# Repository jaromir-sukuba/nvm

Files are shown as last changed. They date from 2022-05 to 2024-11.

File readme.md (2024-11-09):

***Please note this nanovoltmeter design was superseded by a new and better design, which will go public in [this Github repository](https://github.com/jaromir-sukuba/nvm2). Soon(TM)***

## What is in this repository?
Here is the complete set of design files, manufacturing data, source files, test results and other resources that I used in the process of building a nanovoltmeter. This process was not a coincidence, but a response to the nanovoltmeter challenge by TiN on [his website](https://xdevs.com/article/nvm_comp/)
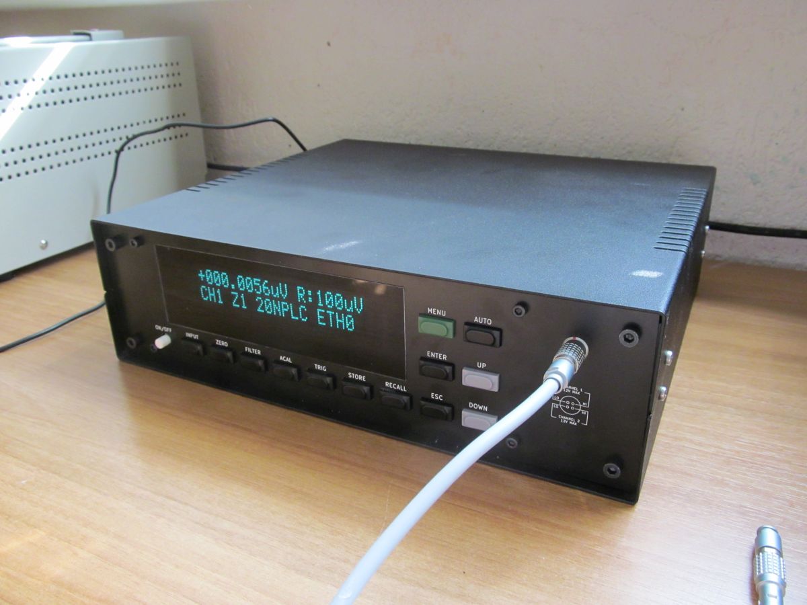
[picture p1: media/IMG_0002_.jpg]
Outside view


## What is a nanovoltmeter and what is it good for?
Well, a nanovoltmeter is a voltmeter that has the sensitivity, noise and stability to resolve voltages down to the nanovolt. While many multimeters do have quite sensitive low voltage ranges, the resolution (least significant digit) is usually in the order of hundreds of nanovolts - and value of this last digit is often diminished by the noise and nonlinearity of the meter. So, for proper low signal measurements, having a higher sensitivity is mandatory.
Measurement of such low voltages is useful for many applications, for example resolving small voltage differences in various differential and bridge circuits and the measurement of very small resistances - with an appropriate current source.
Commercial nanovoltmeters do exist, like the Keithley model 2182A or Keysight 34420A, but with a hefty price tag, so a DIY design definitely has its place.

## xDevs challenge
While I have been tinkering with DIY test and measurement tools for a while now, I never had an impulse to discover the nanovolt world. Such a trigger happened on September 2nd, 2021, when TiN from xdevs site launched the [nanovolt challenge](https://xdevs.com/article/nvm_comp/). In nutshell, it called for the design of an open-source nanovoltmeter, with parameters comparable to commercial designs and a timeframe of 256 days. That is a non-trivial task, and in my case it was even more so, because I had not only never designed low signal circuits before, but had I never operated a nanovoltmeter. That is quite an unfavorable starting position and jumping into the deep end rather than dipping my toes into the problematics. To ease my mind, I waited a few days to see how others reacted on the [eevblog forum](https://www.eevblog.com/forum/metrology/nanovolt-design-challenge-build-and-show-your-own-nv-meter-in-256-days/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). I can't say that it encouraged me.
On the other hand, I spent a few days researching online sources and studying the service manuals of proven test gear from reputable vendors. Too bad they stopped supplying us with schematics in early 90s of the last century; but even that material was very helpful in understanding both what the requirements are for such a meter, as well as the means to achieve it.

## NVM design, part 1 - design requirements
Armed with new knowledge I started dissecting the challenge requirements. 

> Have local onboard power regulation. Single common DC (+9 to +24 VDC) or 110/220VAC mains input jack is expected.

Okay, I think I can do this. On the other hand, any reasonable mains-powered voltmeter has to have an isolated PSU section which powers the input dividers/amplifiers and ADC, so that the measurement potential could be unrelated to the digital section with all the user and communication IO - which is needed to be earthed or somewhere close to that potential.
This one calls for either DC or AC power, but it could be combined by having a PSU operating from an appropriate DC voltage (12V sounds like a good starting point) and attach a small AC/DC SMPS to provide power from mains.

> Provide DC Voltage measurement ranges ±100 µV or below and include ±1V and ±10VDC range.

This one looks innocent, but having both 10V and 100uV input on the same jacks implies either switching input amplifiers, or inserting a voltage divider into the signal path, preferably through a relay. Some older nanovoltmeters (Keithley model 181) had two different inputs - one for higher ranges, another one with low TEMF connector for sensitive ranges.

> Have at least two user-accessible input channels for signal to be measured.

Oh my, another relay. Relays are good, but may introduce offset errors into signals due to thermal voltages (TEMF, short for Thermal Electromotive Force) generated on the contacts, when the relay heats up from coil power. The voltages may be around a few microvolts down to nanovolts, definitely something to consider in this design. TEMF is the main enemy of the nanovoltmeter and this acronym will be used in following text a few more times.

> Have low-thermal connection interface to minimize thermal EMF parasitic errors.

TEMF again, I told you so.   
  
> Provide at least 5½-digit resolution for each reading.

Sounds reasonable. I've done long-scale ADC projects like [voltmeter](https://www.eevblog.com/forum/metrology/diy-6-5-digit-voltmeter/) and [voltohmmeter](https://www.eevblog.com/forum/metrology/diy-6-digit-handheld-volohmmeter/msg2978912/#msg2978912) so perhaps I could recycle something and also bring something new to the table. I think commercial sigma-delta A-to-D converters would do the job too, but a DIY ADC definitely has more to it.

> Ability to digitize input DC signal with resolution at least 10 nV and noise better than 30 nV peak to peak over at least 0.1-10 Hz bandwidth.

More numeric requirements, nice. 30nVp-p in 10Hz bandwidth is not a very relaxed requirement - older meters like Keithley model 181 would not cut it, current models so-so.

> Have autozero functionality to correct for static offsets.

That is a logical requirement. I will put in some more effort by introducing autocalibration.

> Have galvanic isolated analog front end, with isolation resistance to earth/chassis better than 10 GΩ.

That is what I proposed earlier, too. 

> Device should have ADC (any type) integrated.

This is likely to frame the project into standalone modus operandi.

> Have good long-term stability and use ovenized DC voltage reference (LM399, LTZ1000 or LTFLU with oven).

I wouldn't think of using anything worse than an LM399 (or ADR1399) anyway.

> Provide RJ45 Ethernet and/or IEEE-488 GPIB interface for communications with external world / external equipment.

Fair point. USB is simpler, though.

> 40W total input power budget (friendly to battery operation for sensitive experiments)

You wouldn't want your nanovoltmeter to consume more than 40W anyway. 40W is quite a bit of heat and it's not easy to dissipate it without introducing more TEMF errors.

> Device should be fully operational as standalone device (e.g. no debuggers or external equipment attached to make it work).

OK, fair.

After a bit of optimization, I came up with this block diagram.
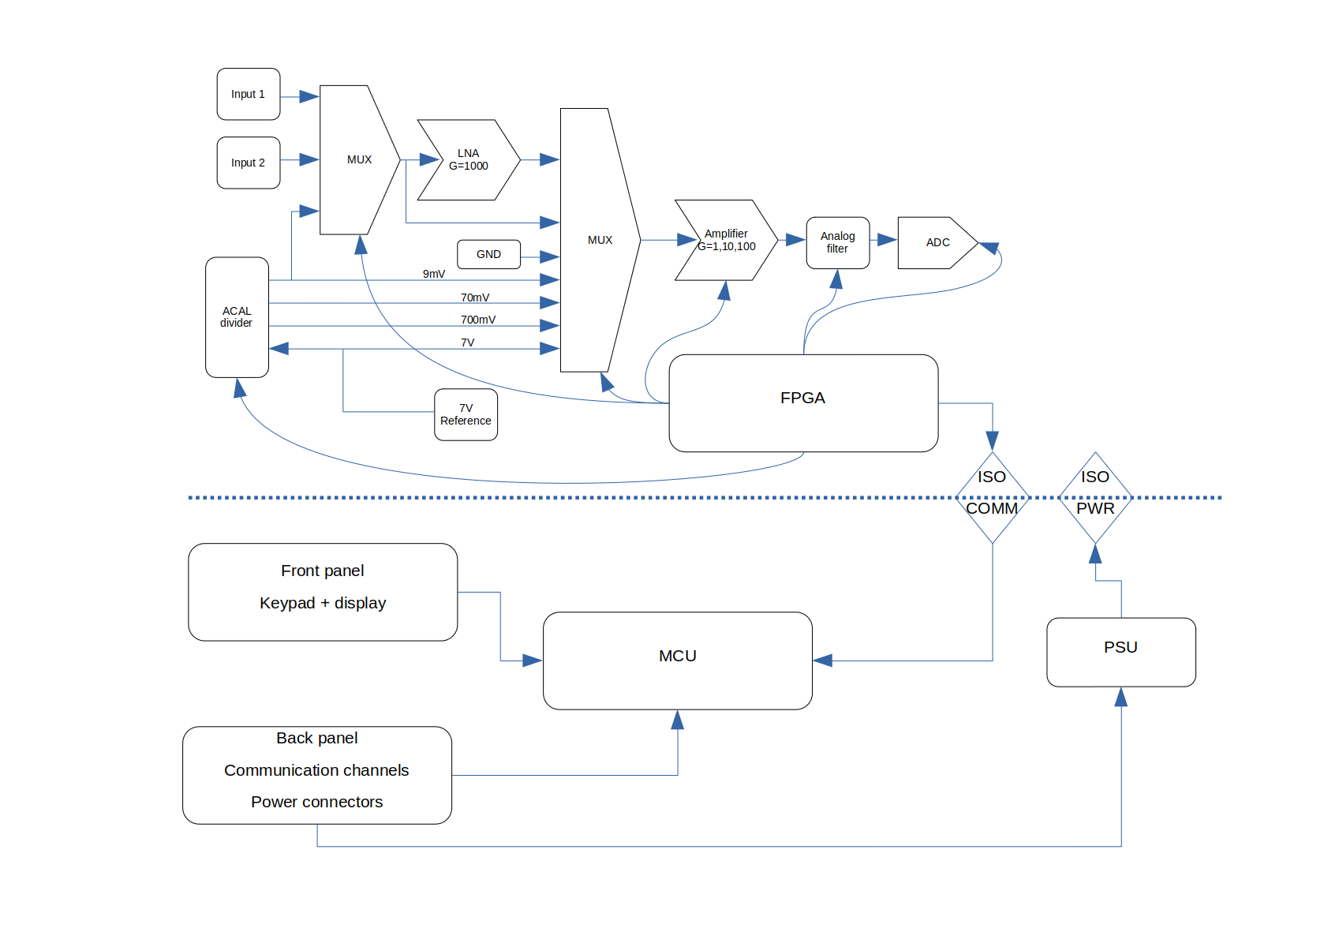
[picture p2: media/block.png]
Block diagram

It's basically done to fit the requirements above, with a few spicy parts I added for extra fun.
Input from either input connection is selected via an input multiplexor. There is also a third input, to be discussed later. This MUX passes the selected channel to a low noise amplifier (LNA) to be amplified and then routed via another MUX into the main amplifier. whose output is brought to the ADC. This ADC has a nominal 10V input range, so that the basic range with LNA is 10mV (10mV x 1000 = 10V). In order to have even more sensitive ranges, the main amplifier has option to switch to x1 (pass-through), x10 and x100 gain, combined into additional 1mV and 100uV ranges. When the LNA is bypassed, the input signal is brought directly to the main amplifier, allowing for 10V, 1V and 100mV ranges, seamlessly covering 100uV to 10V input range. That would make a nanovoltmeter already, but I added two more blocks - first is easy, a low-pass filter (also known as LPF) to cut down noise, especially on sensitive ranges. Another one is an auto-calibration block, which serves to decide the gain of both amplifiers. Ideally, the meter needs only to know its onboard 7V reference voltage and can derive lower ranges automatically without calibration/adjustment and keep it precise after resistors in dividers and amplifier drift due to age or temperature.
The entire upper portion of the circuit is held behind an isolation barrier in order to keep the input terminals separated from the power supply potential - either external DC or mains voltage. The bottom section consists mainly of the PSU and digital circuitry, including user IO and communication channels, like Ethernet and USB. For the added fun factor I also included GPIB as a low priority subproject.

## NVM design, part 2 - divide and conquer

Designing such an instrument, especially on a DIY base, is a lot of pingponging between mechanical and eletrical design. I could imagine how large the thing would be (say, an A4 page size as a footprint) and I knew I had to cram everything inside. Choosing a larger enclosure would give me much more freedom and other benefits (like easier dissipation of device heat, helping fight TEMF), but would be impractically large. Finding an appropriate enclosure wasn't easy - at first I thought of using G756 I used before in my [DIY SMU](https://github.com/jaromir-sukuba/J-SMU), but I preferred metal enclosures here - because of shielding from electrical interference, and with a steel enclosure even a bit of shielding from magnetic interference. Metal also helps with heat dissipation. Finally I settled on the 1EP802825 from Modushop.
That was the right time to take a look at the electrical domain. The Earthy and floating parts (separated by an isolation barrier) have to be physically separated in sub-enclosures (that calls for two PCBs minimum) and in order to have easier debugging and modification of the circuit, I decided to separate the floating part into two PCBs. One would hold FPGA control, the reference and ADC, while another one would consist of both amplifiers and ACAL circuits. Since the enclosure is 80mm tall, there is no problem stacking at least two PCBs on top of each other, via pin headers and metric spacers.
So, two PCBs for the floating part, one for the earthy part. The backside connectors have to be mounted somehow - here I added another PCB. The front panel pushbuttons also needed a PCB for mechanical reasons, that resulted in a total count of 5 PCBs. I named the PCBs with human names and gave them functionality:

**Bart** - I felt like this one will be tricky and there will be problems. Contains LNA, main amplifier, ACAL dividers and MUXes.  
**Homer** - largest PCB, contains FPGA, ADC, references. Closely related to Bart.  
**Lisa** - communication board, back panel PCB  
**Meggie** - simplest PCB, just to hold buttons  
**Marge** - contains PSU to feed all other PCBs, plus digital circuits.  

With the electronics roughly separated into basic blocks, I returned to mechanical design. By the time I finished first sketches of the schematics files, I received the enclosure, so I could start with more practical details. It's much easier to visualize potential problems having the real enclosure in hand compared to studying 3D files (if any, right). For circuit separation I opted for two sheet metal sub-enclosures.
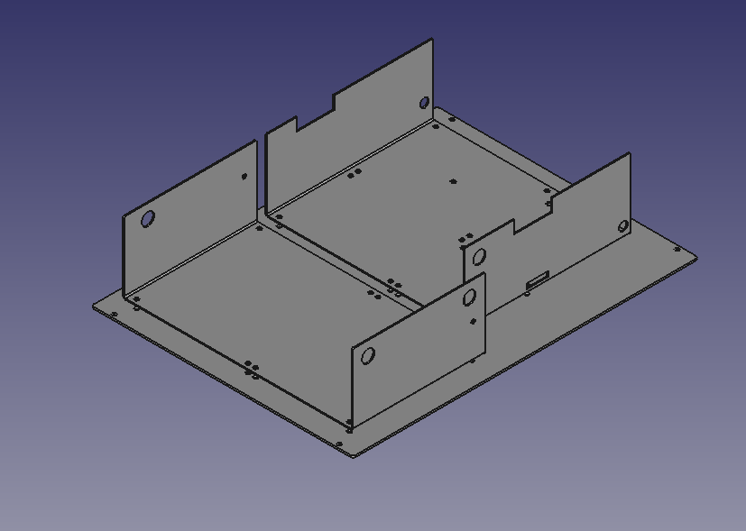
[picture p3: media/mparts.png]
Internal metal parts
. The smaller portion on right holding analog circuitry, the left portion holding earthy circuits - it's somehow shorter, to make room for a backpanel PCB.
I designed a bunch of holes into the enclosures to allow mounting PCBs via metric spacers, and now having physical constraints, I jumped back to PCB design.

## NVM design, part 3 - selected details of circuit operation
In this section I'll discuss a few selected design choices of this instrument.
#### LNA (Bart board)
I went through a few design iterations of the LNA and it took me roughly half of the development time. I tried DC-coupled JFET amplifiers, AC coupled JFET amplifiers in chopper configuration for DC operation as well as paralleling opamps. The parallel configuration brought me the least amount of headache and despite the insane amount of components used, it is not that expensive after all. As best in class, IF3602 JFETs are both expensive and suffer by huge parameter spread, making them quite an expensive solution. There are cheaper JFETs around, but their noise parameters mean more paralleled pieces - with problems they bring, for example binning and matching. More transistors or fewer low noise types also bring more gate capacitance, requiring more circuit support to diminish its influence. Enclosing the amplifier into chopper configuration brings more issues to solve - for example I had to deal with input current and temperature gradients increasing voltage offset. It's very likely that all those problems are solvable with more time and effort and would make an LNA with lower noise and drift than what I have in the current NVM, but at some point I decided to go a different way and built the LNA out of massively parallel off-the-shelf opamp amplifier. Integrated autozero/chopper opamps do have much better temperature stability and input current, so after a bit of searching and comparing I opted for MCP6V51 from Microchip, as the one with very good price/performance ratio. Typical input noise voltage is specified at 210nV in 10Hz bandwidth and I confirmed this experimentally by building a 35 piece opamp board first. 
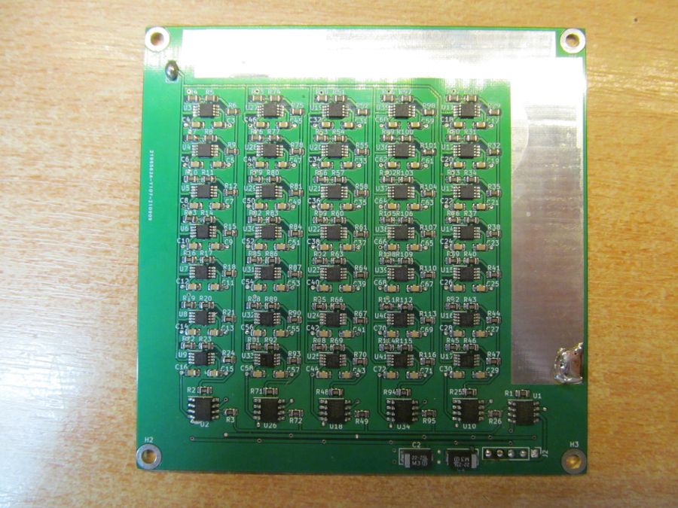
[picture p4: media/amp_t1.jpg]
Amp35

The noise parameters were in good agreement with the datasheet values, that gave me confidence to go this way. As calculated, I need at least 50 MCP6V51s to get under 30nV p-p criteria, so I opted for 100 pieces, in 10x10 matrix, as per the schematic below
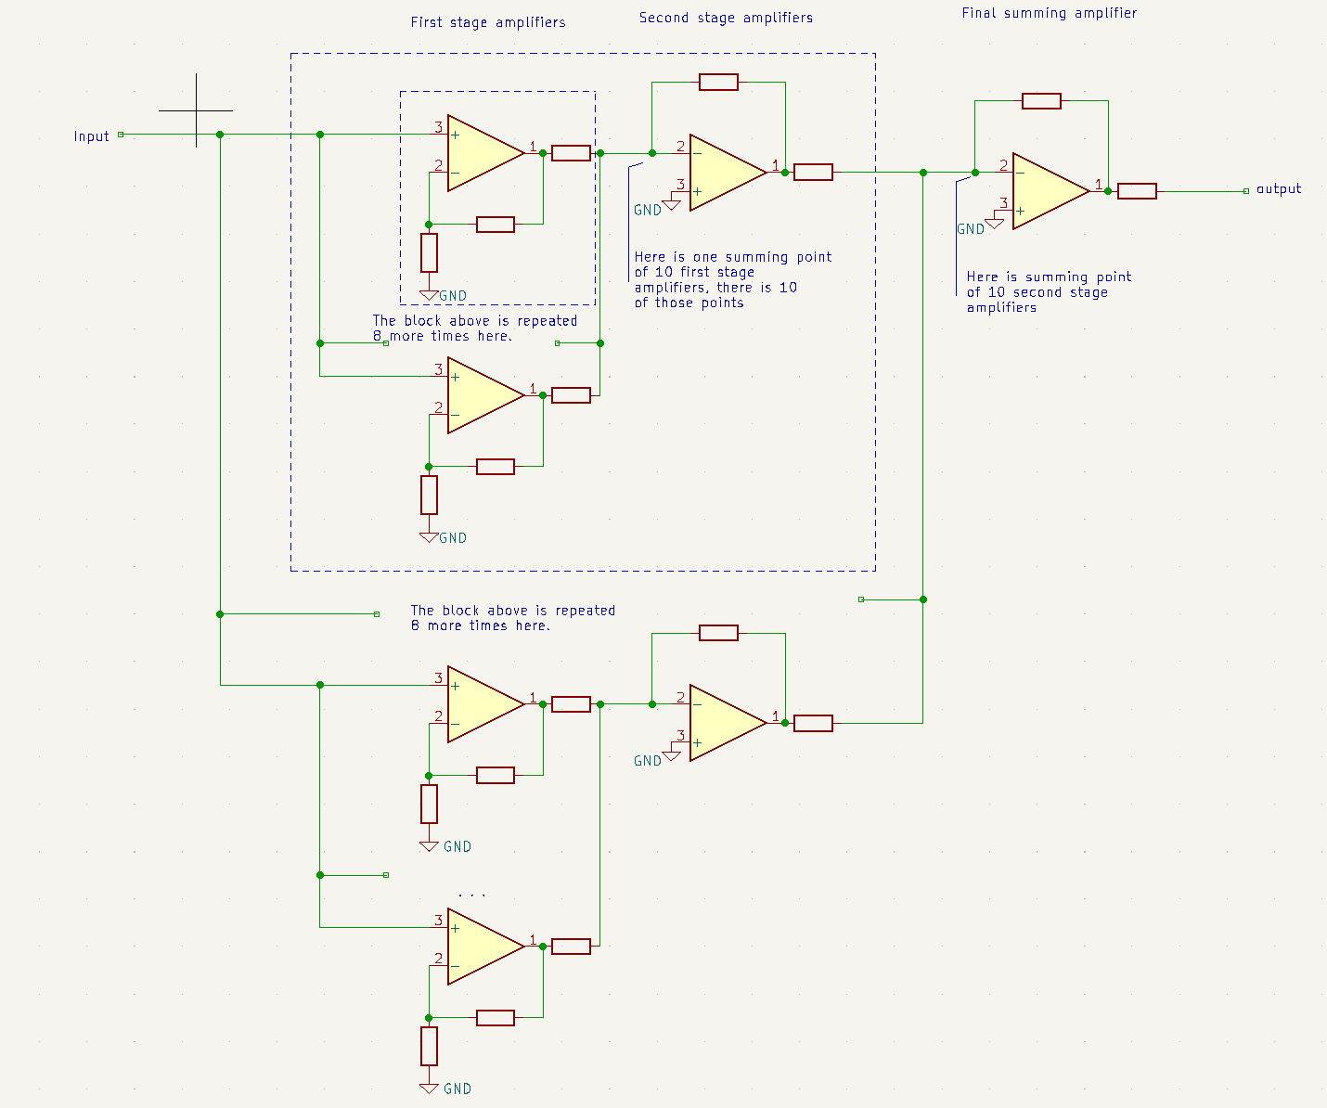
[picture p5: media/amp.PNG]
LNA diagram

Each of the first stage gain blocks (with 10 amplifiers in parallel noninverting configuration) is brought to a second stage summing amplifier, and all 10 of the second stage amplifiers are summed into a third, and final, amplifier, with an overall gain of 1000.
The last stage summing amplifier is also used to inject a voltage to null the offset voltage of LNA. The Bart board has a DAC and its amplifiers (U119 and U120) for this reason. The DAC's second channel is designed to compensate for input current - by injecting a current of opposite sign into the LNA input. I measured the uncompensated current to be around 2nA and in my current hardware the injection resistor isn't fitted on the board. By using this feature, I expect a current well below 100pA.
The LNA injects ground current into the ground net of the circuit, and the current is dependent on input voltage (and therefore output voltage, too). Ground current may cause unwanted voltage shifts between ground potentials of the circuit, especially at high gains. To counteract this ground current, amplifier with U121 is set up to source current of opposite polarity into the ground, into areas where the LNA resides.
The Bart board is 4-layer, with internal layers being ground nets, for both electrical and thermal reasons.

#### ADC (Homer board)
The ADC is of the integrating, charge balancing type with residual integrator voltage reading. SN74LV4053 is used for integrator current steering, the integrator is of the classic two opamp composite type. The FPGA does multiple jobs here, apart from orchestrating actions around the ADC, it also provides an interface between isolated serial link and multiple digital outputs used to switch relays, multiplexer and analog filter and does startup timing for smooth PSU startup.
I measured INL of ADC against a Solartron 7081 as reference. A 0-10V voltage sweep was provided by a DIY precision voltage source (LTZ1000A reference, AD5791B DAC). Measured INL graph:
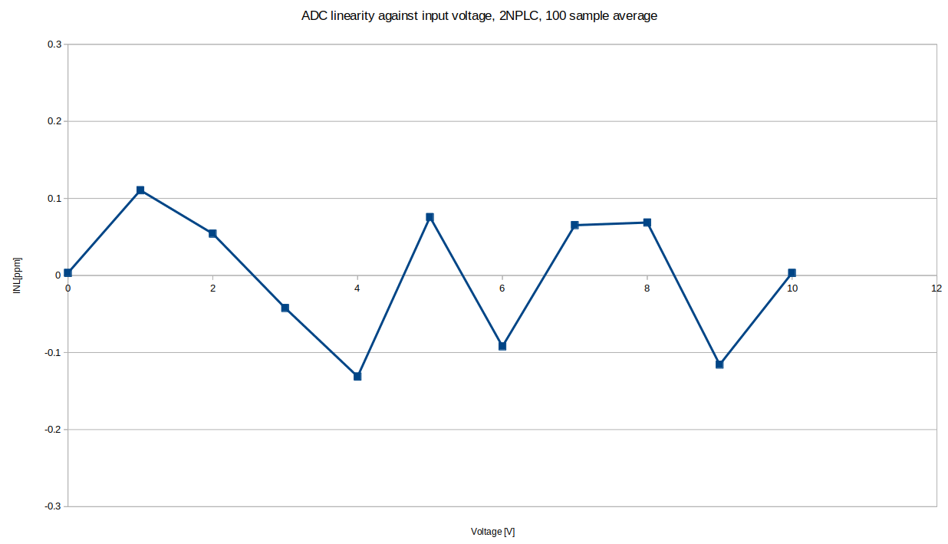
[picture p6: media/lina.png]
ADC INL graph

The INL of this magnitude may not be obviously needed for this application, but I wanted to employ ACAL functionality, where voltage transfer between ranges expects good INL of the ADC, so I was after good linearity and spent some time honing it.

#### PSU (Marge board)
My first idea for the PSU was to use two back-to-back 50Hz transformers. One would provide a few volts (providing first isolation barrier and ground reference) and the second would step it up to the level appropriate for +-16V and 5V DC outputs. Later I expended this idea by using an audio frequency amplifier circuit to feed the second transformer and omitting the first transformer. Using an AF amplifier (fed by an appropriate oscillator) to drive the transformer has a few advantages - the whole circuit could be powered from a single DC voltage and the oscillation frequency can be adjusted to find a good compromise between leakage and efficiency. Using classic linear amplifiers would bring way too much thermal dissipation into the enclosure, so I opted for the cheap and plentiful TPS3116 D-class amplifier. The oscillator signal - either from a local single opamp multivibrator or amplified signal provided by the MCU - is shaped by a series of lowpass filters, so that the amplifier is fed by a low harmonic content signal. Transformer secondary is brought to a fairly standard set of regulators - LM317/337 and 7805.
I measured ground leakage from the isolated PSU section and its efficiency as function of driving frequency.
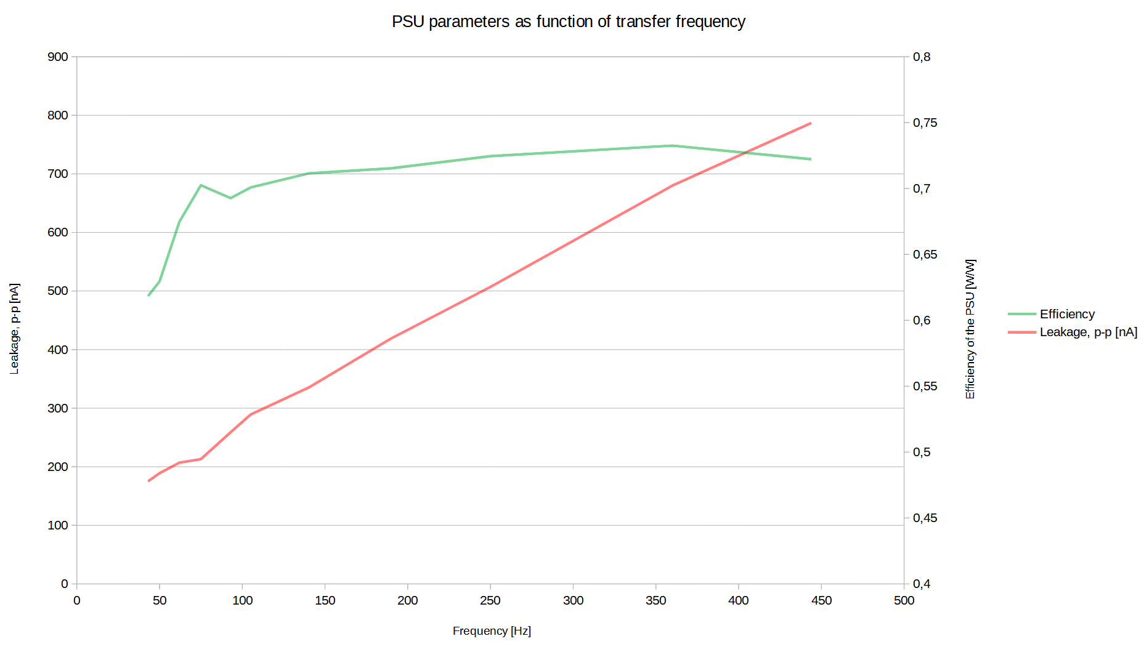
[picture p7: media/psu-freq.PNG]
PSU graph

As per expectations, a lower frequency also brings lower leakage current, but going too low causes efficiency to plummet at some point. I opted for 48Hz, where I measured leakage well below 200nA p-p. At this level, leakage measurement is very sensitive to nearby electric fields and conducted interference. After enclosing the test setup in a shielded box, the measured leakage fell to 40nA p-p, indicating the previous measurement was too pessimistic. I believe even the 40nA figure is pessimistic still and influenced by the shielding setup and the oscilloscope I used. For proper test results I'd need a larger shielded cage and a battery powered oscilloscope, but I didn't want to go that far.
The PSU design brought interesting detail to the game. In case of overload, TPS3116 will turn off the load drive. That sounds innocent, but may be problemtic in this case - because after powerup the reference is cold, so the heater takes a significant amount of current during powerup. To add insult to injury, all decoupling/bulk capacitors are discharged, even more increasing the powerup current spike. The spike causes TPS3116 to shut down for a moment, then it tries to restart the load, ending up in the same large spike, repeating again and again.
To mitigate this issue, two fixes were made:
 - PSU driving starts from higher frequency, slowly (over course of a few seconds) it descends to the final 48Hz value. Voltage on the isolated secondary ramps up much slower, allowing circuits to power up smoothly.  
 - Voltage reference heating current (large current spike when left untreated) and LNA power supply voltage is held off until 10 seconds after FPGA power gets stable, at which point heater current is enbled, and LNA power turns on two seconds later.

## Mechanical parts
While the enclosure is centered around the Modushop enclosure, a few more mechanical parts were needed.

#### Reference cover
This two-part 3D printed component prevents airflows around ADR1399 reference, decreasing its noise somehow.
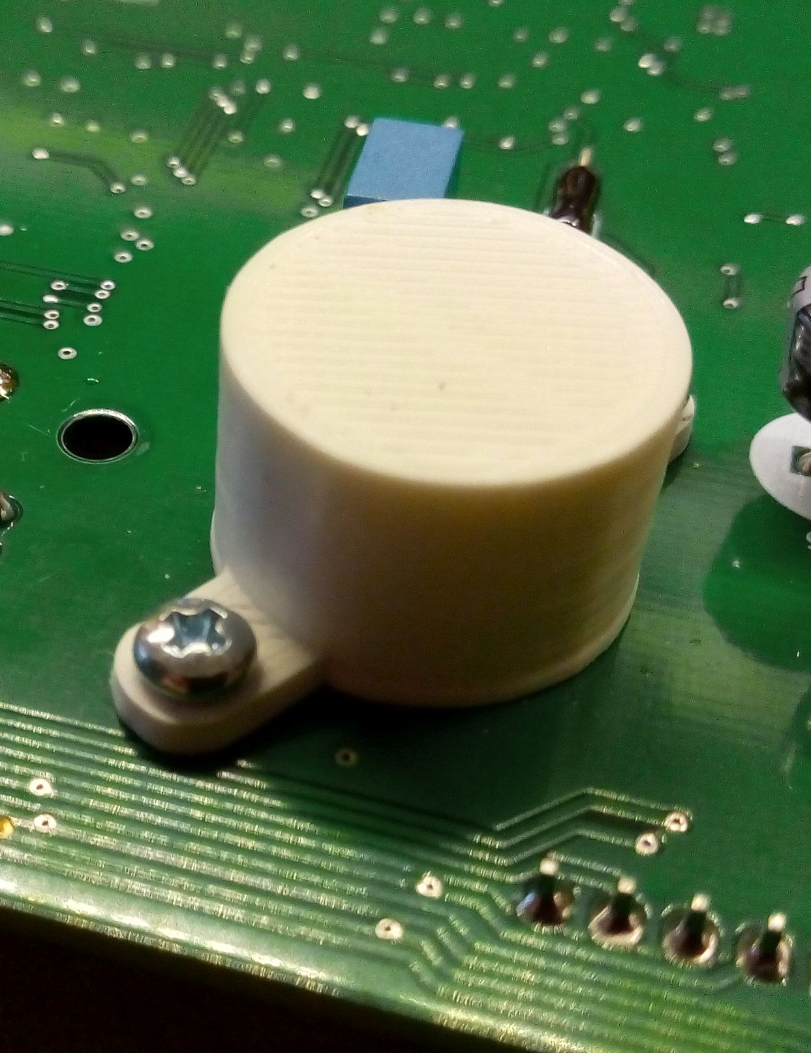
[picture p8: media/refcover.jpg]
Ref cover

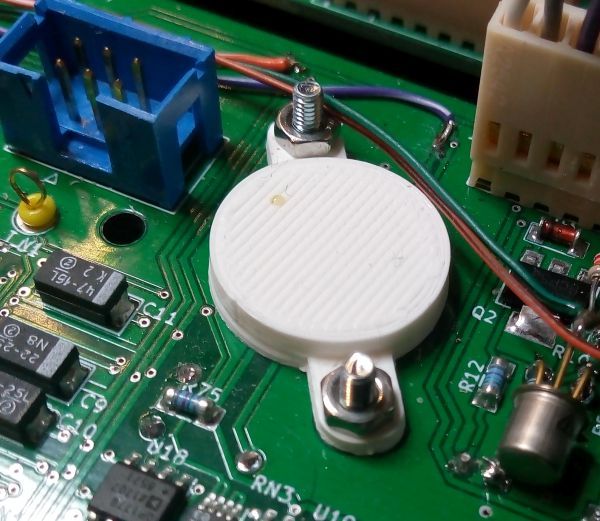
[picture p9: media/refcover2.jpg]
Ref cover


#### Lisa board holder
This 3D printed component keeps Lisa board in its place on back panel.
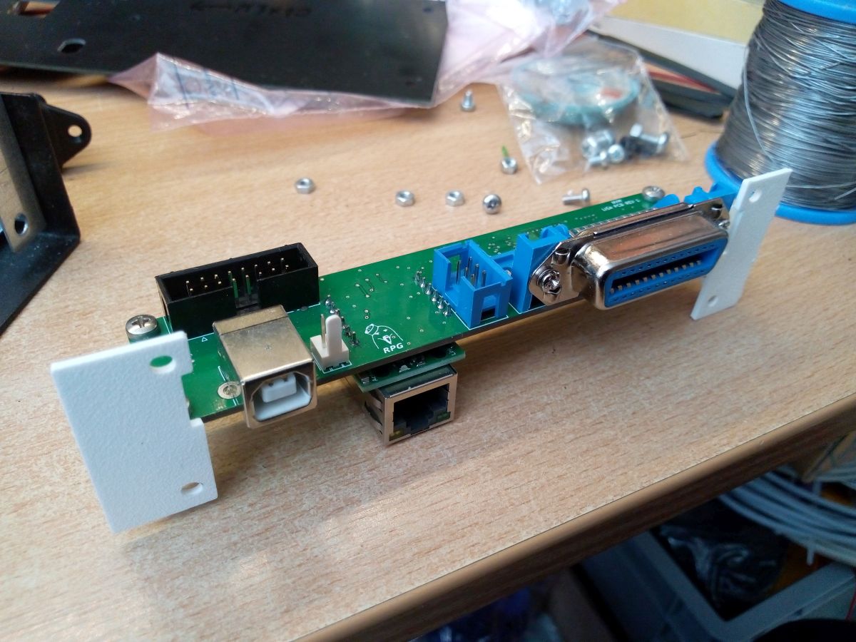
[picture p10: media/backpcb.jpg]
Back holder

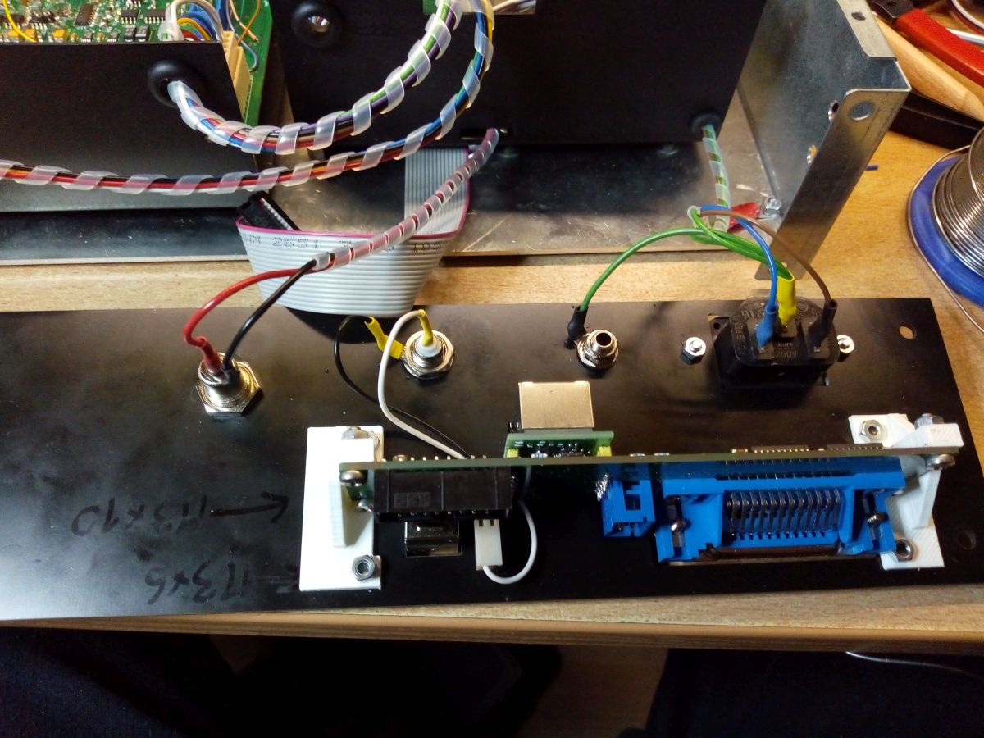
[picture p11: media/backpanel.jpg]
Back panel


#### LNA cover
This 3D printed component provides insulation of LNA board area from airflows.
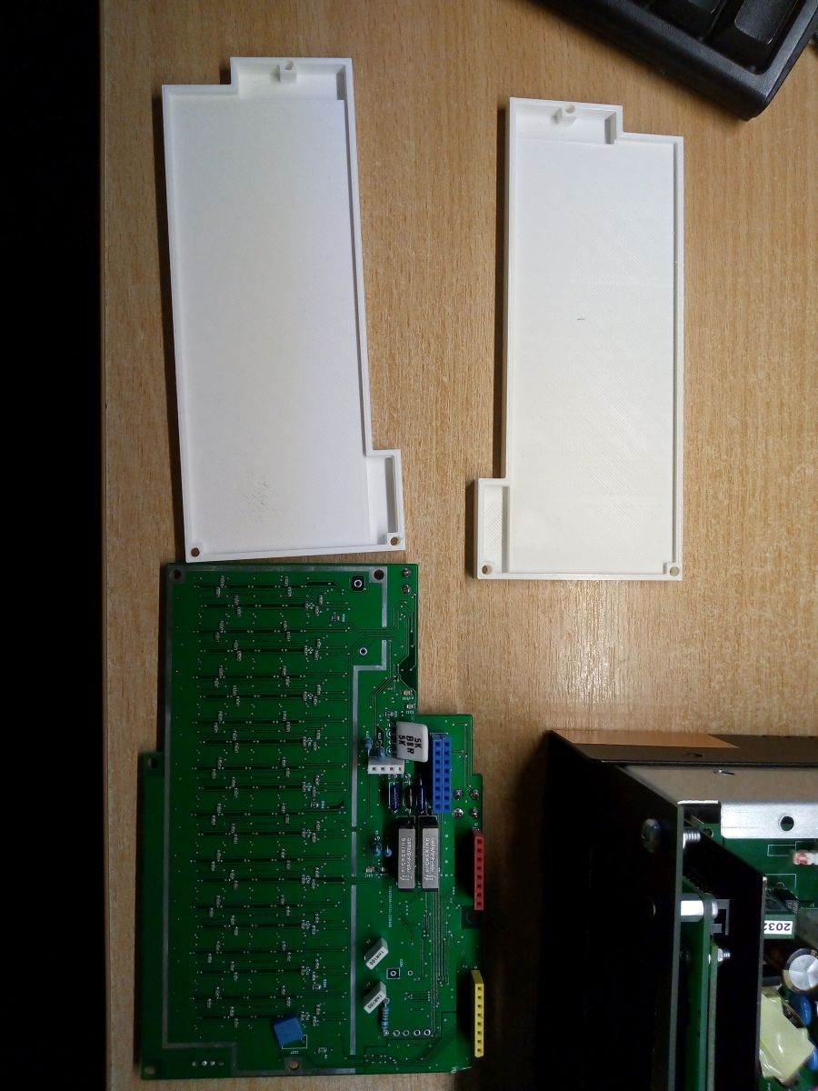
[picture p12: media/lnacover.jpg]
LNA cover

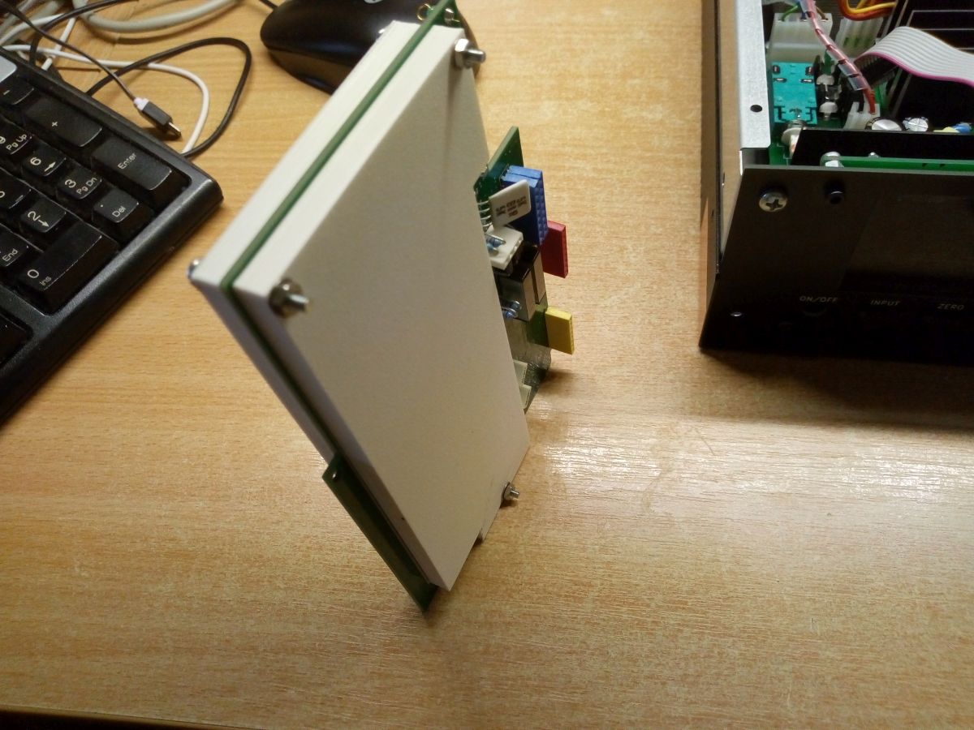
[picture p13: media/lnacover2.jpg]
LNA cover 2

The amount of influence on the readings was suprising to me. Here are two graphs of the shorted input measurement, one with cover, one without, the RMS noise voltage is nearly twofold for naked LNA.
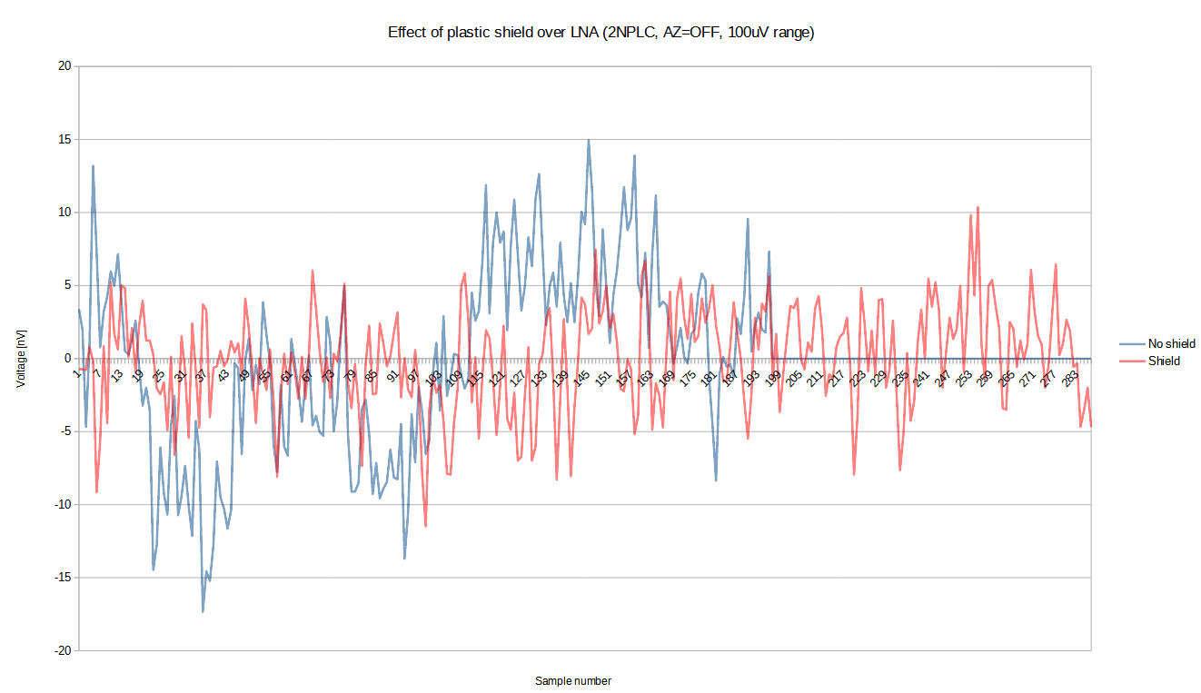
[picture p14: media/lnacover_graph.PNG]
LNA cover graph


#### Side PCB
The original modushop enclosure fitted the outer enclosure panel by screwing to side metal sheets by self tapping screws. I didn't like this, so I drilled the original holes for self-tappers into 3,5mm diameter and mounted dedicated mechanical PCB with nothing but holes and copper plane to solder M3 nuts. This PCB keeps the internal chassis and outer shields in single piece. I think this part would be somehow better made out of >3mm thick aluminium of the same size, with drilled and tapped holes, but PCB seems to work fine for now.
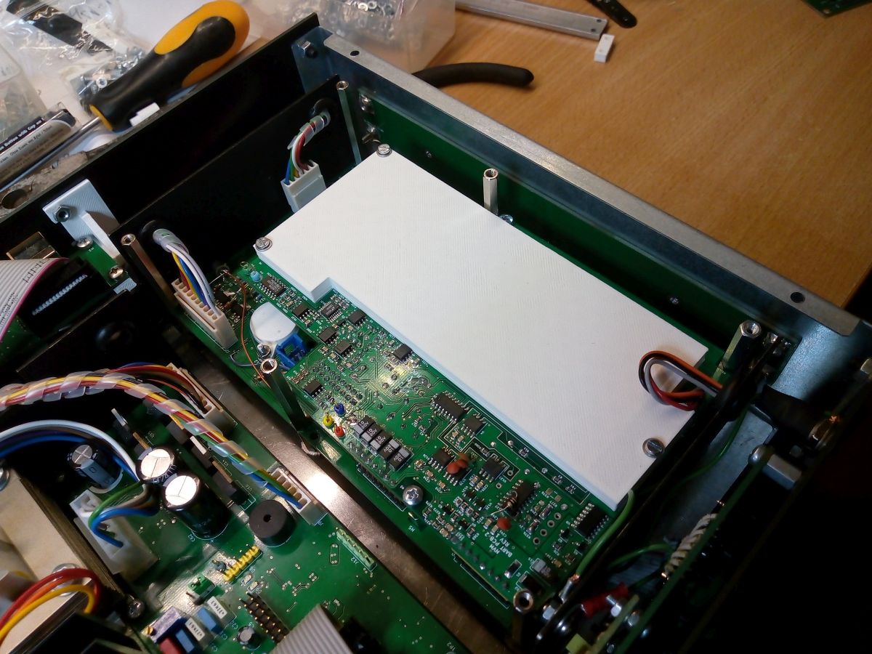
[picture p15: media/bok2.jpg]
Side PCB


#### Push button rod
This is three piece 3D printed component to extend main switch shaft to front panel.  
TODO pictures.

#### Front panel construction
Display cover is epoxied into the front panel cutout, display is bolted to Meggie board and this board is bolted the to font panel.
TODO picture of perspex cutout
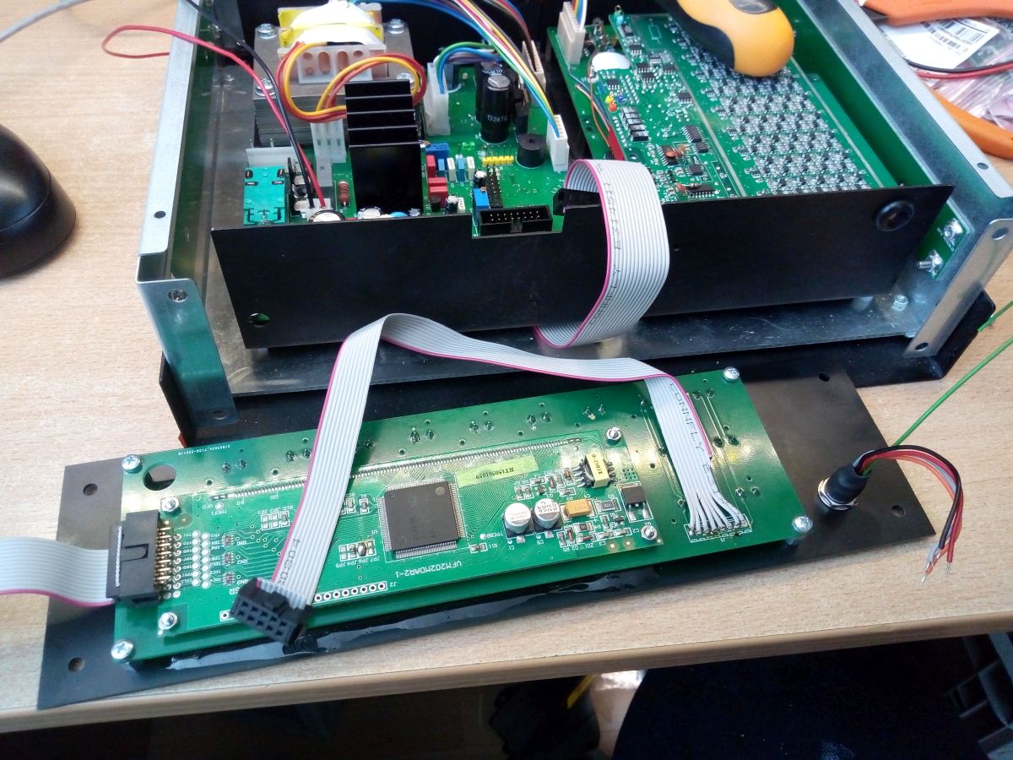
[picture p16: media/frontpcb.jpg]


#### Internal construction details
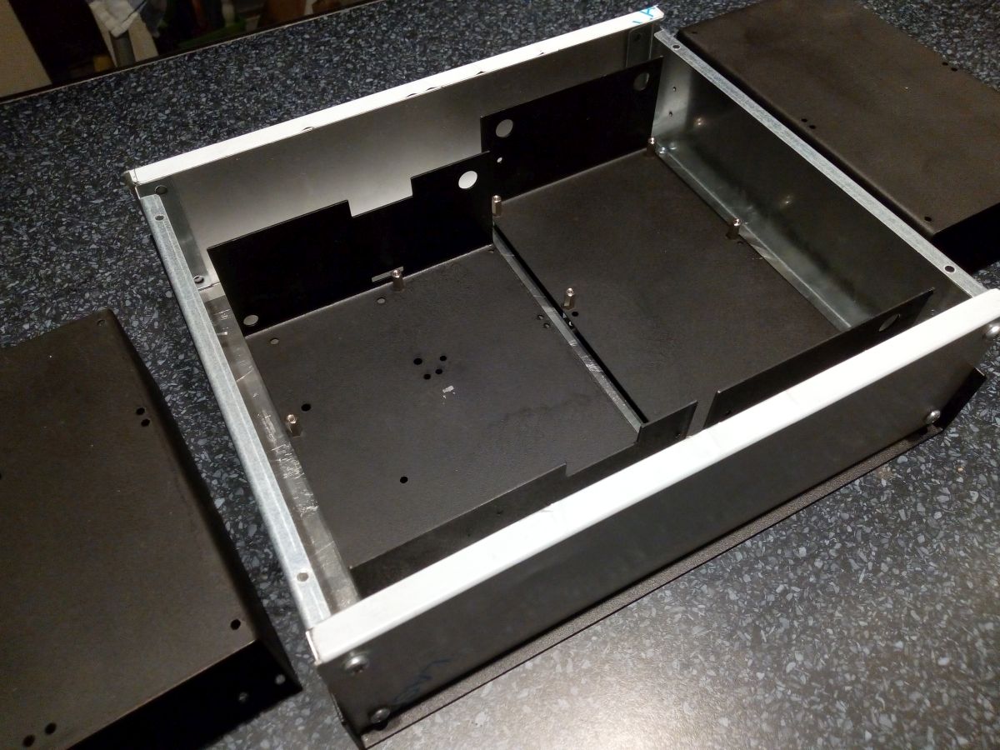
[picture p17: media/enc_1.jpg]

Complete internal construction without top cover
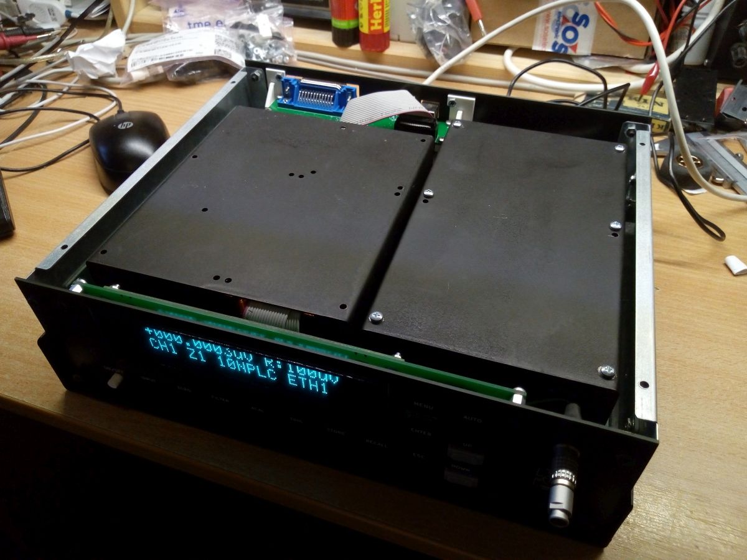
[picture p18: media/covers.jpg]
Covers

Dump of construction photographs is in imgur gallery [here](https://imgur.com/a/fnK1Evj)

## NVM usage
#### Local interface
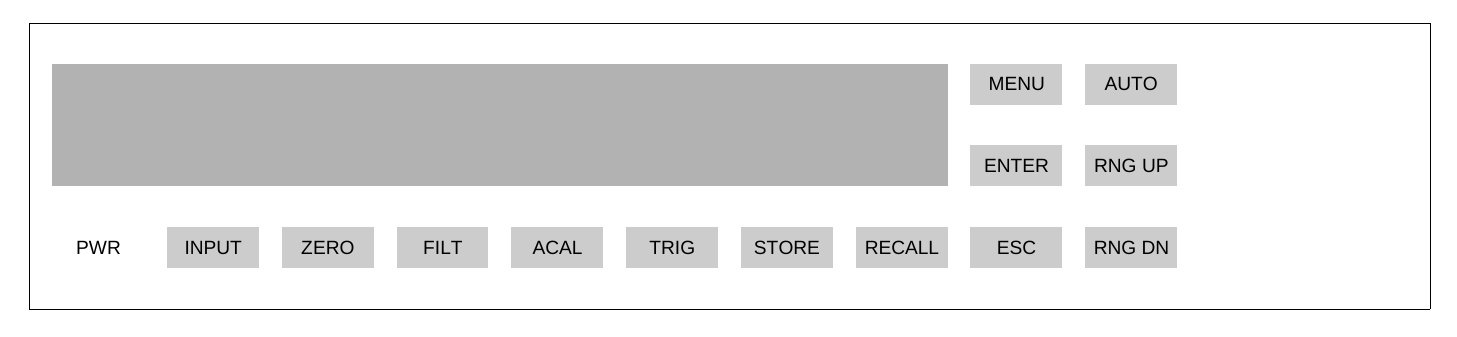
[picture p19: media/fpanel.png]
Front panel

13 keys are provided for instrument operation, plus 2-line by 20 characters vacuum fluorescent display.
After startup the meter enters default (measurement) mode, with settings read from EEPROM. Typical display layout:
Display example
The first line displays measured voltage and range in obvious way.  
Second line in this example indicates following states:  
CH1 - selected channel 1. Could be either 1 or 2.  
Z0 - zero function (see below) is not active on this range. Could be either 0 or 1.  
10NPLC - ADC integration time in powerline cycle multiplies. Could be either 1, 2, 5, 10 or 20.  
ETH1 - Ethernet is connected and IP address provided via DHCP. Could be either 0 or 1.  

Buttons functions:  
**INPUT** - by clicking this button, the instrument toggles between Input 1 and Input 2 on the 4-pin LEMO connector.  
**ZERO** - this function enables zeroing measured value (by subtracting constant voltage offset measured at the instant of enabling the function). Each range has its offset value and is independent of other ranges. Zeroing for given range is disabled by second button press.  
**FILT** - pressing this button displays analog filter, digital filter and NPLC settings. Each hit of the button moves focus to next setting (value is changed by pressing UP/DOWN controls), third hit returns to default measurement display.  
**ACAL** - pressing this button starts ACAL procedure and saves the calibration constants into EEPROM memory.  
**TRIG** - not used in this firmware revision.  
**STORE** - not used in this firmware revision.  
**RECALL** - not used in this firmware revision.  
**MENU** - enables menu. Moving across menu items is done by pressing UP and DOWN keys. Enter enables editing the item value - editing is performed using UP and DOWN keys. Escaping from the menu is possible via ESC button, saving and escaping via MENU button.  
**AUTO** - not used in this firmware revision.  
**ENTER** - apart from function in menu function, pressing ENTER in default mode displays IP address of the instrument (if attached to ethernet). Pressing ENTER again returns back to default state.  
**UP/DOWN** - in menu or filter editing it serves function described above, in default mode it selects higher or lower measurement range.  

#### Remote interface
Instrument could be controlled remotely via ethernet interface, by issuing SCPI-compatible commands.  
\*IDN? - returns instrument identification  
\*RST - resets instrument  
\*CLS - clear status  
SYSTem:ERRor[:NEXT] - lists system error  
SYSTem:ERRor:COUNt? - return amount of system errors  
SYSTem:VERSion? - returns instrument version string  
MEASure:VOLTage? - returns value of measured voltage  
CALibration:VREF - single float parameter, sets value of 7V reference voltage (the only input for ACAL procedure)  
CALibration:VREF? - returns value of 7V reference voltage  
CALibration:UNLock - single integer parameter, locks (0) or unlocks (1) access to calibration EEPROM  
CALibration:SAVe - if access to calibration EEPROM is unlocked, this command saves actual calibration into EEPROM  
CALibration:ACAL - starts ACAL procedure  
SENSe:CHANnel - single integer parameter, sets channel 1 or 2  
SENSe:CHANnel? - returns actual channel number  
SENSe:RANGe - single integer parameter, sets range 1 (100uV) to 6 (10V)  
SENSe:RANGe? - returns actual range number  
SENSe:DFILter - single integer parameter, sets digital filter to 1, 2, 4, 8, 16, 32 or 64 samples  
SENSe:DFILter? - returns digital filter setting  
SENSe:AFILter - single integer parameter, sets analog filter off (0) or on (1)  
SENSe:AFILter? - returns analog filter setting  
SENSe:DIGits - single integer parameter, sets nubmer of displayed digits - 3 to 6  
SENSe:DIGits? - returns nubmer of displayed digits  
SENSe:NPLC - single integer parameter, sets ADC integration period in NPLC cycles to 1NPLC (0), or 2NPLC (1), or 5NPLC (2), or 10NPLC (3), or 20NPLC (4)  
SENSe:NPLC? - returns ADC integration period  
SENSe:AZero - single integer parameter, sets ADC autozero off (0) or on (1)  
SENSe:AZero? - return ADC autozero setting  
SYSTem:BEEPer - single integer parameter, sets beeper off (0) or on (1)  
SYSTem:BEEPer? - return beeper state  

NVM is fully calibrated by ACAL feature. For this it needs to have its reference voltage setup in calibration memory before running ACAL function. The value is accessible only through remote interface and its CALibration:VREF command. If the reference value in calibration memory is outside 6,95-7,3V range, default value 7,05V is assumed. At the moment, individual range calibration isn't supported, but probably will be in future firmware revisions.

## NVM project goals
In this section I'll discuss the performance of this instrument and project goals. 
#### Noise
The main criteria of this project was to achieve low noise at the lowest voltage range. In order to assess this, I logged 20 seconds of shorted input measurements at 100uV range, with no autozero, 2NPLC (integration time 40ms) and 10Hz analog filter on.
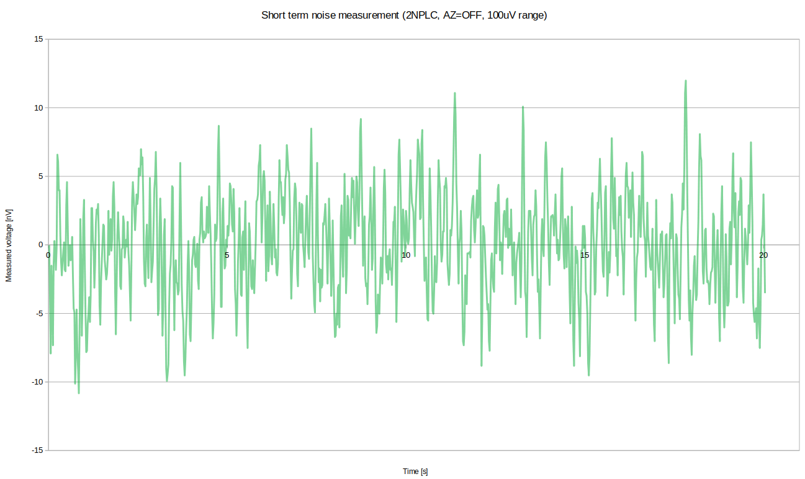
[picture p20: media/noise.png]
Noise graph

The noise is below 25nV p-p.
#### Stability
I recorded roughly 9 hours worth of data with shorted input, while logging ambient temperature too. Meter set to 10NPLC, autozero on, analog filter on. I separated the data into 64 seconds long chunks, averaged it and used as data points. I tried to control the room temperature to obtain some variation.
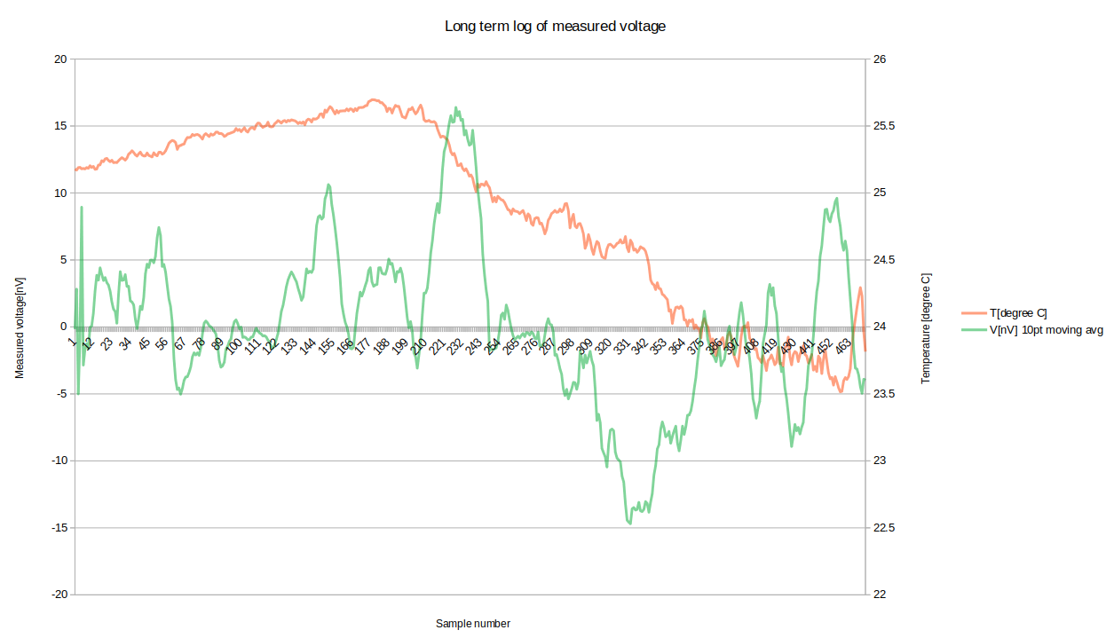
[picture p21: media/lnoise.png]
Longer noise graph

There is no clear temperature dependency. I read the data as sensitivity to temperature changes is perhaps more prominent than the tempco of the instrument.
#### Linearity
I measured the same INL of the NVM against Keithley 2010 as reference meter.
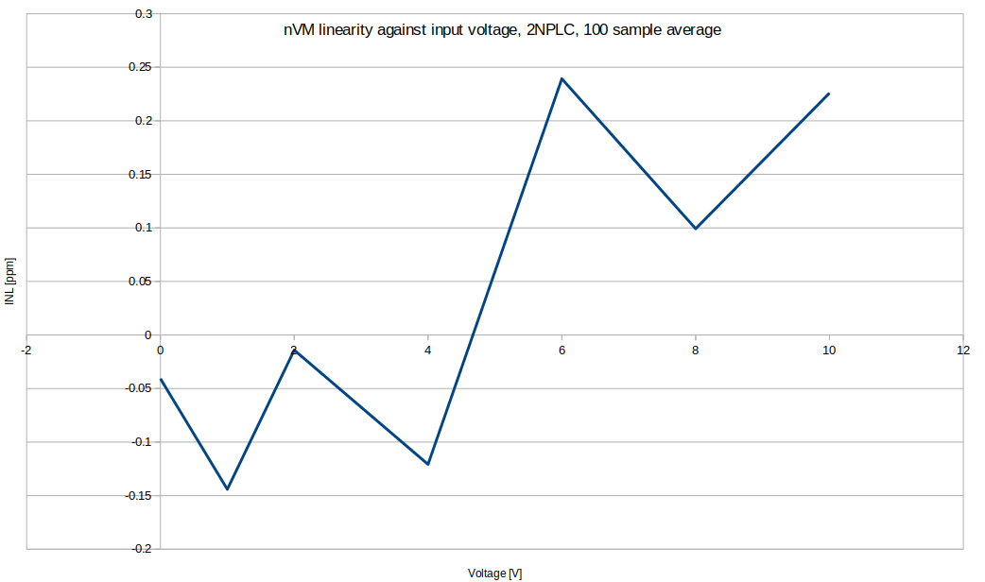
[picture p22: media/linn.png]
NVM INL graph

I believe it lies within acceptable margin for 6,5 digit meter.
#### Bandwidth and normal mode rejection
I measured ADC transfer function for sine input with 1Vp-p amplitude, stepped from 1Hz to 80Hz. Meter was set to 2NPLC, no autozero, analog filter on, 10V range.
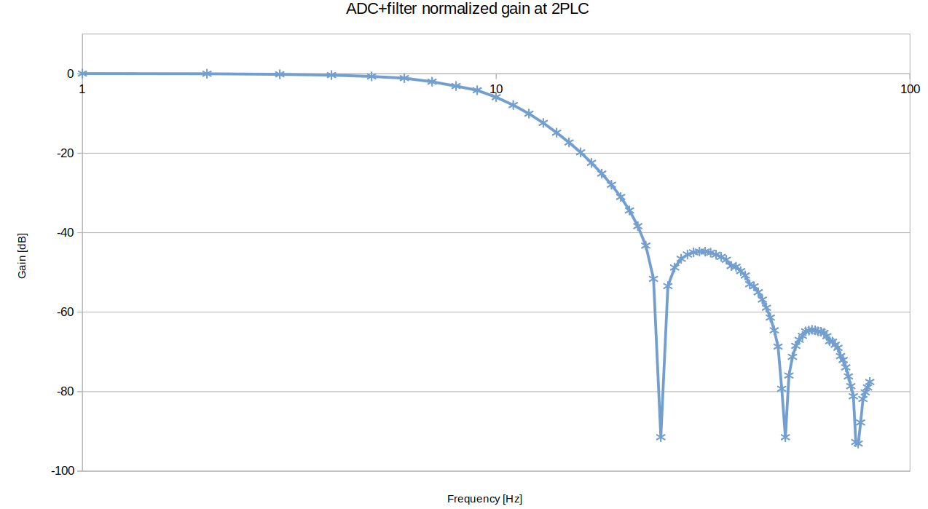
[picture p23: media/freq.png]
Frequency response graph

Resulting bandwidth for -3dB is between 9 and 10Hz, normal mode rejection for 25, 50 and 75Hz is around -90dB
#### Stepping the input with various voltages from Keithley 260 voltage source
Meter set to 20NPLC, autozero on, analog filter on, digital filter=2, 100uV range. Stepping in 10uV steps. The source has undergone massive repair and is out of calibration - but served well as test source to assess linearity and stability of NVM.
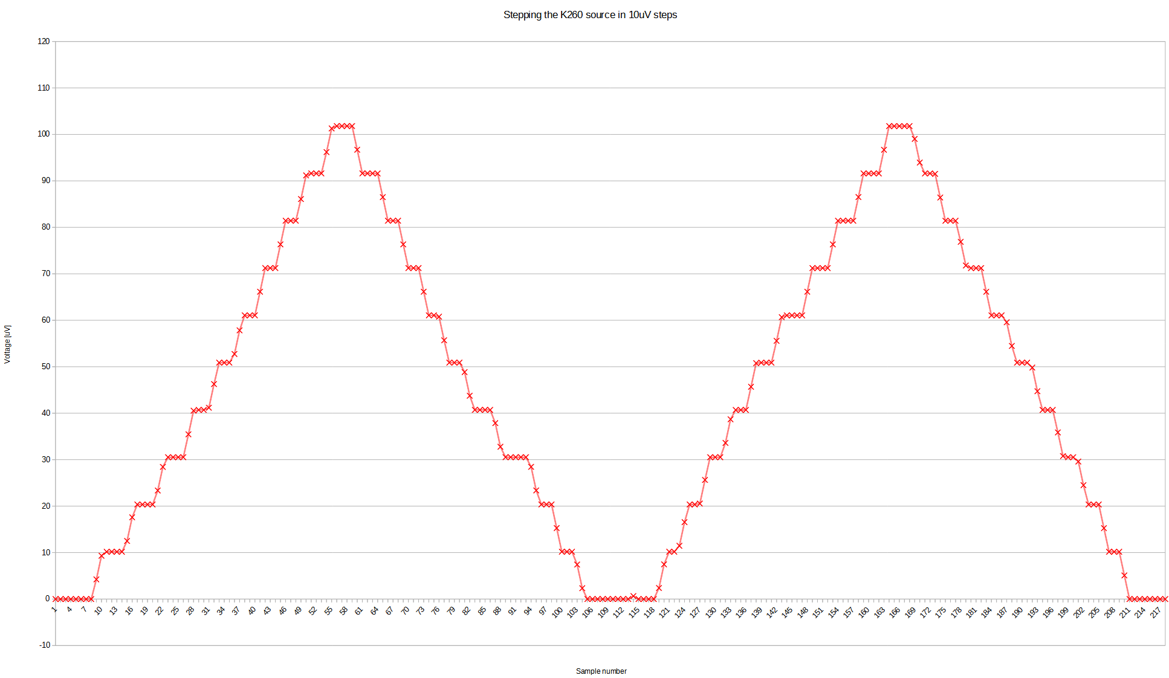
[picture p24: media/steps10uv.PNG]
10uV steps graph

And similarly for 1uV steps. Note that 10uV step is missing, due to bad contact or resistor on Keithley 260 source.
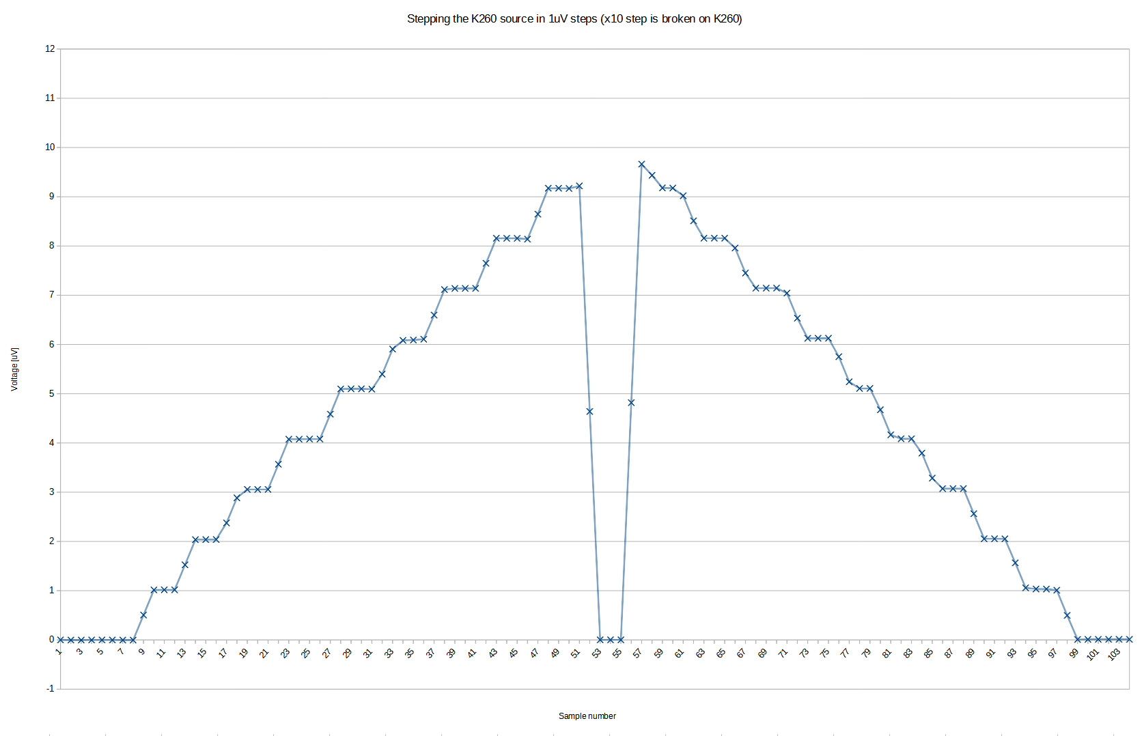
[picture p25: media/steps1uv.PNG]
10uV steps graph

#### Response to 10uV input step with various digital filter settings
Meter set to 20NPLC, autozero on, analog filter on, 100uV range. K260 induces 10uV step on input terminals, response time with various digital filter settings is observed.
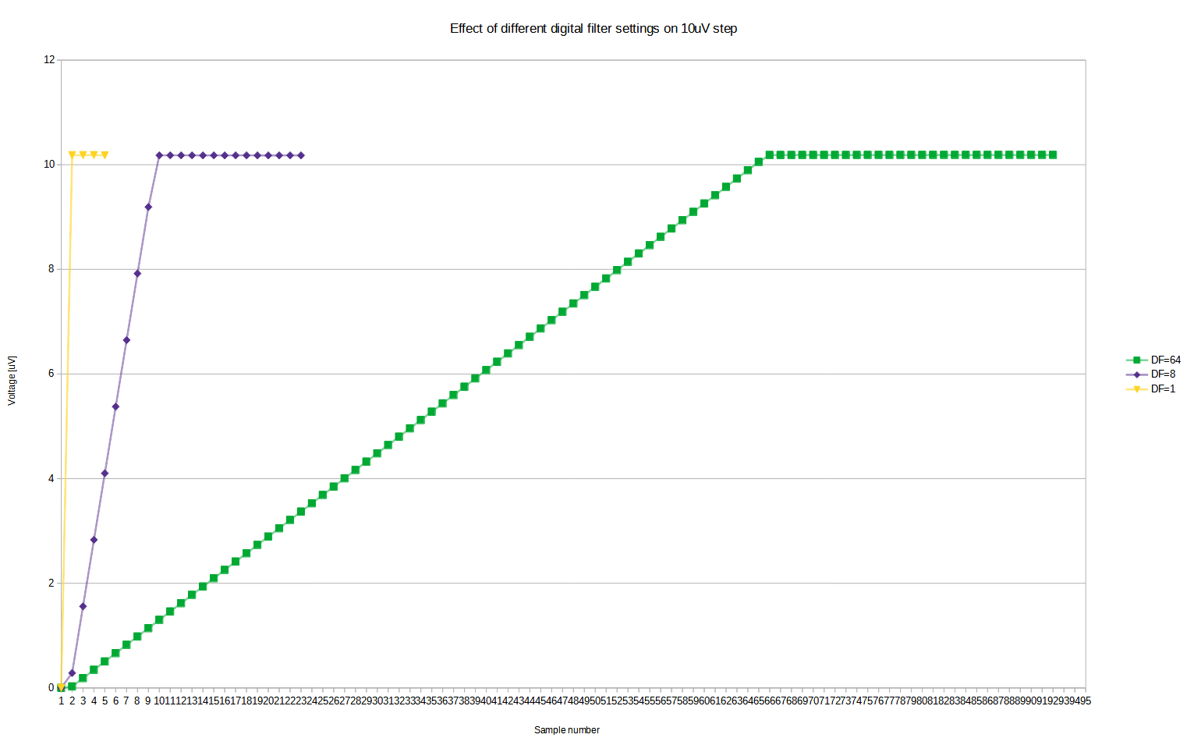
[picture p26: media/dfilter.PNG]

Response is very typical for boxcar average used as digital filter here.

#### Contest goals accomplishment
Now returning back to the contest call:

> Have local onboard power regulation. Single common DC (+9 to +24 VDC) or 110/220VAC mains input jack is expected.

Yes, it works on both DC 12V and 230VAC sources.

> Provide DC Voltage measurement ranges ±100 µV or below and include ±1V and ±10VDC range.

Yes, input ranges are bipolar 100uV, 1mV, 10mV, 100mV, 1V and 10V.

> Have at least two user-accessible input channels for signal to be measured.
> Have low-thermal connection interface to minimize thermal EMF parasitic errors.

Yes, two inputs with reasonably low TEMF LEMO connector.

> Provide at least 5½-digit resolution for each reading.

6,5digit provided.

> Ability to digitize input DC signal with resolution at least 10 nV and noise better than 30 nV peak to peak over at least 0.1-10 Hz bandwidth.

On lowest range and 6,5 digit readout the resolution is 100pV and noise in 10Hz bandwidth is ~20-25nV p-p.

> Have autozero functionality to correct for static offsets.

Yes, autozero and autocalibration provided.

> Have galvanic isolated analog front end, with isolation resistance to earth/chassis better than 10 GΩ.

Analog portion is isolated. Common mode current is apparently below 100nA p-p.

> Device should have ADC (any type) integrated.

I used my own integrating multislope ADC design.

> Have good long-term stability and use ovenized DC voltage reference (LM399, LTZ1000 or LTFLU with oven).

I used ADR1399. Can't assess long-term stability by now.

> Provide RJ45 Ethernet and/or IEEE-488 GPIB interface for communications with external world / external equipment.

RJ45 Ethernet provided, hardware ready for GPIB, too. Apart from that, USB interface is available on board.

> 40W total input power budget (friendly to battery operation for sensitive experiments)

Current draw is 12W.

> Device should be fully operational as standalone device (e.g. no debuggers or external equipment attached to make it work).

No external equipment needed for the meter to operate.

#### Cost and component availability/repairability
Total cost of the instrument components is around 400EUR. All parts I used are off-the-shelf components or are easy to order, with the exception of the power transformer. This is DIY-ed, but I believe many custom transformer manufacturers are able to deliver such a transformer.
Apart from that, I tried to use components with most generic footprints - like SOT23 or SOIC8 for opamps, SOT23 for transistors, most resistors do have a universal footprint able to accommodate MiniMELF (which I used because I wanted to), 1206 or 0805 resistor sizes, used a common display interface and so on. This is to help with alternative component sourcing, a hot topic in 2022, when the component crisis is influencing both professional as well as hobby electronics development and production. Despite my efforts, it's likely that some components in the BOM lists will be unavailable with usual vendors and it's hard to make future-proof designs in this respect.

## Future plans
There are a few features the meter hardware is supposedly able to do, but are not implemented at the moment and I consider this a TODO list for future work on this project.
- implement main frequency synchronous measurements. Zero-cross detector is already fitted on Marge board and ADC supports triggering by external signal, so it should be matter of firmware support.
- implement input current compensation. All parts except a large value resistor are already on the board, so after fitting it this feature should be again a matter of firmware.
- polish front panel user interface
- polish the SCPI commands implementation, add more commands and full manual calibration features.
- do more elaborate triggering, along with recording data into memory, to utilize all front panel buttons. 
- do more exploration and testing of the ACAL feature. As it is, works fine, but I think it could do with better repeatability.
- find lower power opamps types - this could decrease current consumption, which is always welcome in test gear.
- provide support for GPIB. Not that I need GPIB that much, but I think exploration of GPIB could be interesting project.

## Files contained in this repository
- **firmware**
	- **FPGA** - FPGA design entry files, Lattice Diamond project
	- **STM32** - STM32 on Marge board firmware, part of a workspace of STM32CubeIDE
- **hardware**
	- **PCB-design_files** - design files, one directory per board, each board is single Kicad v6 project
	- **PCB-production_files** - gerber and BOM data, one directory per board
	- **Schematics_pdf** - easy to read schematics in PDF format, one directory per board, plus top level interconnection diagram
- **measurement_data** - source data of selected measurements
- **media** - pictures and photos for this readme file.
- **mechanical**
	- **3DP_back_panel_pcb_holder** - component to keep Lisa board on back panel. Designed as single part, needs to be printed twice, one copy mirrored. Freecad design file and STL
	- **3DP_LNA_cover** - cover to keep LNA out of air turbulences. Designed as single part, needs to be printed twice, one copy mirrored. Freecad design file and STL
	- **3DP_pushbutton_assembly** - transfers front panel button to mains switch actuator. Three parts, each is needed once, contains freecad design file and STL files.
	- **3DP_reference_cover** - keeps voltage reference out of air turbulences. Two parts, each is needed once, contains freecad design file and STL files.
	- **acryllic_display_cover** - frame of display cover to be cut from gray acryllic.
	- **metal_parts_internal** - design files and manufacturing files for internal metal parts of the enclosure. 5 parts: four sheet metal (1mm thickness) components, one 2mm aluminium flat part. Each one is needed once.
	- **PCB_back_panel** - back panel, designed as PCB in Kicad. I let them to manufacture it out of FR4, but alumium boards are option, too.
	- **PCB_front_panel** - front panel, designed as PCB in Kicad. I let them to manufacture it out of FR4, but alumium boards are option, too.
	- **PCB_side_panel** - side panel, designed as PCB in Kicad. FR4 material works, aluminium would probably too, if reflowed. Two pieces needed for enclosure.
	
## Resume
This project was much fun and exploration, with the side effect of gaining a nanovoltmeter. I tried to make it as good as possible within a hobby budget, at the expense of not very cheap nor easy circuit. That gave me the idea of cherrypicking the good parts of this instrument, relaxing the design criteria somehow and making a new project with a significantly shorter and cheaper BOM. But that is the subject of a different project.

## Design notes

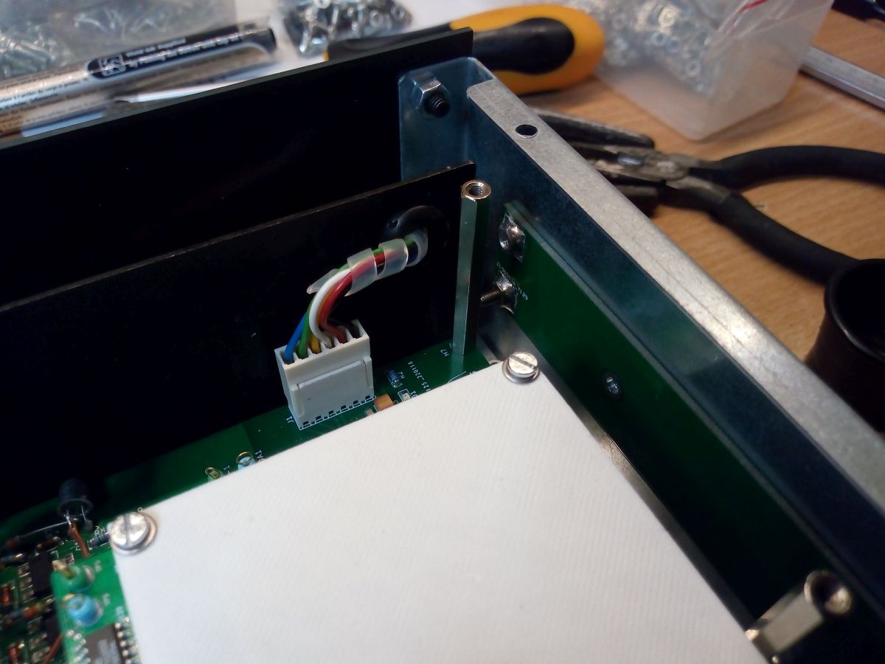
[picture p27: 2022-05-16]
media/bok.jpg

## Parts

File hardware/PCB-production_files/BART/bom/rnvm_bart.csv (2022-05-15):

Source: | /home/jarin/storage/main/backup_mg/works/nvm/pcb/rnvm_bart/rnvm_bart.kicad_sch
Date: | Sat 14 May 2022 09:41:04 PM CEST
Tool: | Eeschema 6.0.5-a6ca702e91~116~ubuntu20.04.1
Generator: | /usr/share/kicad/plugins/bom_csv_grouped_by_value.py
Component Count: | 883
Individual Components:
Item | Qty | Reference(s) | Value | LibPart | Footprint | PN | comment | supplier
 |  | C1 | 100n | Device:C | Capacitor_SMD:C_0805_2012Metric_Pad1.18x1.45mm_HandSolder | CL21B104KBCNNNC |  | TME
 |  | C2 | 470p | Device:C | Capacitor_THT:C_Rect_L7.0mm_W3.5mm_P5.00mm | FKP2-470P/630-R |  | TME
 |  | C3 | 470p | Device:C | Capacitor_THT:C_Rect_L7.0mm_W3.5mm_P5.00mm | FKP2-470P/630-R |  | TME
 |  | C4 | 100n | Device:C | Capacitor_SMD:C_0805_2012Metric_Pad1.18x1.45mm_HandSolder | CL21B104KBCNNNC |  | TME
 |  | C5 | 100n | Device:C | Capacitor_SMD:C_0805_2012Metric_Pad1.18x1.45mm_HandSolder | CL21B104KBCNNNC |  | TME
 |  | C6 | 100n | Device:C | Capacitor_SMD:C_0805_2012Metric_Pad1.18x1.45mm_HandSolder | CL21B104KBCNNNC |  | TME
 |  | C7 | 100n | Device:C | Capacitor_SMD:C_0805_2012Metric_Pad1.18x1.45mm_HandSolder | CL21B104KBCNNNC |  | TME
 |  | C8 | 100n | Device:C | Capacitor_SMD:C_0805_2012Metric_Pad1.18x1.45mm_HandSolder | CL21B104KBCNNNC |  | TME
 |  | C9 | 10u | Device:CP | Capacitor_Tantalum_SMD:CP_EIA-6032-28_Kemet-C_Pad2.25x2.35mm_HandSolder | 293D106X9025C2TE3 |  | TME
 |  | C10 | 10u | Device:CP | Capacitor_Tantalum_SMD:CP_EIA-6032-28_Kemet-C_Pad2.25x2.35mm_HandSolder | 293D106X9025C2TE3 |  | TME
 |  | C11 | 10u | Device:CP | Capacitor_Tantalum_SMD:CP_EIA-6032-28_Kemet-C_Pad2.25x2.35mm_HandSolder | 293D106X9025C2TE3 |  | TME
 |  | C12 | 10u | Device:CP | Capacitor_Tantalum_SMD:CP_EIA-6032-28_Kemet-C_Pad2.25x2.35mm_HandSolder | 293D106X9025C2TE3 |  | TME
 |  | C13 | 100n | Device:C | Capacitor_SMD:C_0805_2012Metric_Pad1.18x1.45mm_HandSolder | CL21B104KBCNNNC |  | TME
 |  | C14 | 2u2 | Device:C | Capacitor_SMD:C_0805_2012Metric_Pad1.18x1.45mm_HandSolder | CL21B225KPFNNNE |  | TME
 |  | C15 | 10u | Device:CP | Capacitor_Tantalum_SMD:CP_EIA-6032-28_Kemet-C_Pad2.25x2.35mm_HandSolder | 293D106X9025C2TE3 |  | TME
 |  | C16 | 10u | Device:CP | Capacitor_Tantalum_SMD:CP_EIA-6032-28_Kemet-C_Pad2.25x2.35mm_HandSolder | 293D106X9025C2TE3 |  | TME
 |  | C17 | 1n | Device:C | Capacitor_SMD:C_0805_2012Metric | VJ0805A102JXACW1BC |  | TME
 |  | C18 | 1n | Device:C | Capacitor_SMD:C_0805_2012Metric | VJ0805A102JXACW1BC |  | TME
 |  | C19 | 1n | Device:C | Capacitor_SMD:C_0805_2012Metric | VJ0805A102JXACW1BC |  | TME
 |  | C20 | 1n | Device:C | Capacitor_SMD:C_0805_2012Metric | VJ0805A102JXACW1BC |  | TME
 |  | C21 | 1n | Device:C | Capacitor_SMD:C_0805_2012Metric | VJ0805A102JXACW1BC |  | TME
 |  | C22 | 1n | Device:C | Capacitor_SMD:C_0805_2012Metric | VJ0805A102JXACW1BC |  | TME
 |  | C23 | 1n | Device:C | Capacitor_SMD:C_0805_2012Metric | VJ0805A102JXACW1BC |  | TME
 |  | C24 | 1n | Device:C | Capacitor_SMD:C_0805_2012Metric | VJ0805A102JXACW1BC |  | TME
 |  | C25 | 1n | Device:C | Capacitor_SMD:C_0805_2012Metric | VJ0805A102JXACW1BC |  | TME
 |  | C26 | 1n | Device:C | Capacitor_SMD:C_0805_2012Metric | VJ0805A102JXACW1BC |  | TME
 |  | C27 | 100n | Device:C | Capacitor_SMD:C_0603_1608Metric_Pad1.08x0.95mm_HandSolder | CL10B104KB8NNND |  | TME
 |  | C28 | 100n | Device:C | Capacitor_SMD:C_0603_1608Metric_Pad1.08x0.95mm_HandSolder | CL10B104KB8NNND |  | TME
 |  | C29 | 100n | Device:C | Capacitor_SMD:C_0603_1608Metric_Pad1.08x0.95mm_HandSolder | CL10B104KB8NNND |  | TME
 |  | C30 | 100n | Device:C | Capacitor_SMD:C_0603_1608Metric_Pad1.08x0.95mm_HandSolder | CL10B104KB8NNND |  | TME
 |  | C31 | 100n | Device:C | Capacitor_SMD:C_0603_1608Metric_Pad1.08x0.95mm_HandSolder | CL10B104KB8NNND |  | TME
 |  | C32 | 100n | Device:C | Capacitor_SMD:C_0603_1608Metric_Pad1.08x0.95mm_HandSolder | CL10B104KB8NNND |  | TME
 |  | C33 | 100n | Device:C | Capacitor_SMD:C_0603_1608Metric_Pad1.08x0.95mm_HandSolder | CL10B104KB8NNND |  | TME
 |  | C34 | 100n | Device:C | Capacitor_SMD:C_0603_1608Metric_Pad1.08x0.95mm_HandSolder | CL10B104KB8NNND |  | TME
 |  | C35 | 100n | Device:C | Capacitor_SMD:C_0603_1608Metric_Pad1.08x0.95mm_HandSolder | CL10B104KB8NNND |  | TME
 |  | C36 | 1n | Device:C | Capacitor_SMD:C_0805_2012Metric | VJ0805A102JXACW1BC |  | TME
 |  | C37 | 1n | Device:C | Capacitor_SMD:C_0805_2012Metric | VJ0805A102JXACW1BC |  | TME
 |  | C38 | 1n | Device:C | Capacitor_SMD:C_0805_2012Metric | VJ0805A102JXACW1BC |  | TME
 |  | C39 | 1n | Device:C | Capacitor_SMD:C_0805_2012Metric | VJ0805A102JXACW1BC |  | TME
 |  | C40 | 1n | Device:C | Capacitor_SMD:C_0805_2012Metric | VJ0805A102JXACW1BC |  | TME
 |  | C41 | 1n | Device:C | Capacitor_SMD:C_0805_2012Metric | VJ0805A102JXACW1BC |  | TME
 |  | C42 | 1n | Device:C | Capacitor_SMD:C_0805_2012Metric | VJ0805A102JXACW1BC |  | TME
 |  | C43 | 1n | Device:C | Capacitor_SMD:C_0805_2012Metric | VJ0805A102JXACW1BC |  | TME
 |  | C44 | 1n | Device:C | Capacitor_SMD:C_0805_2012Metric | VJ0805A102JXACW1BC |  | TME
 |  | C45 | 1n | Device:C | Capacitor_SMD:C_0805_2012Metric | VJ0805A102JXACW1BC |  | TME
 |  | C46 | 1n | Device:C | Capacitor_SMD:C_0805_2012Metric | VJ0805A102JXACW1BC |  | TME
 |  | C47 | 1n | Device:C | Capacitor_SMD:C_0805_2012Metric | VJ0805A102JXACW1BC |  | TME
 |  | C48 | 100n | Device:C | Capacitor_SMD:C_0603_1608Metric_Pad1.08x0.95mm_HandSolder | CL10B104KB8NNND |  | TME
 |  | C49 | 100n | Device:C | Capacitor_SMD:C_0603_1608Metric_Pad1.08x0.95mm_HandSolder | CL10B104KB8NNND |  | TME
 |  | C50 | 100n | Device:C | Capacitor_SMD:C_0603_1608Metric_Pad1.08x0.95mm_HandSolder | CL10B104KB8NNND |  | TME
 |  | C51 | 100n | Device:C | Capacitor_SMD:C_0603_1608Metric_Pad1.08x0.95mm_HandSolder | CL10B104KB8NNND |  | TME
 |  | C52 | 100n | Device:C | Capacitor_SMD:C_0603_1608Metric_Pad1.08x0.95mm_HandSolder | CL10B104KB8NNND |  | TME
 |  | C53 | 100n | Device:C | Capacitor_SMD:C_0603_1608Metric_Pad1.08x0.95mm_HandSolder | CL10B104KB8NNND |  | TME
 |  | C54 | 100n | Device:C | Capacitor_SMD:C_0603_1608Metric_Pad1.08x0.95mm_HandSolder | CL10B104KB8NNND |  | TME
 |  | C55 | 100n | Device:C | Capacitor_SMD:C_0603_1608Metric_Pad1.08x0.95mm_HandSolder | CL10B104KB8NNND |  | TME
 |  | C56 | 100n | Device:C | Capacitor_SMD:C_0603_1608Metric_Pad1.08x0.95mm_HandSolder | CL10B104KB8NNND |  | TME
 |  | C57 | 1n | Device:C | Capacitor_SMD:C_0805_2012Metric | VJ0805A102JXACW1BC |  | TME
 |  | C58 | 1n | Device:C | Capacitor_SMD:C_0805_2012Metric | VJ0805A102JXACW1BC |  | TME
 |  | C59 | 1n | Device:C | Capacitor_SMD:C_0805_2012Metric | VJ0805A102JXACW1BC |  | TME
 |  | C60 | 1n | Device:C | Capacitor_SMD:C_0805_2012Metric | VJ0805A102JXACW1BC |  | TME
 |  | C61 | 1n | Device:C | Capacitor_SMD:C_0805_2012Metric | VJ0805A102JXACW1BC |  | TME
 |  | C62 | 1n | Device:C | Capacitor_SMD:C_0805_2012Metric | VJ0805A102JXACW1BC |  | TME
 |  | C63 | 1n | Device:C | Capacitor_SMD:C_0805_2012Metric | VJ0805A102JXACW1BC |  | TME
 |  | C64 | 1n | Device:C | Capacitor_SMD:C_0805_2012Metric | VJ0805A102JXACW1BC |  | TME
 |  | C65 | 1n | Device:C | Capacitor_SMD:C_0805_2012Metric | VJ0805A102JXACW1BC |  | TME
 |  | C66 | 1n | Device:C | Capacitor_SMD:C_0805_2012Metric | VJ0805A102JXACW1BC |  | TME
 |  | C67 | 1n | Device:C | Capacitor_SMD:C_0805_2012Metric | VJ0805A102JXACW1BC |  | TME
 |  | C68 | 1n | Device:C | Capacitor_SMD:C_0805_2012Metric | VJ0805A102JXACW1BC |  | TME
 |  | C69 | 100n | Device:C | Capacitor_SMD:C_0603_1608Metric_Pad1.08x0.95mm_HandSolder | CL10B104KB8NNND |  | TME
 |  | C70 | 100n | Device:C | Capacitor_SMD:C_0603_1608Metric_Pad1.08x0.95mm_HandSolder | CL10B104KB8NNND |  | TME
 |  | C71 | 100n | Device:C | Capacitor_SMD:C_0603_1608Metric_Pad1.08x0.95mm_HandSolder | CL10B104KB8NNND |  | TME
 |  | C72 | 100n | Device:C | Capacitor_SMD:C_0603_1608Metric_Pad1.08x0.95mm_HandSolder | CL10B104KB8NNND |  | TME
 |  | C73 | 100n | Device:C | Capacitor_SMD:C_0603_1608Metric_Pad1.08x0.95mm_HandSolder | CL10B104KB8NNND |  | TME
 |  | C74 | 100n | Device:C | Capacitor_SMD:C_0603_1608Metric_Pad1.08x0.95mm_HandSolder | CL10B104KB8NNND |  | TME
 |  | C75 | 100n | Device:C | Capacitor_SMD:C_0603_1608Metric_Pad1.08x0.95mm_HandSolder | CL10B104KB8NNND |  | TME
 |  | C76 | 100n | Device:C | Capacitor_SMD:C_0603_1608Metric_Pad1.08x0.95mm_HandSolder | CL10B104KB8NNND |  | TME
 |  | C77 | 100n | Device:C | Capacitor_SMD:C_0603_1608Metric_Pad1.08x0.95mm_HandSolder | CL10B104KB8NNND |  | TME
 |  | C78 | 1n | Device:C | Capacitor_SMD:C_0805_2012Metric | VJ0805A102JXACW1BC |  | TME
 |  | C79 | 1n | Device:C | Capacitor_SMD:C_0805_2012Metric | VJ0805A102JXACW1BC |  | TME
 |  | C80 | 1n | Device:C | Capacitor_SMD:C_0805_2012Metric | VJ0805A102JXACW1BC |  | TME
 |  | C81 | 1n | Device:C | Capacitor_SMD:C_0805_2012Metric | VJ0805A102JXACW1BC |  | TME
 |  | C82 | 1n | Device:C | Capacitor_SMD:C_0805_2012Metric | VJ0805A102JXACW1BC |  | TME
 |  | C83 | 1n | Device:C | Capacitor_SMD:C_0805_2012Metric | VJ0805A102JXACW1BC |  | TME
 |  | C84 | 1n | Device:C | Capacitor_SMD:C_0805_2012Metric | VJ0805A102JXACW1BC |  | TME
 |  | C85 | 1n | Device:C | Capacitor_SMD:C_0805_2012Metric | VJ0805A102JXACW1BC |  | TME
 |  | C86 | 1n | Device:C | Capacitor_SMD:C_0805_2012Metric | VJ0805A102JXACW1BC |  | TME
 |  | C87 | 1n | Device:C | Capacitor_SMD:C_0805_2012Metric | VJ0805A102JXACW1BC |  | TME
 |  | C88 | 1n | Device:C | Capacitor_SMD:C_0805_2012Metric | VJ0805A102JXACW1BC |  | TME
 |  | C89 | 1n | Device:C | Capacitor_SMD:C_0805_2012Metric | VJ0805A102JXACW1BC |  | TME
 |  | C90 | 100n | Device:C | Capacitor_SMD:C_0603_1608Metric_Pad1.08x0.95mm_HandSolder | CL10B104KB8NNND |  | TME
 |  | C91 | 100n | Device:C | Capacitor_SMD:C_0603_1608Metric_Pad1.08x0.95mm_HandSolder | CL10B104KB8NNND |  | TME
 |  | C92 | 100n | Device:C | Capacitor_SMD:C_0603_1608Metric_Pad1.08x0.95mm_HandSolder | CL10B104KB8NNND |  | TME
 |  | C93 | 100n | Device:C | Capacitor_SMD:C_0603_1608Metric_Pad1.08x0.95mm_HandSolder | CL10B104KB8NNND |  | TME
 |  | C94 | 100n | Device:C | Capacitor_SMD:C_0603_1608Metric_Pad1.08x0.95mm_HandSolder | CL10B104KB8NNND |  | TME
 |  | C95 | 100n | Device:C | Capacitor_SMD:C_0603_1608Metric_Pad1.08x0.95mm_HandSolder | CL10B104KB8NNND |  | TME
 |  | C96 | 100n | Device:C | Capacitor_SMD:C_0603_1608Metric_Pad1.08x0.95mm_HandSolder | CL10B104KB8NNND |  | TME
 |  | C97 | 100n | Device:C | Capacitor_SMD:C_0603_1608Metric_Pad1.08x0.95mm_HandSolder | CL10B104KB8NNND |  | TME
 |  | C98 | 100n | Device:C | Capacitor_SMD:C_0603_1608Metric_Pad1.08x0.95mm_HandSolder | CL10B104KB8NNND |  | TME
 |  | C99 | 1n | Device:C | Capacitor_SMD:C_0805_2012Metric | VJ0805A102JXACW1BC |  | TME
 |  | C100 | 1n | Device:C | Capacitor_SMD:C_0805_2012Metric | VJ0805A102JXACW1BC |  | TME
 |  | C101 | 100n | Device:C | Capacitor_SMD:C_0603_1608Metric_Pad1.08x0.95mm_HandSolder | CL10B104KB8NNND |  | TME
 |  | C102 | 100n | Device:C | Capacitor_SMD:C_0603_1608Metric_Pad1.08x0.95mm_HandSolder | CL10B104KB8NNND |  | TME
 |  | C103 | 100n | Device:C | Capacitor_SMD:C_0603_1608Metric_Pad1.08x0.95mm_HandSolder | CL10B104KB8NNND |  | TME
 |  | C104 | 100n | Device:C | Capacitor_SMD:C_0603_1608Metric_Pad1.08x0.95mm_HandSolder | CL10B104KB8NNND |  | TME
 |  | C105 | 100n | Device:C | Capacitor_SMD:C_0603_1608Metric_Pad1.08x0.95mm_HandSolder | CL10B104KB8NNND |  | TME
 |  | C106 | 100n | Device:C | Capacitor_SMD:C_0603_1608Metric_Pad1.08x0.95mm_HandSolder | CL10B104KB8NNND |  | TME
 |  | C107 | 100n | Device:C | Capacitor_SMD:C_0603_1608Metric_Pad1.08x0.95mm_HandSolder | CL10B104KB8NNND |  | TME
 |  | C108 | 100n | Device:C | Capacitor_SMD:C_0603_1608Metric_Pad1.08x0.95mm_HandSolder | CL10B104KB8NNND |  | TME
 |  | C109 | 100n | Device:C | Capacitor_SMD:C_0603_1608Metric_Pad1.08x0.95mm_HandSolder | CL10B104KB8NNND |  | TME
 |  | C110 | 1n | Device:C | Capacitor_SMD:C_0805_2012Metric | VJ0805A102JXACW1BC |  | TME
 |  | C111 | 1n | Device:C | Capacitor_SMD:C_0805_2012Metric | VJ0805A102JXACW1BC |  | TME
 |  | C112 | 1n | Device:C | Capacitor_SMD:C_0805_2012Metric | VJ0805A102JXACW1BC |  | TME
 |  | C113 | 1n | Device:C | Capacitor_SMD:C_0805_2012Metric | VJ0805A102JXACW1BC |  | TME
 |  | C114 | 1n | Device:C | Capacitor_SMD:C_0805_2012Metric | VJ0805A102JXACW1BC |  | TME
 |  | C115 | 1n | Device:C | Capacitor_SMD:C_0805_2012Metric | VJ0805A102JXACW1BC |  | TME
 |  | C116 | 1n | Device:C | Capacitor_SMD:C_0805_2012Metric | VJ0805A102JXACW1BC |  | TME
 |  | C117 | 1n | Device:C | Capacitor_SMD:C_0805_2012Metric | VJ0805A102JXACW1BC |  | TME
 |  | C118 | 1n | Device:C | Capacitor_SMD:C_0805_2012Metric | VJ0805A102JXACW1BC |  | TME
 |  | C119 | 1n | Device:C | Capacitor_SMD:C_0805_2012Metric | VJ0805A102JXACW1BC |  | TME
 |  | C120 | 1n | Device:C | Capacitor_SMD:C_0805_2012Metric | VJ0805A102JXACW1BC |  | TME
 |  | C121 | 1n | Device:C | Capacitor_SMD:C_0805_2012Metric | VJ0805A102JXACW1BC |  | TME
 |  | C122 | 100n | Device:C | Capacitor_SMD:C_0603_1608Metric_Pad1.08x0.95mm_HandSolder | CL10B104KB8NNND |  | TME
 |  | C123 | 100n | Device:C | Capacitor_SMD:C_0603_1608Metric_Pad1.08x0.95mm_HandSolder | CL10B104KB8NNND |  | TME
 |  | C124 | 100n | Device:C | Capacitor_SMD:C_0603_1608Metric_Pad1.08x0.95mm_HandSolder | CL10B104KB8NNND |  | TME
 |  | C125 | 100n | Device:C | Capacitor_SMD:C_0603_1608Metric_Pad1.08x0.95mm_HandSolder | CL10B104KB8NNND |  | TME
 |  | C126 | 100n | Device:C | Capacitor_SMD:C_0603_1608Metric_Pad1.08x0.95mm_HandSolder | CL10B104KB8NNND |  | TME
 |  | C127 | 100n | Device:C | Capacitor_SMD:C_0603_1608Metric_Pad1.08x0.95mm_HandSolder | CL10B104KB8NNND |  | TME
 |  | C128 | 100n | Device:C | Capacitor_SMD:C_0603_1608Metric_Pad1.08x0.95mm_HandSolder | CL10B104KB8NNND |  | TME
 |  | C129 | 100n | Device:C | Capacitor_SMD:C_0603_1608Metric_Pad1.08x0.95mm_HandSolder | CL10B104KB8NNND |  | TME
 |  | C130 | 100n | Device:C | Capacitor_SMD:C_0603_1608Metric_Pad1.08x0.95mm_HandSolder | CL10B104KB8NNND |  | TME
 |  | C131 | 1n | Device:C | Capacitor_SMD:C_0805_2012Metric | VJ0805A102JXACW1BC |  | TME
 |  | C132 | 1n | Device:C | Capacitor_SMD:C_0805_2012Metric | VJ0805A102JXACW1BC |  | TME
 |  | C133 | 1n | Device:C | Capacitor_SMD:C_0805_2012Metric | VJ0805A102JXACW1BC |  | TME
 |  | C134 | 1n | Device:C | Capacitor_SMD:C_0805_2012Metric | VJ0805A102JXACW1BC |  | TME
 |  | C135 | 1n | Device:C | Capacitor_SMD:C_0805_2012Metric | VJ0805A102JXACW1BC |  | TME
 |  | C136 | 1n | Device:C | Capacitor_SMD:C_0805_2012Metric | VJ0805A102JXACW1BC |  | TME
 |  | C137 | 1n | Device:C | Capacitor_SMD:C_0805_2012Metric | VJ0805A102JXACW1BC |  | TME
 |  | C138 | 1n | Device:C | Capacitor_SMD:C_0805_2012Metric | VJ0805A102JXACW1BC |  | TME
 |  | C139 | 1n | Device:C | Capacitor_SMD:C_0805_2012Metric | VJ0805A102JXACW1BC |  | TME
 |  | C140 | 1n | Device:C | Capacitor_SMD:C_0805_2012Metric | VJ0805A102JXACW1BC |  | TME
 |  | C141 | 1n | Device:C | Capacitor_SMD:C_0805_2012Metric | VJ0805A102JXACW1BC |  | TME
 |  | C142 | 1n | Device:C | Capacitor_SMD:C_0805_2012Metric | VJ0805A102JXACW1BC |  | TME
 |  | C143 | 100n | Device:C | Capacitor_SMD:C_0603_1608Metric_Pad1.08x0.95mm_HandSolder | CL10B104KB8NNND |  | TME
 |  | C144 | 100n | Device:C | Capacitor_SMD:C_0603_1608Metric_Pad1.08x0.95mm_HandSolder | CL10B104KB8NNND |  | TME
 |  | C145 | 100n | Device:C | Capacitor_SMD:C_0603_1608Metric_Pad1.08x0.95mm_HandSolder | CL10B104KB8NNND |  | TME
 |  | C146 | 100n | Device:C | Capacitor_SMD:C_0603_1608Metric_Pad1.08x0.95mm_HandSolder | CL10B104KB8NNND |  | TME
 |  | C147 | 100n | Device:C | Capacitor_SMD:C_0603_1608Metric_Pad1.08x0.95mm_HandSolder | CL10B104KB8NNND |  | TME
 |  | C148 | 100n | Device:C | Capacitor_SMD:C_0603_1608Metric_Pad1.08x0.95mm_HandSolder | CL10B104KB8NNND |  | TME
 |  | C149 | 100n | Device:C | Capacitor_SMD:C_0603_1608Metric_Pad1.08x0.95mm_HandSolder | CL10B104KB8NNND |  | TME
 |  | C150 | 100n | Device:C | Capacitor_SMD:C_0603_1608Metric_Pad1.08x0.95mm_HandSolder | CL10B104KB8NNND |  | TME
 |  | C151 | 100n | Device:C | Capacitor_SMD:C_0603_1608Metric_Pad1.08x0.95mm_HandSolder | CL10B104KB8NNND |  | TME
 |  | C152 | 1n | Device:C | Capacitor_SMD:C_0805_2012Metric | VJ0805A102JXACW1BC |  | TME
 |  | C153 | 1n | Device:C | Capacitor_SMD:C_0805_2012Metric | VJ0805A102JXACW1BC |  | TME
 |  | C154 | 1n | Device:C | Capacitor_SMD:C_0805_2012Metric | VJ0805A102JXACW1BC |  | TME
 |  | C155 | 1n | Device:C | Capacitor_SMD:C_0805_2012Metric | VJ0805A102JXACW1BC |  | TME
 |  | C156 | 1n | Device:C | Capacitor_SMD:C_0805_2012Metric | VJ0805A102JXACW1BC |  | TME
 |  | C157 | 1n | Device:C | Capacitor_SMD:C_0805_2012Metric | VJ0805A102JXACW1BC |  | TME
 |  | C158 | 1n | Device:C | Capacitor_SMD:C_0805_2012Metric | VJ0805A102JXACW1BC |  | TME
 |  | C159 | 1n | Device:C | Capacitor_SMD:C_0805_2012Metric | VJ0805A102JXACW1BC |  | TME
 |  | C160 | 1n | Device:C | Capacitor_SMD:C_0805_2012Metric | VJ0805A102JXACW1BC |  | TME
 |  | C161 | 1n | Device:C | Capacitor_SMD:C_0805_2012Metric | VJ0805A102JXACW1BC |  | TME
 |  | C162 | 1n | Device:C | Capacitor_SMD:C_0805_2012Metric | VJ0805A102JXACW1BC |  | TME
 |  | C163 | 1n | Device:C | Capacitor_SMD:C_0805_2012Metric | VJ0805A102JXACW1BC |  | TME
 |  | C164 | 100n | Device:C | Capacitor_SMD:C_0603_1608Metric_Pad1.08x0.95mm_HandSolder | CL10B104KB8NNND |  | TME
 |  | C165 | 100n | Device:C | Capacitor_SMD:C_0603_1608Metric_Pad1.08x0.95mm_HandSolder | CL10B104KB8NNND |  | TME
 |  | C166 | 100n | Device:C | Capacitor_SMD:C_0603_1608Metric_Pad1.08x0.95mm_HandSolder | CL10B104KB8NNND |  | TME
 |  | C167 | 100n | Device:C | Capacitor_SMD:C_0603_1608Metric_Pad1.08x0.95mm_HandSolder | CL10B104KB8NNND |  | TME
 |  | C168 | 100n | Device:C | Capacitor_SMD:C_0603_1608Metric_Pad1.08x0.95mm_HandSolder | CL10B104KB8NNND |  | TME
 |  | C169 | 100n | Device:C | Capacitor_SMD:C_0603_1608Metric_Pad1.08x0.95mm_HandSolder | CL10B104KB8NNND |  | TME
 |  | C170 | 100n | Device:C | Capacitor_SMD:C_0603_1608Metric_Pad1.08x0.95mm_HandSolder | CL10B104KB8NNND |  | TME
 |  | C171 | 100n | Device:C | Capacitor_SMD:C_0603_1608Metric_Pad1.08x0.95mm_HandSolder | CL10B104KB8NNND |  | TME
 |  | C172 | 100n | Device:C | Capacitor_SMD:C_0603_1608Metric_Pad1.08x0.95mm_HandSolder | CL10B104KB8NNND |  | TME
 |  | C173 | 1n | Device:C | Capacitor_SMD:C_0805_2012Metric | VJ0805A102JXACW1BC |  | TME
 |  | C174 | 1n | Device:C | Capacitor_SMD:C_0805_2012Metric | VJ0805A102JXACW1BC |  | TME
 |  | C175 | 1n | Device:C | Capacitor_SMD:C_0805_2012Metric | VJ0805A102JXACW1BC |  | TME
 |  | C176 | 1n | Device:C | Capacitor_SMD:C_0805_2012Metric | VJ0805A102JXACW1BC |  | TME
 |  | C177 | 1n | Device:C | Capacitor_SMD:C_0805_2012Metric | VJ0805A102JXACW1BC |  | TME
 |  | C178 | 1n | Device:C | Capacitor_SMD:C_0805_2012Metric | VJ0805A102JXACW1BC |  | TME
 |  | C179 | 1n | Device:C | Capacitor_SMD:C_0805_2012Metric | VJ0805A102JXACW1BC |  | TME
 |  | C180 | 1n | Device:C | Capacitor_SMD:C_0805_2012Metric | VJ0805A102JXACW1BC |  | TME
 |  | C181 | 1n | Device:C | Capacitor_SMD:C_0805_2012Metric | VJ0805A102JXACW1BC |  | TME
 |  | C182 | 1n | Device:C | Capacitor_SMD:C_0805_2012Metric | VJ0805A102JXACW1BC |  | TME
 |  | C183 | 1n | Device:C | Capacitor_SMD:C_0805_2012Metric | VJ0805A102JXACW1BC |  | TME
 |  | C184 | 1n | Device:C | Capacitor_SMD:C_0805_2012Metric | VJ0805A102JXACW1BC |  | TME
 |  | C185 | 100n | Device:C | Capacitor_SMD:C_0603_1608Metric_Pad1.08x0.95mm_HandSolder | CL10B104KB8NNND |  | TME
 |  | C186 | 100n | Device:C | Capacitor_SMD:C_0603_1608Metric_Pad1.08x0.95mm_HandSolder | CL10B104KB8NNND |  | TME
 |  | C187 | 100n | Device:C | Capacitor_SMD:C_0603_1608Metric_Pad1.08x0.95mm_HandSolder | CL10B104KB8NNND |  | TME
 |  | C188 | 100n | Device:C | Capacitor_SMD:C_0603_1608Metric_Pad1.08x0.95mm_HandSolder | CL10B104KB8NNND |  | TME
 |  | C189 | 100n | Device:C | Capacitor_SMD:C_0603_1608Metric_Pad1.08x0.95mm_HandSolder | CL10B104KB8NNND |  | TME
 |  | C190 | 100n | Device:C | Capacitor_SMD:C_0603_1608Metric_Pad1.08x0.95mm_HandSolder | CL10B104KB8NNND |  | TME
 |  | C191 | 100n | Device:C | Capacitor_SMD:C_0603_1608Metric_Pad1.08x0.95mm_HandSolder | CL10B104KB8NNND |  | TME
 |  | C192 | 100n | Device:C | Capacitor_SMD:C_0603_1608Metric_Pad1.08x0.95mm_HandSolder | CL10B104KB8NNND |  | TME
 |  | C193 | 100n | Device:C | Capacitor_SMD:C_0603_1608Metric_Pad1.08x0.95mm_HandSolder | CL10B104KB8NNND |  | TME
 |  | C194 | 1n | Device:C | Capacitor_SMD:C_0805_2012Metric | VJ0805A102JXACW1BC |  | TME
 |  | C195 | 1n | Device:C | Capacitor_SMD:C_0805_2012Metric | VJ0805A102JXACW1BC |  | TME
 |  | C196 | 1n | Device:C | Capacitor_SMD:C_0805_2012Metric | VJ0805A102JXACW1BC |  | TME
 |  | C197 | 1n | Device:C | Capacitor_SMD:C_0805_2012Metric | VJ0805A102JXACW1BC |  | TME
 |  | C198 | 1n | Device:C | Capacitor_SMD:C_0805_2012Metric | VJ0805A102JXACW1BC |  | TME
 |  | C199 | 1n | Device:C | Capacitor_SMD:C_0805_2012Metric | VJ0805A102JXACW1BC |  | TME
 |  | C200 | 1n | Device:C | Capacitor_SMD:C_0805_2012Metric | VJ0805A102JXACW1BC |  | TME
 |  | C201 | 1n | Device:C | Capacitor_SMD:C_0805_2012Metric | VJ0805A102JXACW1BC |  | TME
 |  | C202 | 1n | Device:C | Capacitor_SMD:C_0805_2012Metric | VJ0805A102JXACW1BC |  | TME
 |  | C203 | 1n | Device:C | Capacitor_SMD:C_0805_2012Metric | VJ0805A102JXACW1BC |  | TME
 |  | C204 | 1n | Device:C | Capacitor_SMD:C_0805_2012Metric | VJ0805A102JXACW1BC |  | TME
 |  | C205 | 1n | Device:C | Capacitor_SMD:C_0805_2012Metric | VJ0805A102JXACW1BC |  | TME
 |  | C206 | 100n | Device:C | Capacitor_SMD:C_0603_1608Metric_Pad1.08x0.95mm_HandSolder | CL10B104KB8NNND |  | TME
 |  | C207 | 100n | Device:C | Capacitor_SMD:C_0603_1608Metric_Pad1.08x0.95mm_HandSolder | CL10B104KB8NNND |  | TME
 |  | C208 | 100n | Device:C | Capacitor_SMD:C_0603_1608Metric_Pad1.08x0.95mm_HandSolder | CL10B104KB8NNND |  | TME
 |  | C209 | 100n | Device:C | Capacitor_SMD:C_0603_1608Metric_Pad1.08x0.95mm_HandSolder | CL10B104KB8NNND |  | TME
 |  | C210 | 100n | Device:C | Capacitor_SMD:C_0603_1608Metric_Pad1.08x0.95mm_HandSolder | CL10B104KB8NNND |  | TME
 |  | C211 | 100n | Device:C | Capacitor_SMD:C_0603_1608Metric_Pad1.08x0.95mm_HandSolder | CL10B104KB8NNND |  | TME
 |  | C212 | 100n | Device:C | Capacitor_SMD:C_0603_1608Metric_Pad1.08x0.95mm_HandSolder | CL10B104KB8NNND |  | TME
 |  | C213 | 100n | Device:C | Capacitor_SMD:C_0603_1608Metric_Pad1.08x0.95mm_HandSolder | CL10B104KB8NNND |  | TME
 |  | C214 | 100n | Device:C | Capacitor_SMD:C_0603_1608Metric_Pad1.08x0.95mm_HandSolder | CL10B104KB8NNND |  | TME
 |  | C215 | 1n | Device:C | Capacitor_SMD:C_0805_2012Metric | VJ0805A102JXACW1BC |  | TME
 |  | C216 | 1n | Device:C | Capacitor_SMD:C_0805_2012Metric | VJ0805A102JXACW1BC |  | TME
 |  | C217 | 1n | Device:C | Capacitor_SMD:C_0805_2012Metric | VJ0805A102JXACW1BC |  | TME
 |  | C218 | 1n | Device:C | Capacitor_SMD:C_0805_2012Metric | VJ0805A102JXACW1BC |  | TME
 |  | C219 | 1n | Device:C | Capacitor_SMD:C_0805_2012Metric | VJ0805A102JXACW1BC |  | TME
 |  | C220 | 1n | Device:C | Capacitor_SMD:C_0805_2012Metric | VJ0805A102JXACW1BC |  | TME
 |  | C221 | 1n | Device:C | Capacitor_SMD:C_0805_2012Metric | VJ0805A102JXACW1BC |  | TME
 |  | C222 | 1n | Device:C | Capacitor_SMD:C_0805_2012Metric | VJ0805A102JXACW1BC |  | TME
 |  | C223 | 1n | Device:C | Capacitor_SMD:C_0805_2012Metric | VJ0805A102JXACW1BC |  | TME
 |  | C224 | 1n | Device:C | Capacitor_SMD:C_0805_2012Metric | VJ0805A102JXACW1BC |  | TME
 |  | C225 | 1n | Device:C | Capacitor_SMD:C_0805_2012Metric | VJ0805A102JXACW1BC |  | TME
 |  | C226 | 1n | Device:C | Capacitor_SMD:C_0805_2012Metric | VJ0805A102JXACW1BC |  | TME
 |  | C227 | 100n | Device:C | Capacitor_SMD:C_0805_2012Metric_Pad1.18x1.45mm_HandSolder | CL21B104KBCNNNC |  | TME
 |  | C228 | 100n | Device:C | Capacitor_SMD:C_0805_2012Metric_Pad1.18x1.45mm_HandSolder | CL21B104KBCNNNC |  | TME
 |  | C229 | 22n | Device:C | Capacitor_THT:C_Rect_L7.0mm_W3.5mm_P5.00mm | R82IC2220Z350K |  | TME
 |  | C230 | 1n | Device:C | Capacitor_SMD:C_0805_2012Metric | VJ0805A102JXACW1BC |  | TME
 |  | C231 | 1n | Device:C | Capacitor_SMD:C_0805_2012Metric | VJ0805A102JXACW1BC |  | TME
 |  | C232 | 100n | Device:C | Capacitor_SMD:C_0805_2012Metric_Pad1.18x1.45mm_HandSolder | CL21B104KBCNNNC |  | TME
 |  | C233 | 100n | Device:C | Capacitor_SMD:C_0805_2012Metric_Pad1.18x1.45mm_HandSolder | CL21B104KBCNNNC |  | TME
 |  | C234 | 100n | Device:C | Capacitor_SMD:C_0805_2012Metric_Pad1.18x1.45mm_HandSolder | CL21B104KBCNNNC |  | TME
 |  | C235 | 33n | Device:C | Capacitor_SMD:C_0805_2012Metric_Pad1.18x1.45mm_HandSolder | VJ0805Y333KXACW1BC |  | TME
 |  | C236 | 1n | Device:C | Capacitor_SMD:C_0805_2012Metric_Pad1.18x1.45mm_HandSolder | VJ0805A102JXACW1BC |  | TME
 |  | C237 | 100n | Device:C | Capacitor_SMD:C_0805_2012Metric_Pad1.18x1.45mm_HandSolder | CL21B104KBCNNNC |  | TME
 |  | C238 | 100n | Device:C | Capacitor_SMD:C_0805_2012Metric_Pad1.18x1.45mm_HandSolder | CL21B104KBCNNNC |  | TME
 |  | C239 | 2u2 | Device:C | Capacitor_SMD:C_0805_2012Metric_Pad1.18x1.45mm_HandSolder | CL21B225KPFNNNE |  | TME
 |  | C240 | 100n | Device:C | Capacitor_SMD:C_0805_2012Metric_Pad1.18x1.45mm_HandSolder | CL21B104KBCNNNC |  | TME
 |  | C241 | 100n | Device:C | Capacitor_SMD:C_0805_2012Metric_Pad1.18x1.45mm_HandSolder | CL21B104KBCNNNC |  | TME
 |  | C242 | DNP | Device:C | Capacitor_THT:C_Rect_L7.0mm_W3.5mm_P5.00mm |  | DNP
 |  | C243 | 100n | Device:C | Capacitor_SMD:C_0805_2012Metric_Pad1.18x1.45mm_HandSolder | CL21B104KBCNNNC |  | TME
 |  | C244 | 100n | Device:C | Capacitor_SMD:C_0805_2012Metric_Pad1.18x1.45mm_HandSolder | CL21B104KBCNNNC |  | TME
 |  | C245 | 100n | Device:C | Capacitor_SMD:C_0805_2012Metric_Pad1.18x1.45mm_HandSolder | CL21B104KBCNNNC |  | TME
 |  | C246 | 100n | Device:C | Capacitor_SMD:C_0805_2012Metric_Pad1.18x1.45mm_HandSolder | CL21B104KBCNNNC |  | TME
 |  | C247 | 100n | Device:C | Capacitor_SMD:C_0805_2012Metric_Pad1.18x1.45mm_HandSolder | CL21B104KBCNNNC |  | TME
 |  | D1 | LL43 | Diode:LL43 | Diode_SMD:D_MiniMELF | LL43-GS08 |  | TME
 |  | D2 | SM6T6V8A | Diode:SM6T6V8A | Diode_SMD:D_SMB | SM6T6V8A |  | TME
 |  | FB1 | Ferrite_Bead_Small | Device:Ferrite_Bead_Small | Inductor_SMD:L_0603_1608Metric | BLM18RK601SN1D
 |  | FB2 | FerriteBead_Small | Device:FerriteBead_Small | Inductor_SMD:L_0603_1608Metric | BLM18RK601SN1D |  | TME
 |  | FB3 | FerriteBead_Small | Device:FerriteBead_Small | Inductor_SMD:L_0603_1608Metric | BLM18RK601SN1D |  | TME
 |  | FB4 | FerriteBead_Small | Device:FerriteBead_Small | Inductor_SMD:L_0603_1608Metric | BLM18RK601SN1D |  | TME
 |  | FB5 | FerriteBead_Small | Device:FerriteBead_Small | Inductor_SMD:L_0603_1608Metric | BLM18RK601SN1D |  | TME
 |  | FB6 | FerriteBead_Small | Device:FerriteBead_Small | Inductor_SMD:L_0603_1608Metric | BLM18RK601SN1D |  | TME
 |  | FB7 | FerriteBead_Small | Device:FerriteBead_Small | Inductor_SMD:L_0603_1608Metric | BLM18RK601SN1D |  | TME
 |  | FB8 | FerriteBead_Small | Device:FerriteBead_Small | Inductor_SMD:L_0603_1608Metric | BLM18RK601SN1D |  | TME
 |  | FB9 | FerriteBead_Small | Device:FerriteBead_Small | Inductor_SMD:L_0603_1608Metric | BLM18RK601SN1D |  | TME
 |  | FB10 | FerriteBead_Small | Device:FerriteBead_Small | Inductor_SMD:L_0603_1608Metric | BLM18RK601SN1D |  | TME
 |  | FB11 | FerriteBead_Small | Device:FerriteBead_Small | Inductor_SMD:L_0603_1608Metric | BLM18RK601SN1D |  | TME
 |  | FB12 | FerriteBead_Small | Device:FerriteBead_Small | Inductor_SMD:L_0603_1608Metric | BLM18RK601SN1D |  | TME
 |  | FB13 | FerriteBead_Small | Device:FerriteBead_Small | Inductor_SMD:L_0603_1608Metric | BLM18RK601SN1D |  | TME
 |  | FB14 | FerriteBead_Small | Device:FerriteBead_Small | Inductor_SMD:L_0603_1608Metric | BLM18RK601SN1D |  | TME
 |  | FB15 | FerriteBead_Small | Device:FerriteBead_Small | Inductor_SMD:L_0603_1608Metric | BLM18RK601SN1D |  | TME
 |  | FB16 | FerriteBead_Small | Device:FerriteBead_Small | Inductor_SMD:L_0603_1608Metric | BLM18RK601SN1D |  | TME
 |  | FB17 | FerriteBead_Small | Device:FerriteBead_Small | Inductor_SMD:L_0603_1608Metric | BLM18RK601SN1D |  | TME
 |  | FB18 | FerriteBead_Small | Device:FerriteBead_Small | Inductor_SMD:L_0603_1608Metric | BLM18RK601SN1D |  | TME
 |  | FB19 | FerriteBead_Small | Device:FerriteBead_Small | Inductor_SMD:L_0603_1608Metric | BLM18RK601SN1D |  | TME
 |  | FB20 | FerriteBead_Small | Device:FerriteBead_Small | Inductor_SMD:L_0603_1608Metric | BLM18RK601SN1D |  | TME
 |  | FB21 | FerriteBead_Small | Device:FerriteBead_Small | Inductor_SMD:L_0603_1608Metric | BLM18RK601SN1D |  | TME
 |  | FB22 | FerriteBead_Small | Device:FerriteBead_Small | Inductor_SMD:L_0603_1608Metric | BLM18RK601SN1D |  | TME
 |  | FB23 | FerriteBead_Small | Device:FerriteBead_Small | Inductor_SMD:L_0603_1608Metric | BLM18RK601SN1D |  | TME
 |  | FB24 | FerriteBead_Small | Device:FerriteBead_Small | Inductor_SMD:L_0603_1608Metric | BLM18RK601SN1D |  | TME
 |  | FB25 | FerriteBead_Small | Device:FerriteBead_Small | Inductor_SMD:L_0603_1608Metric | BLM18RK601SN1D |  | TME
 |  | FB26 | FerriteBead_Small | Device:FerriteBead_Small | Inductor_SMD:L_0603_1608Metric | BLM18RK601SN1D |  | TME
 |  | FB27 | FerriteBead_Small | Device:FerriteBead_Small | Inductor_SMD:L_0603_1608Metric | BLM18RK601SN1D |  | TME
 |  | FB28 | FerriteBead_Small | Device:FerriteBead_Small | Inductor_SMD:L_0603_1608Metric | BLM18RK601SN1D |  | TME
 |  | FB29 | FerriteBead_Small | Device:FerriteBead_Small | Inductor_SMD:L_0603_1608Metric | BLM18RK601SN1D |  | TME
 |  | FB30 | FerriteBead_Small | Device:FerriteBead_Small | Inductor_SMD:L_0603_1608Metric | BLM18RK601SN1D |  | TME
 |  | FB31 | FerriteBead_Small | Device:FerriteBead_Small | Inductor_SMD:L_0603_1608Metric | BLM18RK601SN1D |  | TME
 |  | FB32 | FerriteBead_Small | Device:FerriteBead_Small | Inductor_SMD:L_0603_1608Metric | BLM18RK601SN1D |  | TME
 |  | FB33 | FerriteBead_Small | Device:FerriteBead_Small | Inductor_SMD:L_0603_1608Metric | BLM18RK601SN1D |  | TME
 |  | FB34 | FerriteBead_Small | Device:FerriteBead_Small | Inductor_SMD:L_0603_1608Metric | BLM18RK601SN1D |  | TME
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

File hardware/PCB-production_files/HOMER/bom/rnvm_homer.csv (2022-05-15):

Source: | /home/jarin/storage/main/backup_mg/works/nvm/pcb/rnvm_homer/rnvm_homer.kicad_sch
Date: | Sat 14 May 2022 10:56:04 PM CEST
Tool: | Eeschema 6.0.5-a6ca702e91~116~ubuntu20.04.1
Generator: | /usr/share/kicad/plugins/bom_csv_grouped_by_value.py
Component Count: | 238
Individual Components:
Item | Qty | Reference(s) | Value | LibPart | Footprint | PN | comment | supplier
 |  | C1 | 100n | Device:C | Capacitor_SMD:C_0805_2012Metric_Pad1.18x1.45mm_HandSolder | CL21B104KBCNNNC |  | TME
 |  | C2 | 100n | Device:C | Capacitor_SMD:C_0805_2012Metric_Pad1.18x1.45mm_HandSolder | CL21B104KBCNNNC |  | TME
 |  | C3 | 10u | Device:CP | Capacitor_Tantalum_SMD:CP_EIA-3528-21_Kemet-B | T491B106K025AT |  | TME
 |  | C4 | 1u | Device:C | Capacitor_THT:C_Rect_L7.0mm_W4.5mm_P5.00mm | MKS2-1U/50 |  | TME
 |  | C5 | 1u | Device:C | Capacitor_THT:C_Rect_L7.0mm_W4.5mm_P5.00mm | MKS2-1U/50 |  | TME
 |  | C6 | 1n | Device:C | Capacitor_SMD:C_0805_2012Metric_Pad1.18x1.45mm_HandSolder | VJ0805A102JXACW1BC |  | TME
 |  | C7 | 1n | Device:C | Capacitor_SMD:C_0805_2012Metric_Pad1.18x1.45mm_HandSolder | VJ0805A102JXACW1BC |  | TME
 |  | C8 | 1u | Device:C | Capacitor_THT:C_Rect_L7.0mm_W4.5mm_P5.00mm | MKS2-1U/50 |  | TME
 |  | C9 | 220u | Device:CP | Capacitor_THT:CP_Radial_D8.0mm_P2.50mm | ECE-A1AKS221 |  | MOUSER
 |  | C10 | 220u | Device:CP | Capacitor_THT:CP_Radial_D8.0mm_P2.50mm | ECE-A1AKS221 |  | MOUSER
 |  | C11 | 220u | Device:CP | Capacitor_THT:CP_Radial_D8.0mm_P2.50mm | ECE-A1AKS221 |  | MOUSER
 |  | C12 | 220u | Device:CP | Capacitor_THT:CP_Radial_D8.0mm_P2.50mm | ECE-A1AKS221 |  | MOUSER
 |  | C13 | 22u | Device:C_Polarized | Capacitor_Tantalum_SMD:CP_EIA-6032-28_Kemet-C_Pad2.25x2.35mm_HandSolder | T491C226K025AT |  | TME
 |  | C14 | 22u | Device:C_Polarized | Capacitor_Tantalum_SMD:CP_EIA-6032-28_Kemet-C_Pad2.25x2.35mm_HandSolder | T491C226K025AT |  | TME
 |  | C15 | 22u | Device:C_Polarized | Capacitor_Tantalum_SMD:CP_EIA-6032-28_Kemet-C_Pad2.25x2.35mm_HandSolder | T491C226K025AT |  | TME
 |  | C16 | 1u | Device:C | Capacitor_SMD:C_0805_2012Metric_Pad1.18x1.45mm_HandSolder | CL21B105KAFNNNG |  | TME
 |  | C17 | 10u | Device:CP | Capacitor_Tantalum_SMD:CP_EIA-3528-21_Kemet-B | T491B106K025AT |  | TME
 |  | C18 | 1u | Device:C | Capacitor_SMD:C_0805_2012Metric_Pad1.18x1.45mm_HandSolder | CL21B105KAFNNNG |  | TME
 |  | C19 | 10u | Device:CP | Capacitor_Tantalum_SMD:CP_EIA-3528-21_Kemet-B | T491B106K025AT |  | TME
 |  | C20 | 1u | Device:C | Capacitor_SMD:C_0805_2012Metric_Pad1.18x1.45mm_HandSolder | CL21B105KAFNNNG |  | TME
 |  | C21 | 1u | Device:C | Capacitor_SMD:C_0805_2012Metric_Pad1.18x1.45mm_HandSolder | CL21B105KAFNNNG |  | TME
 |  | C22 | 1u | Device:C | Capacitor_SMD:C_0805_2012Metric_Pad1.18x1.45mm_HandSolder | CL21B105KAFNNNG |  | TME
 |  | C23 | 10u | Device:CP | Capacitor_Tantalum_SMD:CP_EIA-3528-21_Kemet-B | T491B106K025AT |  | TME
 |  | C24 | 1u | Device:C | Capacitor_SMD:C_0805_2012Metric_Pad1.18x1.45mm_HandSolder | CL21B105KAFNNNG |  | TME
 |  | C25 | 10u | Device:CP | Capacitor_Tantalum_SMD:CP_EIA-3528-21_Kemet-B | T491B106K025AT |  | TME
 |  | C26 | 1u | Device:C | Capacitor_SMD:C_0805_2012Metric_Pad1.18x1.45mm_HandSolder | CL21B105KAFNNNG |  | TME
 |  | C27 | 1u | Device:C | Capacitor_SMD:C_0805_2012Metric_Pad1.18x1.45mm_HandSolder | CL21B105KAFNNNG |  | TME
 |  | C28 | 220p | Device:C | Capacitor_SMD:C_0805_2012Metric_Pad1.18x1.45mm_HandSolder | VJ0805A221JXACW1BC |  | TME
 |  | C29 | 1n | Device:C | Capacitor_SMD:C_0805_2012Metric_Pad1.18x1.45mm_HandSolder | VJ0805A102JXACW1BC |  | TME
 |  | C30 | DNP | Device:C | Capacitor_SMD:C_0805_2012Metric_Pad1.18x1.45mm_HandSolder |  | DNP
 |  | C31 | 220p | Device:C | Capacitor_SMD:C_0805_2012Metric_Pad1.18x1.45mm_HandSolder | VJ0805A221JXACW1BC |  | TME
 |  | C32 | 1u | Device:C | Capacitor_SMD:C_0805_2012Metric_Pad1.18x1.45mm_HandSolder | CL21B105KAFNNNG |  | TME
 |  | C33 | 1u | Device:C | Capacitor_SMD:C_0805_2012Metric_Pad1.18x1.45mm_HandSolder | CL21B105KAFNNNG |  | TME
 |  | C34 | 10u | Device:CP | Capacitor_Tantalum_SMD:CP_EIA-3528-21_Kemet-B | T491B106K025AT |  | TME
 |  | C35 | 2u2 | Device:C | Capacitor_SMD:C_0805_2012Metric_Pad1.18x1.45mm_HandSolder | CL21B225KPFNNNE |  | TME
 |  | C36 | 1u | Device:C | Capacitor_SMD:C_0805_2012Metric_Pad1.18x1.45mm_HandSolder | CL21B105KAFNNNG |  | TME
 |  | C37 | 1u | Device:C | Capacitor_SMD:C_0805_2012Metric_Pad1.18x1.45mm_HandSolder | CL21B105KAFNNNG |  | TME
 |  | C38 | 100n | Device:C | Capacitor_SMD:C_0805_2012Metric_Pad1.18x1.45mm_HandSolder | CL21B104KBCNNNC |  | TME
 |  | C39 | 1u | Device:C | Capacitor_THT:C_Rect_L7.0mm_W4.5mm_P5.00mm | MKS2-1U/50 |  | TME
 |  | C40 | 100n | Device:C | Capacitor_SMD:C_0805_2012Metric_Pad1.18x1.45mm_HandSolder | CL21B104KBCNNNC |  | TME
 |  | C41 | 100n | Device:C | Capacitor_SMD:C_0805_2012Metric_Pad1.18x1.45mm_HandSolder | CL21B104KBCNNNC |  | TME
 |  | C42 | 100n | Device:C | Capacitor_SMD:C_0805_2012Metric_Pad1.18x1.45mm_HandSolder | CL21B104KBCNNNC |  | TME
 |  | C43 | 100n | Device:C | Capacitor_SMD:C_0805_2012Metric_Pad1.18x1.45mm_HandSolder | CL21B104KBCNNNC |  | TME
 |  | C44 | 100n | Device:C | Capacitor_SMD:C_0805_2012Metric_Pad1.18x1.45mm_HandSolder | CL21B104KBCNNNC |  | TME
 |  | C45 | 100n | Device:C | Capacitor_SMD:C_0805_2012Metric_Pad1.18x1.45mm_HandSolder | CL21B104KBCNNNC |  | TME
 |  | C46 | 2u2 | Device:C | Capacitor_SMD:C_0805_2012Metric_Pad1.18x1.45mm_HandSolder | CL21B225KPFNNNE |  | TME
 |  | C47 | 2u2 | Device:C | Capacitor_SMD:C_0805_2012Metric_Pad1.18x1.45mm_HandSolder | CL21B225KPFNNNE |  | TME
 |  | C48 | 100n | Device:C | Capacitor_SMD:C_0805_2012Metric_Pad1.18x1.45mm_HandSolder | CL21B104KBCNNNC |  | TME
 |  | C49 | 100n | Device:C | Capacitor_SMD:C_0805_2012Metric_Pad1.18x1.45mm_HandSolder | CL21B104KBCNNNC |  | TME
 |  | C50 | 100n | Device:C | Capacitor_SMD:C_0805_2012Metric_Pad1.18x1.45mm_HandSolder | CL21B104KBCNNNC |  | TME
 |  | C51 | 100n | Device:C | Capacitor_SMD:C_0805_2012Metric_Pad1.18x1.45mm_HandSolder | CL21B104KBCNNNC |  | TME
 |  | C52 | 100n | Device:C | Capacitor_SMD:C_0805_2012Metric_Pad1.18x1.45mm_HandSolder | CL21B104KBCNNNC |  | TME
 |  | D1 | LED | Device:LED | LED_SMD:LED_0805_2012Metric_Pad1.15x1.40mm_HandSolder | KP-2012YD |  | TME
 |  | D2 | LL4148 | Diode:LL4148 | Diode_SMD:D_MiniMELF | LL4148-GS18 |  | TME
 |  | D3 | LL4148 | Diode:LL4148 | Diode_SMD:D_MiniMELF | LL4148-GS18 |  | TME
 |  | D4 | 5V6 | Device:D_Zener | Diode_SMD:D_MiniMELF | TZMB5V6-GS08 |  | TME
 |  | D5 | BAT42 | Diode:BAT42W-V | Diode_SMD:D_SOD-123 | BAT42W-7-F |  | TME
 |  | D6 | 5V6 | Device:D_Zener | Diode_SMD:D_MiniMELF | TZMB5V6-GS08 |  | TME
 |  | D7 | 5V6 | Device:D_Zener | Diode_SMD:D_MiniMELF | TZMB5V6-GS08 |  | TME
 |  | D8 | LED | Device:LED | LED_SMD:LED_0805_2012Metric_Pad1.15x1.40mm_HandSolder | KP-2012YD |  | TME
 |  | D9 | LED | Device:LED | LED_SMD:LED_0805_2012Metric_Pad1.15x1.40mm_HandSolder | KP-2012YD |  | TME
 |  | D10 | LED | Device:LED | LED_SMD:LED_0805_2012Metric_Pad1.15x1.40mm_HandSolder | KP-2012YD |  | TME
 |  | FB1 | Ferrite_Bead_Small | Device:Ferrite_Bead_Small | Inductor_SMD:L_1206_3216Metric_Pad1.22x1.90mm_HandSolder | BLM31A260SPT |  | TME
 |  | FB2 | Ferrite_Bead_Small | Device:Ferrite_Bead_Small | Inductor_SMD:L_1206_3216Metric_Pad1.22x1.90mm_HandSolder | BLM31A260SPT |  | TME
 |  | FB3 | Ferrite_Bead_Small | Device:Ferrite_Bead_Small | Inductor_SMD:L_1206_3216Metric_Pad1.22x1.90mm_HandSolder | BLM31A260SPT |  | TME
 |  | FB4 | Ferrite_Bead_Small | Device:Ferrite_Bead_Small | Inductor_SMD:L_1206_3216Metric_Pad1.22x1.90mm_HandSolder | BLM31A260SPT |  | TME
 |  | FB5 | Ferrite_Bead_Small | Device:Ferrite_Bead_Small | Inductor_SMD:L_1206_3216Metric_Pad1.22x1.90mm_HandSolder | BLM31A260SPT |  | TME
 |  | FB6 | Ferrite_Bead_Small | Device:Ferrite_Bead_Small | Inductor_SMD:L_1206_3216Metric_Pad1.22x1.90mm_HandSolder | BLM31A260SPT |  | TME
 |  | FB7 | Ferrite_Bead_Small | Device:Ferrite_Bead_Small | Inductor_SMD:L_1206_3216Metric_Pad1.22x1.90mm_HandSolder | BLM31A260SPT |  | TME
 |  | H1 | MountingHole | Mechanical:MountingHole | MountingHole:MountingHole_3.2mm_M3 |  | DNP
 |  | H2 | MountingHole | Mechanical:MountingHole | MountingHole:MountingHole_3.2mm_M3 |  | DNP
 |  | H3 | MountingHole | Mechanical:MountingHole | MountingHole:MountingHole_3.2mm_M3 |  | DNP
 |  | H4 | MountingHole | Mechanical:MountingHole | MountingHole:MountingHole_3.2mm_M3 |  | DNP
 |  | H5 | MountingHole | Mechanical:MountingHole | MountingHole:MountingHole_3.2mm_M3 |  | DNP
 |  | H6 | MountingHole | Mechanical:MountingHole | MountingHole:MountingHole_3.2mm_M3 |  | DNP
 |  | H7 | MountingHole | Mechanical:MountingHole | MountingHole:MountingHole_3.2mm_M3 |  | DNP
 |  | H8 | MountingHole | Mechanical:MountingHole | MountingHole:MountingHole_3.2mm_M3 |  | DNP
 |  | H9 | MountingHole | Mechanical:MountingHole | MountingHole:MountingHole_3.2mm_M3 |  | DNP
 |  | H10 | MountingHole | Mechanical:MountingHole | MountingHole:MountingHole_3.2mm_M3 |  | DNP
 |  | H11 | MountingHole | Mechanical:MountingHole | MountingHole:MountingHole_2.7mm_Pad |  | DNP
 |  | H12 | MountingHole | Mechanical:MountingHole | MountingHole:MountingHole_2.7mm_Pad |  | DNP
 |  | H13 | MountingHole | Mechanical:MountingHole | MountingHole:MountingHole_3.2mm_M3 |  | DNP
 |  | H14 | MountingHole | Mechanical:MountingHole | MountingHole:MountingHole_3.2mm_M3 |  | DNP
 |  | J1 | Conn_01x06_Male | Connector:Conn_01x06_Male | Connector_Molex:Molex_KK-254_AE-6410-06A_1x06_P2.54mm_Vertical | NS25-W6P |  | TME
 |  | J2 | Conn_01x10_Male | Connector:Conn_01x10_Male | Connector_Molex:Molex_KK-254_AE-6410-10A_1x10_P2.54mm_Vertical | NS25-W10P |  | TME
 |  | J3 | Conn_02x08_Odd_Even | Connector_Generic:Conn_02x08_Odd_Even | Connector_PinHeader_2.54mm:PinHeader_2x08_P2.54mm_Vertical | ZL201-10G |  | TME
 |  | J4 | Conn_01x08_Male | Connector:Conn_01x08_Male | Connector_PinHeader_2.54mm:PinHeader_1x08_P2.54mm_Vertical | ZL201-10G |  | TME
 |  | J5 | Conn_01x08_Male | Connector:Conn_01x08_Male | Connector_PinHeader_2.54mm:PinHeader_1x08_P2.54mm_Vertical | ZL201-10G |  | TME
 |  | J6 | Conn_01x04_Male | Connector:Conn_01x04_Male | Connector_PinHeader_2.54mm:PinHeader_1x04_P2.54mm_Vertical | ZL201-10G |  | TME
 |  | J7 | Conn_02x03_Odd_Even | Connector_Generic:Conn_02x03_Odd_Even | Connector_IDC:IDC-Header_2x03_P2.54mm_Vertical | 75869-331LF |  | TME
 |  | LOGO1 | logo_generic | j_lib:logo_generic | j_lib:logo_rpg7x9 |  | DNP
 |  | Q1 | BCP56 | Transistor_BJT:BCP56 | Package_TO_SOT_SMD:SOT-223 | BCP56-16.115 |  | TME
 |  | Q2 | BC847 | Transistor_BJT:BC847 | Package_TO_SOT_SMD:SOT-23 | BC847.215 |  | TME
 |  | Q3 | BC847 | Transistor_BJT:BC847 | Package_TO_SOT_SMD:SOT-23 | BC847.215 |  | TME
 |  | Q4 | BC857 | Transistor_BJT:BC857 | Package_TO_SOT_SMD:SOT-23 | BC857.215 |  | TME
 |  | Q5 | BC857 | Transistor_BJT:BC857 | Package_TO_SOT_SMD:SOT-23 | BC857.215 |  | TME
 |  | Q6 | BCP53 | Transistor_BJT:BCP53 | Package_TO_SOT_SMD:SOT-223 | BCP53-16,115 |  | TME
 |  | Q7 | BCP53 | Transistor_BJT:BCP53 | Package_TO_SOT_SMD:SOT-223 | BCP53-16,115 |  | TME
 |  | Q8 | BC847 | Transistor_BJT:BC847 | Package_TO_SOT_SMD:SOT-23 | BC847.215 |  | TME
 |  | Q9 | BC847 | Transistor_BJT:BC847 | Package_TO_SOT_SMD:SOT-23 | BC847.215 |  | TME
 |  | Q10 | BC857 | Transistor_BJT:BC857 | Package_TO_SOT_SMD:SOT-23 | BC857.215 |  | TME
 |  | R1 | 16k | Device:R | Resistor_SMD:R_MiniMELF_MMA-0204 | CSRV0204FTDG1602 |  | TME
 |  | R2 | 16k | Device:R | Resistor_SMD:R_MiniMELF_MMA-0204 | CSRV0204FTDG1602 |  | TME
 |  | R3 | 620R | Device:R | Resistor_SMD:R_MiniMELF_MMA-0204 | MMA02040C6200 |  | TME
 |  | R4 | 16k | Device:R | Resistor_SMD:R_MiniMELF_MMA-0204 | CSRV0204FTDG1602 |  | TME
 |  | R5 | 16k | Device:R | Resistor_SMD:R_MiniMELF_MMA-0204 | CSRV0204FTDG1602 |  | TME
 |  | R6 | 12R | Device:R | Resistor_SMD:R_MiniMELF_MMA-0204 | SMDMM0204-12R |  | TME
 |  | R7 | 24k | Device:R | Resistor_SMD:R_MiniMELF_MMA-0204 | MMA02040C2402 |  | TME
 |  | R8 | 12k | Device:R | Resistor_SMD:R_MiniMELF_MMA-0204 | MMA02040C1202 |  | TME
 |  | R9 | 120R | Device:R | Resistor_SMD:R_MiniMELF_MMA-0204 | MMA02040C1200 |  | TME
 |  | R10 | 12k | Device:R | Resistor_SMD:R_MiniMELF_MMA-0204 | MMA02040C1202 |  | TME
 |  | R11 | 120k | Device:R | Resistor_SMD:R_MiniMELF_MMA-0204 | MMA02040C1203 |  | TME
 |  | R12 | 120k | Device:R | Resistor_SMD:R_MiniMELF_MMA-0204 | MMA02040C1203 |  | TME
 |  | R13 | 12k | Device:R | Resistor_SMD:R_MiniMELF_MMA-0204 | MMA02040C1202 |  | TME
 |  | R14 | 120R | Device:R | Resistor_SMD:R_MiniMELF_MMA-0204 | MMA02040C1200 |  | TME
 |  | R15 | 12k | Device:R | Resistor_SMD:R_MiniMELF_MMA-0204 | MMA02040C1202 |  | TME
 |  | R16 | 24k | Device:R | Resistor_SMD:R_MiniMELF_MMA-0204 | MMA02040C2402 |  | TME
 |  | R17 | 12R | Device:R | Resistor_SMD:R_MiniMELF_MMA-0204 | SMDMM0204-12R |  | TME
 |  | R18 | 12k | Device:R | Resistor_SMD:R_MiniMELF_MMA-0204 | MMA02040C1202 |  | TME
 |  | R19 | 24R | Device:R | Resistor_SMD:R_MiniMELF_MMA-0204 | SMDMM0204-24R |  | TME
 |  | R20 | 24R | Device:R | Resistor_SMD:R_MiniMELF_MMA-0204 | SMDMM0204-24R |  | TME
 |  | R21 | 2k4 | Device:R | Resistor_SMD:R_MiniMELF_MMA-0204 | MMA02040C2401 |  | TME
 |  | R22 | 24R | Device:R | Resistor_SMD:R_MiniMELF_MMA-0204 | SMDMM0204-24R |  | TME
 |  | R23 | 0R | Device:R | Resistor_SMD:R_MiniMELF_MMA-0204 | SMDMM0204-0R |  | TME
 |  | R24 | 24R | Device:R | Resistor_SMD:R_MiniMELF_MMA-0204 | SMDMM0204-24R |  | TME
 |  | R25 | 12k | Device:R | Resistor_SMD:R_MiniMELF_MMA-0204 | MMA02040C1202 |  | TME
 |  | R26 | 1k2 | Device:R | Resistor_SMD:R_MiniMELF_MMA-0204 | MMA02040C1201 |  | TME
 |  | R27 | 24R | Device:R | Resistor_SMD:R_MiniMELF_MMA-0204 | SMDMM0204-24R |  | TME
 |  | R28 | 1k2 | Device:R | Resistor_SMD:R_MiniMELF_MMA-0204 | MMA02040C1201 |  | TME
 |  | R29 | 24R | Device:R | Resistor_SMD:R_MiniMELF_MMA-0204 | SMDMM0204-24R |  | TME
 |  | R30 | 24R | Device:R | Resistor_SMD:R_MiniMELF_MMA-0204 | SMDMM0204-24R |  | TME
 |  | R31 | 12k | Device:R | Resistor_SMD:R_MiniMELF_MMA-0204 | MMA02040C1202 |  | TME
 |  | R32 | 0R | Device:R | Resistor_SMD:R_MiniMELF_MMA-0204 | SMDMM0204-0R |  | TME
 |  | R33 | 12k | Device:R | Resistor_SMD:R_MiniMELF_MMA-0204 | MMA02040C1202 |  | TME
 |  | R34 | DNP | Device:R | Resistor_SMD:R_MiniMELF_MMA-0204 |  | DNP
 |  | R35 | 8k2 | Device:R | Resistor_SMD:R_MiniMELF_MMA-0204 | MMA02040C8201 |  | TME
 |  | R36 | 0R | Device:R | Resistor_SMD:R_MiniMELF_MMA-0204 | SMDMM0204-0R |  | TME
 |  | R37 | 12k | Device:R | Resistor_SMD:R_MiniMELF_MMA-0204 | MMA02040C1202 |  | TME
 |  | R38 | 24k | Device:R | Resistor_SMD:R_MiniMELF_MMA-0204 | MMA02040C2402 |  | TME
 |  | R39 | 300k | Device:R | Resistor_SMD:R_MiniMELF_MMA-0204 | MMA02040C3003 |  | TME
 |  | R40 | 12k | Device:R | Resistor_SMD:R_MiniMELF_MMA-0204 | MMA02040C1202 |  | TME
 |  | R41 | 3k6 | Device:R | Resistor_SMD:R_MiniMELF_MMA-0204 | MMA02040C3601 |  | TME
 |  | R42 | 3k6 | Device:R | Resistor_SMD:R_MiniMELF_MMA-0204 | MMA02040C3601 |  | TME
 |  | R43 | 3k6 | Device:R | Resistor_SMD:R_MiniMELF_MMA-0204 | MMA02040C3601 |  | TME
 |  | R44 | 3k6 | Device:R | Resistor_SMD:R_MiniMELF_MMA-0204 | MMA02040C3601 |  | TME
 |  | R45 | 12k | Device:R | Resistor_SMD:R_MiniMELF_MMA-0204 | MMA02040C1202 |  | TME
 |  | R46 | 6k2 | Device:R | Resistor_SMD:R_MiniMELF_MMA-0204 | MMA02040C6201 |  | TME
 |  | R47 | 12k | Device:R | Resistor_SMD:R_MiniMELF_MMA-0204 | MMA02040C1202 |  | TME
 |  | R48 | 12k | Device:R | Resistor_SMD:R_MiniMELF_MMA-0204 | MMA02040C1202 |  | TME
 |  | R49 | 2k49 | Device:R | Resistor_THT:R_Axial_DIN0207_L6.3mm_D2.5mm_P15.24mm_Horizontal | YR1B2K49CC | 7k for LM399 | MOUSER
 |  | R50 | 12R | Device:R | Resistor_SMD:R_MiniMELF_MMA-0204 | SMDMM0204-12R |  | TME
 |  | R51 | 8k2 | Device:R | Resistor_SMD:R_MiniMELF_MMA-0204 | MMA02040C8201 |  | TME
 |  | R52 | 0R | Device:R | Resistor_SMD:R_MiniMELF_MMA-0204 | SMDMM0204-0R |  | TME
 |  | R53 | 24R | Device:R | Resistor_SMD:R_MiniMELF_MMA-0204 | SMDMM0204-24R |  | TME
 |  | R54 | 24R | Device:R | Resistor_SMD:R_MiniMELF_MMA-0204 | SMDMM0204-24R |  | TME
 |  | R55 | 24R | Device:R | Resistor_SMD:R_MiniMELF_MMA-0204 | SMDMM0204-24R |  | TME
 |  | R56 | 24R | Device:R | Resistor_SMD:R_MiniMELF_MMA-0204 | SMDMM0204-24R |  | TME
 |  | R57 | 24R | Device:R | Resistor_SMD:R_MiniMELF_MMA-0204 | SMDMM0204-24R |  | TME
 |  | R58 | 24R | Device:R | Resistor_SMD:R_MiniMELF_MMA-0204 | SMDMM0204-24R |  | TME
 |  | R59 | 24R | Device:R | Resistor_SMD:R_MiniMELF_MMA-0204 | SMDMM0204-24R |  | TME
 |  | R60 | 24R | Device:R | Resistor_SMD:R_MiniMELF_MMA-0204 | SMDMM0204-24R |  | TME
 |  | R61 | 24R | Device:R | Resistor_SMD:R_MiniMELF_MMA-0204 | SMDMM0204-24R |  | TME
 |  | R62 | 24R | Device:R | Resistor_SMD:R_MiniMELF_MMA-0204 | SMDMM0204-24R |  | TME
 |  | R63 | 24R | Device:R | Resistor_SMD:R_MiniMELF_MMA-0204 | SMDMM0204-24R |  | TME
 |  | R64 | 24R | Device:R | Resistor_SMD:R_MiniMELF_MMA-0204 | SMDMM0204-24R |  | TME
 |  | R65 | 24R | Device:R | Resistor_SMD:R_MiniMELF_MMA-0204 | SMDMM0204-24R |  | TME
 |  | R66 | 24R | Device:R | Resistor_SMD:R_MiniMELF_MMA-0204 | SMDMM0204-24R |  | TME
 |  | R67 | 24R | Device:R | Resistor_SMD:R_MiniMELF_MMA-0204 | SMDMM0204-24R |  | TME
 |  | R68 | 24R | Device:R | Resistor_SMD:R_MiniMELF_MMA-0204 | SMDMM0204-24R |  | TME
 |  | R69 | 24R | Device:R | Resistor_SMD:R_MiniMELF_MMA-0204 | SMDMM0204-24R |  | TME
 |  | R70 | 24R | Device:R | Resistor_SMD:R_MiniMELF_MMA-0204 | SMDMM0204-24R |  | TME
 |  | R71 | 24R | Device:R | Resistor_SMD:R_MiniMELF_MMA-0204 | SMDMM0204-24R |  | TME
 |  | R72 | 24R | Device:R | Resistor_SMD:R_MiniMELF_MMA-0204 | SMDMM0204-24R |  | TME
 |  | R73 | 24R | Device:R | Resistor_SMD:R_MiniMELF_MMA-0204 | SMDMM0204-24R |  | TME
 |  | R74 | 24R | Device:R | Resistor_SMD:R_MiniMELF_MMA-0204 | SMDMM0204-24R |  | TME
 |  | R75 | 24R | Device:R | Resistor_SMD:R_MiniMELF_MMA-0204 | SMDMM0204-24R |  | TME
 |  | R76 | 24R | Device:R | Resistor_SMD:R_MiniMELF_MMA-0204 | SMDMM0204-24R |  | TME
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

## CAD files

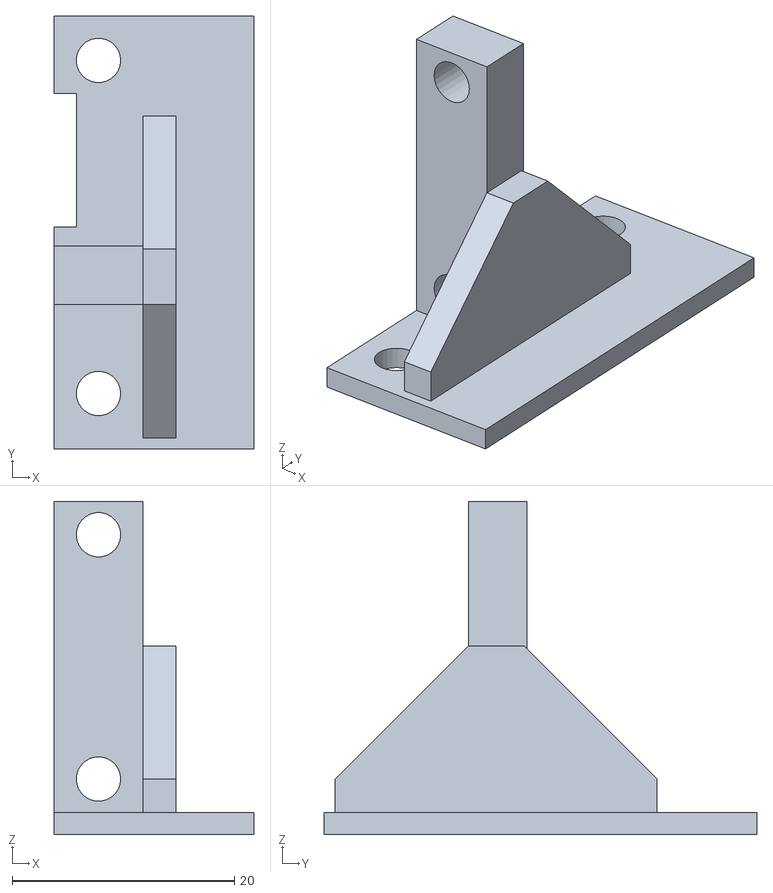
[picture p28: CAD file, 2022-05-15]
mechanical/3DP_back_panel_pcb_holder/holder_com-holder.stl
18.0 x 39.0 x 30.0

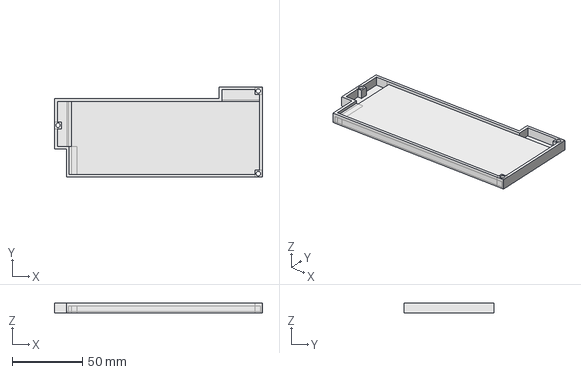
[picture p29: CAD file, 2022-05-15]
mechanical/3DP_LNA_cover/design_file/cover_B.FCStd
148.5 x 64.5 x 7.00 mm

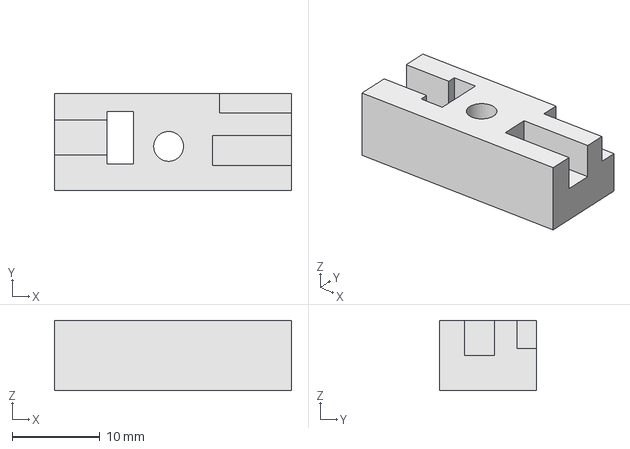
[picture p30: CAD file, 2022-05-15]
mechanical/3DP_pushbutton_assembly/design_file/pb1.FCStd
27.0 x 11.0 x 8.00 mm

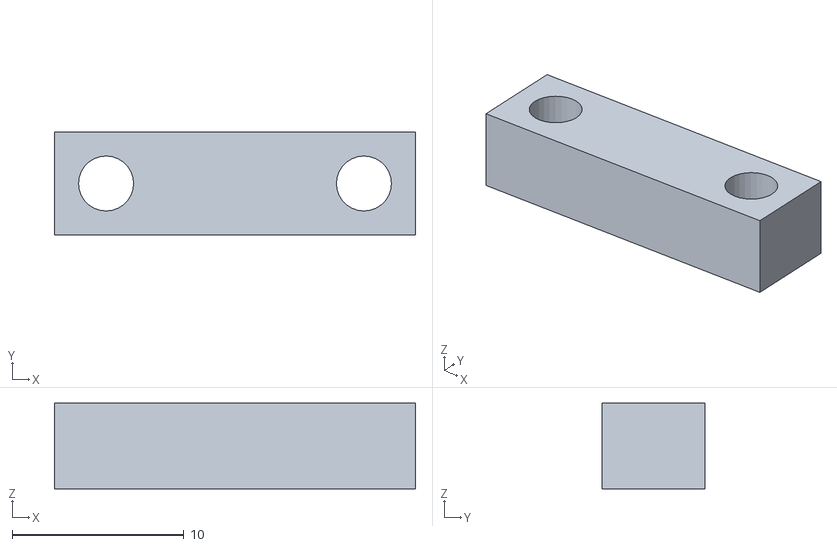
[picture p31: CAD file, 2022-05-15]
mechanical/3DP_pushbutton_assembly/manufacturing_data/pb1-mid.stl
21.0 x 6.00 x 5.00

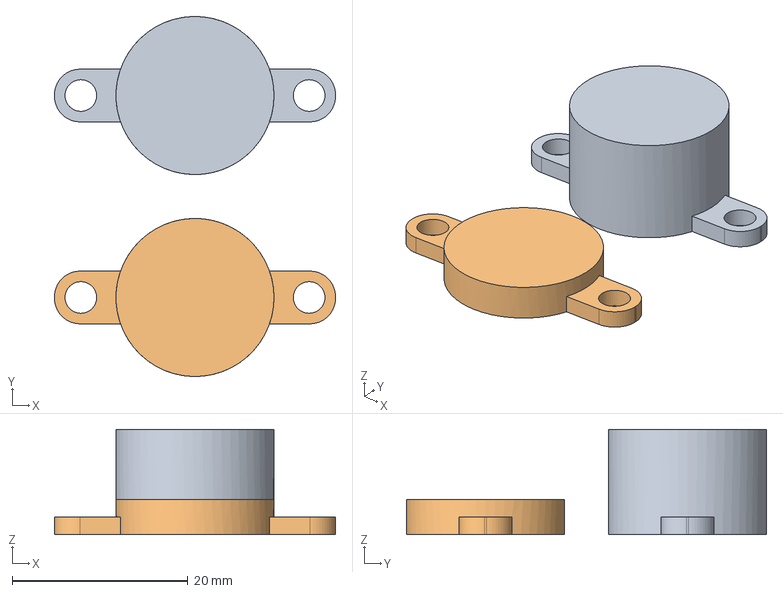
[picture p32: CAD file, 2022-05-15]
mechanical/3DP_reference_cover/design_file/ref_cover.FCStd
32.0 x 41.0 x 12.0 mm

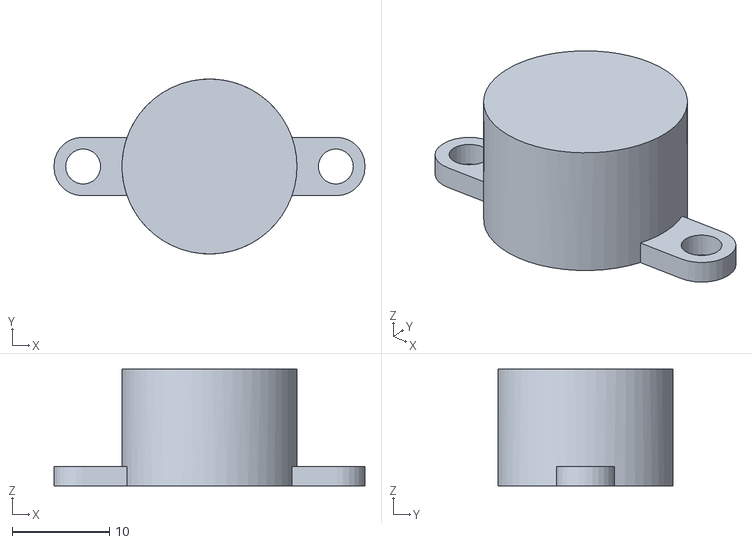
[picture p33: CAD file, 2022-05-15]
mechanical/3DP_reference_cover/manufacturing_data/ref_cover-A.stl
32.0 x 18.0 x 12.0

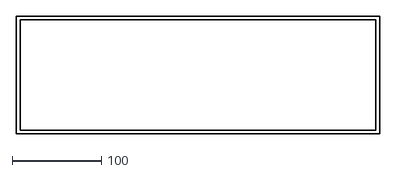
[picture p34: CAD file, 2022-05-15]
mechanical/acryllic_display_cover/fplexi2.dxf
406.8 x 131.8

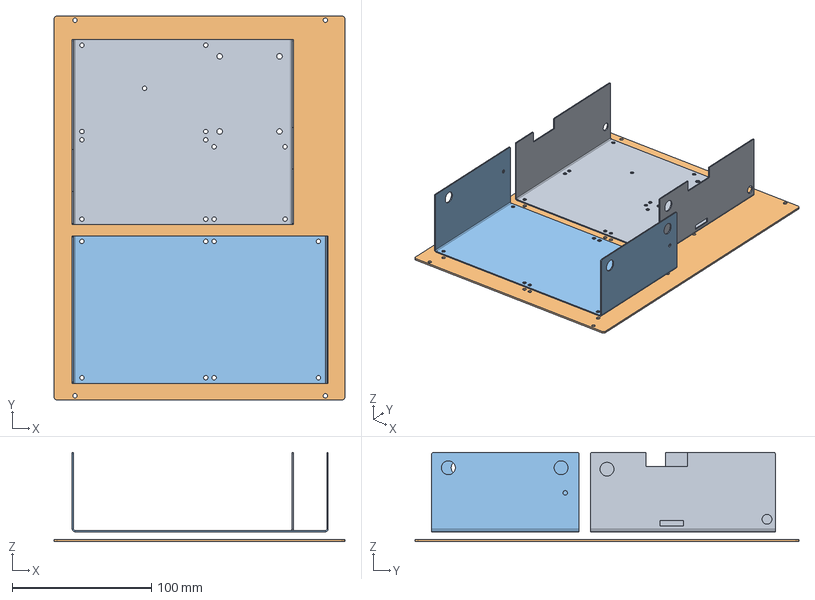
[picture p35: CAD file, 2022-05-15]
mechanical/metal_parts_internal/design_file/inth_1.FCStd
209.0 x 276.0 x 64.0 mm

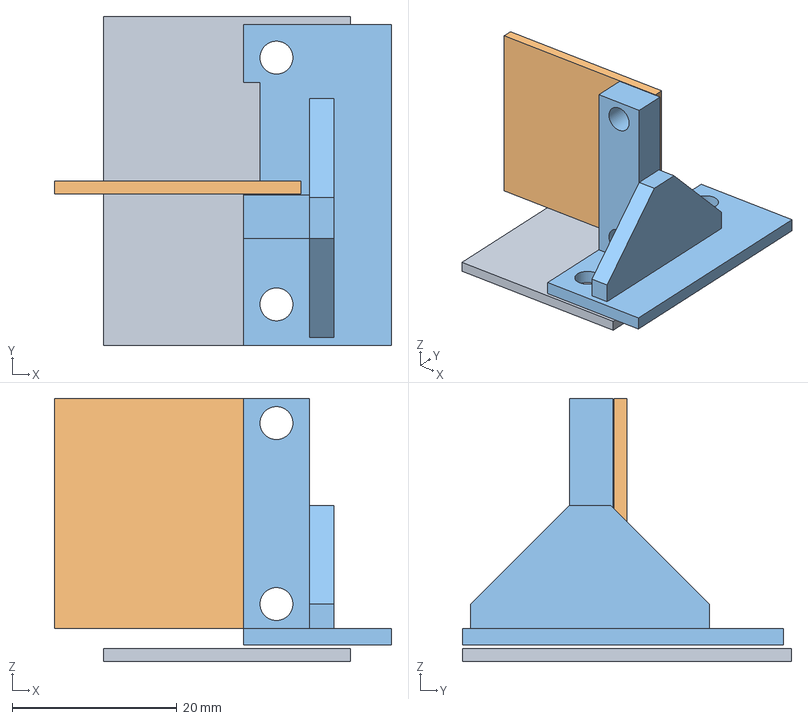
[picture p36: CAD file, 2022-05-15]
mechanical/3DP_back_panel_pcb_holder/holder_com.FCStd
41.0 x 40.0 x 32.0 mm
back_panel
PCB
holder

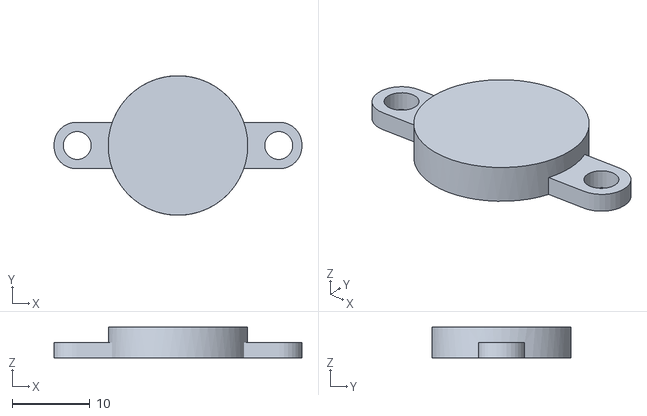
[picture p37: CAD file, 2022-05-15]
mechanical/3DP_reference_cover/manufacturing_data/ref_cover-B.stl
32.0 x 18.0 x 4.00

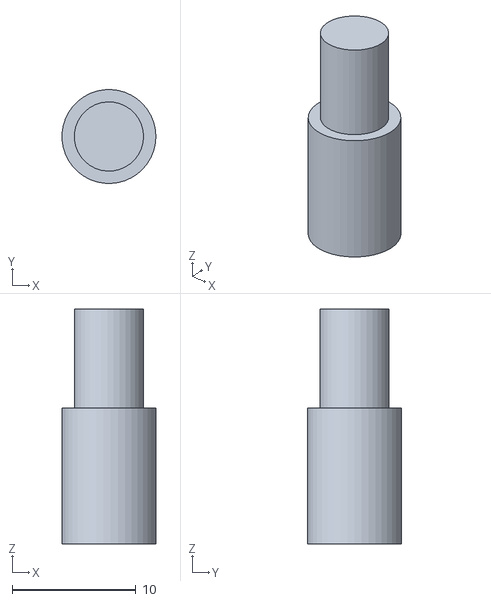
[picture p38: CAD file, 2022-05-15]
mechanical/3DP_pushbutton_assembly/manufacturing_data/pb1-pb.stl
7.59 x 7.59 x 19.0

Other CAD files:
mechanical/3DP_LNA_cover/manufacturing_data/cover_B.stl
mechanical/3DP_pushbutton_assembly/manufacturing_data/pb1-act.stl

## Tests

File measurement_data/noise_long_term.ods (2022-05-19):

raw measured voltage (average of 64 seconds of data) | sensor resistance | voltage with offset, calculated to nV | sensor temperature | 10 points average | 0,433557939618644
V[uV] | R[kOhm] | Vcorr[nV] | T[degree C] | V[nV] 10pt moving avg | 0,06329 | -101,64
0,43339625 | 2,003767 | -0,161689618644156 | 25,17841343 | -0,161689618644156
0,43638 | 2,0036415 | 2,82206038135585 | 25,170470535 | 2,82206038135585
0,42855375 | 2,003941 | -5,00418961864413 | 25,18942589 | -5,00418961864413
0,43265375 | 2,003973 | -0,904189618644136 | 25,19145117 | -0,904189618644136
0,442495 | 2,003795 | 8,93706038135589 | 25,18018555 | 8,93706038135589
0,4307125 | 2,0038365 | -2,84543961864414 | 25,182812085 | -2,84543961864414
0,4318675 | 2,0037775 | -1,69043961864412 | 25,179077975 | -1,69043961864412
0,4323075 | 2,003947 | -1,25043961864413 | 25,18980563 | -1,25043961864413
0,4319275 | 2,003858 | -1,63043961864412 | 25,18417282 | -1,63043961864412
0,43488625 | 2,0041595 | 1,32831038135584 | 25,203254755 | -0,039939618644136
0,43455375 | 2,0039615 | 0,995810381355877 | 25,190723335 | 0,075810381355868
0,44580625 | 2,004081 | 12,2483103813559 | 25,19828649 | 1,01843538135587
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

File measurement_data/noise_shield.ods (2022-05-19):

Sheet: Sheet1
 |  | -0.000122105276471
-1.221067 | -0.0001221067 |  | -1.42352941177979E-09
-1.221036 | -0.0001221036 |  | 1.67647058822024E-09
-1.221051 | -0.0001221051 |  | 1.76470588196618E-10
-1.221092 | -0.0001221092 |  | -3.92352941179204E-09
-1.221097 | -0.0001221097 |  | -4.42352941177281E-09
-1.221021 | -0.0001221021 |  | 3.17647058821675E-09
-1.221011 | -0.0001221011 |  | 4.17647058820539E-09
-1.220976 | -0.0001220976 |  | 7.67647058820629E-09
-1.220976 | -0.0001220976 |  | 7.67647058820629E-09
-1.221041 | -0.0001221041 |  | 1.17647058821236E-09
-1.221092 | -0.0001221092 |  | -3.92352941179204E-09
-1.221077 | -0.0001221077 |  | -2.42352941179553E-09
-1.221067 | -0.0001221067 |  | -1.42352941177979E-09
-1.221102 | -0.0001221102 |  | -4.92352941178068E-09
-1.221057 | -0.0001221057 |  | -4.23529411791145E-10
-1.221062 | -0.0001221062 |  | -9.23529411771913E-10
-1.221041 | -0.0001221041 |  | 1.17647058821236E-09
-1.221092 | -0.0001221092 |  | -3.92352941179204E-09
-1.221082 | -0.0001221082 |  | -2.9235294117763E-09
-1.221036 | -0.0001221036 |  | 1.67647058822024E-09
-1.221077 | -0.0001221077 |  | -2.42352941179553E-09
-1.221127 | -0.0001221127 |  | -7.42352941179294E-09
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

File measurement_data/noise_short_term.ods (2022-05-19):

Number | Time [s] | Voltage [uV] | Offset corrected voltage [nV] | Timestep | Average voltage [uV]
1 | 0,02 | 0,21 | -0,02 | 0,0207 | 0,206720454545455
2 | 0,04 | 0,20 | -3,82
3 | 0,06 | 0,20 | -7,92
4 | 0,08 | 0,21 | -1,52
5 | 0,10 | 0,20 | -3,72
6 | 0,12 | 0,20 | -7,32
7 | 0,14 | 0,21 | -1,32
8 | 0,17 | 0,21 | 0,28
9 | 0,19 | 0,21 | -0,52
10 | 0,21 | 0,20 | -1,82
11 | 0,23 | 0,21 | -0,22
12 | 0,25 | 0,21 | 6,58
13 | 0,27 | 0,21 | 6,08
14 | 0,29 | 0,21 | 3,98
15 | 0,31 | 0,21 | 3,98
16 | 0,33 | 0,21 | 0,68
17 | 0,35 | 0,21 | -1,22
18 | 0,37 | 0,20 | -2,22
19 | 0,39 | 0,21 | -1,32
20 | 0,41 | 0,21 | -0,52
21 | 0,43 | 0,21 | 0,18
22 | 0,46 | 0,20 | -1,82
23 | 0,48 | 0,20 | -1,92
24 | 0,50 | 0,21 | 2,88
25 | 0,52 | 0,21 | 4,58
26 | 0,54 | 0,21 | 1,58
27 | 0,56 | 0,21 | -1,52
28 | 0,58 | 0,21 | -0,82
29 | 0,60 | 0,21 | -0,02
30 | 0,62 | 0,21 | -1,12
31 | 0,64 | 0,21 | -0,92
32 | 0,66 | 0,21 | 0,58
33 | 0,68 | 0,20 | -2,22
34 | 0,70 | 0,20 | -4,62
35 | 0,72 | 0,20 | -4,92
36 | 0,75 | 0,20 | -10,12
37 | 0,77 | 0,20 | -8,02
38 | 0,79 | 0,20 | -4,72
39 | 0,81 | 0,20 | -7,72
40 | 0,83 | 0,20 | -9,12
41 | 0,85 | 0,20 | -10,82
42 | 0,87 | 0,20 | -6,32
43 | 0,89 | 0,21 | 1,88
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

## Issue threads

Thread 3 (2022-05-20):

noise measurements at longer integration times.

pavel212, 2022-05-20:
Long term stability measurements 'lnoise.png' shows drifts (temperature?) for a few nanovolts,
While measurements with ~1sec averaging could reach <=1nV noise level,
Would be interesting to see what happens in between, so maybe you could repeat 'lnoise.png' measurements, but with averaging of
1 second, not 64.

comparison with other voltmeters
https://github.com/pavel212/noise

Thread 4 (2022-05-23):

missing schematic

immortal-sniper1, 2022-05-23:
I was looking through LISA and i didnt find the W5500 breakout not any reference of where it came from ( as in from another repository)

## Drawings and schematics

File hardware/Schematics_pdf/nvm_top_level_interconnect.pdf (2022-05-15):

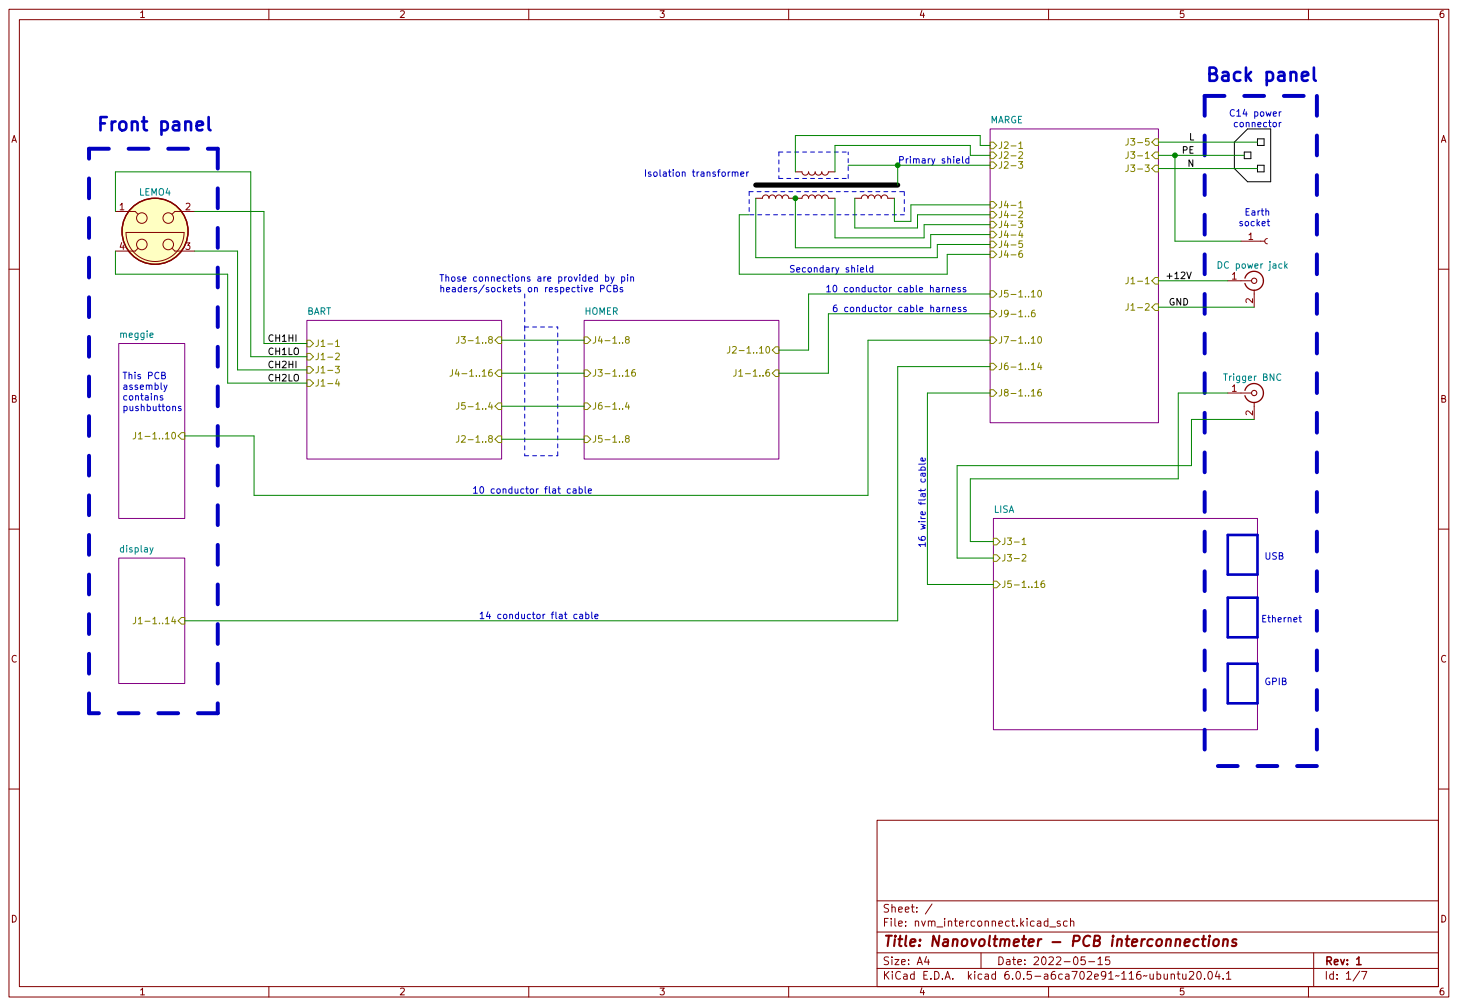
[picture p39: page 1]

6 conductor cable harness Primary shield

Those connections are provided by pin

File: nvm_interconnect.kicad_sch Sheet: /
Id: 1/7 Title: Nanovoltmeter - PCB interconnections

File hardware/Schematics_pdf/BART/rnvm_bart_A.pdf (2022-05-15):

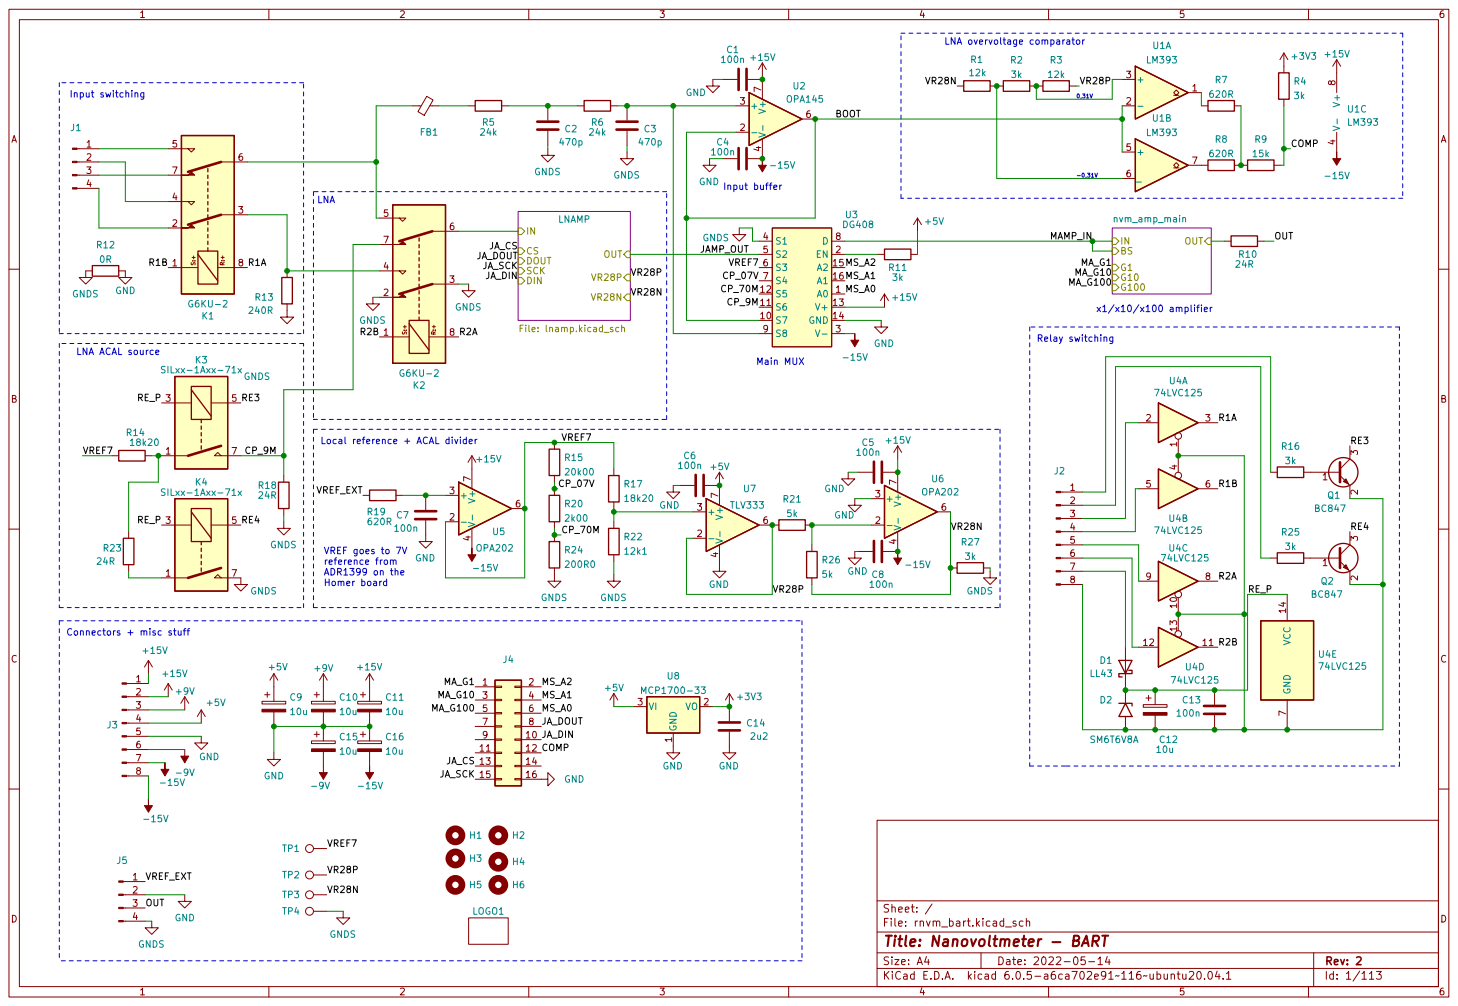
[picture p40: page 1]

File: rnvm_bart.kicad_sch Sheet: /
Id: 1/113 Title: Nanovoltmeter - BART

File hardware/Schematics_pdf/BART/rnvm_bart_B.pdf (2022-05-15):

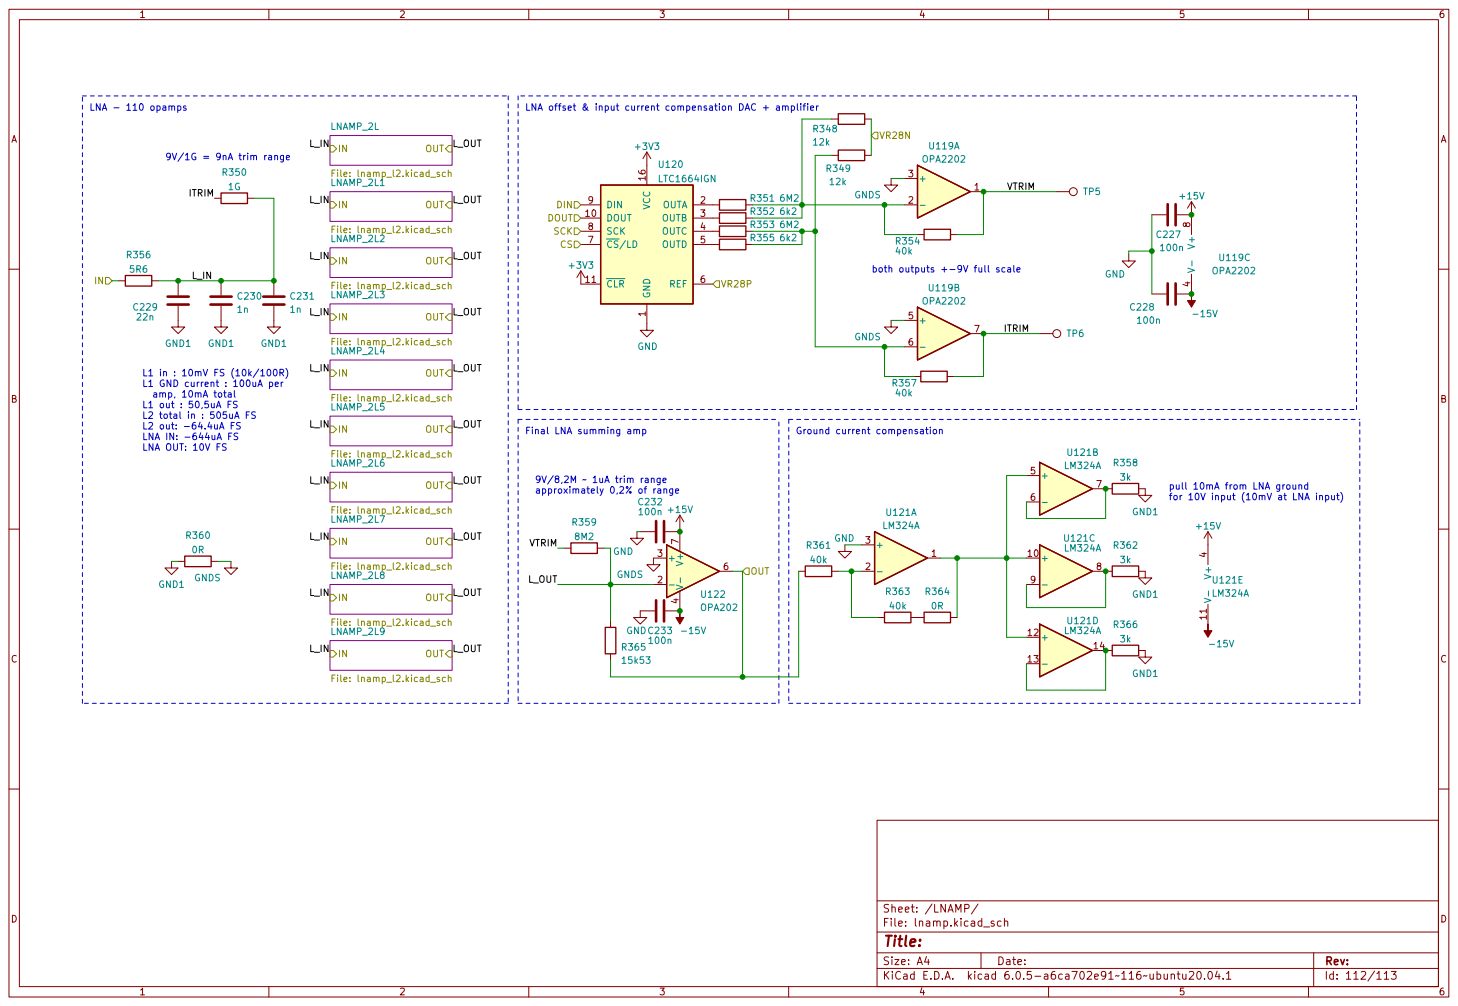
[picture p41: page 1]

LNA offset & input current compensation DAC + amplifier

1 DOUT 10 ~{CLR} 11 VCC 16 OUTA 2 OUTB 3 OUTC 4 OUTD 5 REF 6 ~{CS}/LD 7 SCK 8 DIN 9 U120

L1 GND current : 100uA per
amp, 10mA total L1 out : 50,5uA FS

Final LNA summing amp

pull 10mA from LNA ground
for 10V input (10mV at LNA input)

File: lnamp.kicad_sch Sheet: /LNAMP/
Id: 112/113 Title:

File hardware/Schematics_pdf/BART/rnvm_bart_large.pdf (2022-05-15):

File: rnvm_bart.kicad_sch Sheet: /
Id: 1/113 Title: Nanovoltmeter - BART

This amplifier block is indeed 100 times repeated on the PCB, so it's logical to have it in the schematics, too. Sorry for that.

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

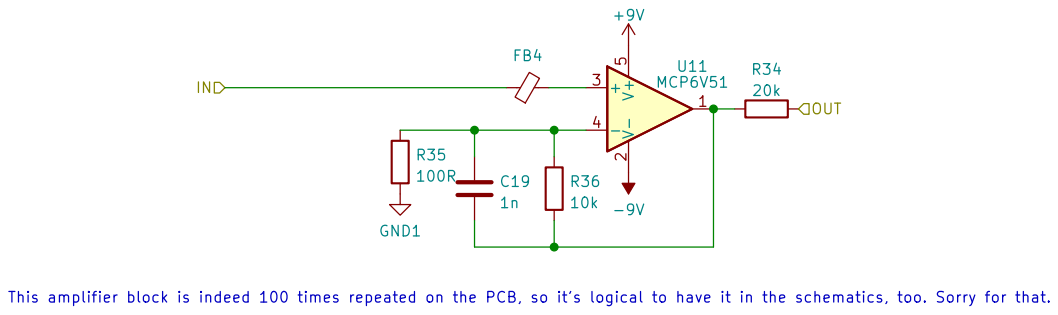
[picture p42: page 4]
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

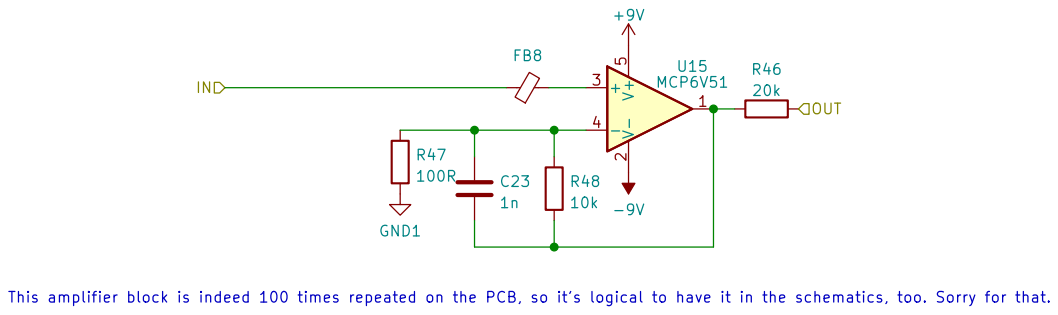
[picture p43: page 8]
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

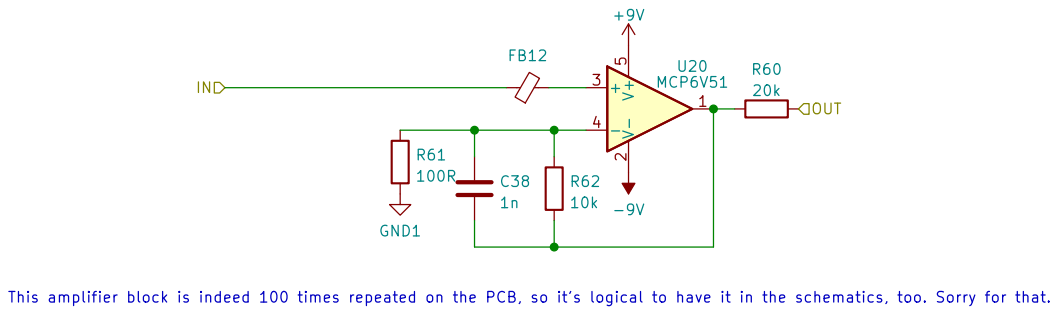
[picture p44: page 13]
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

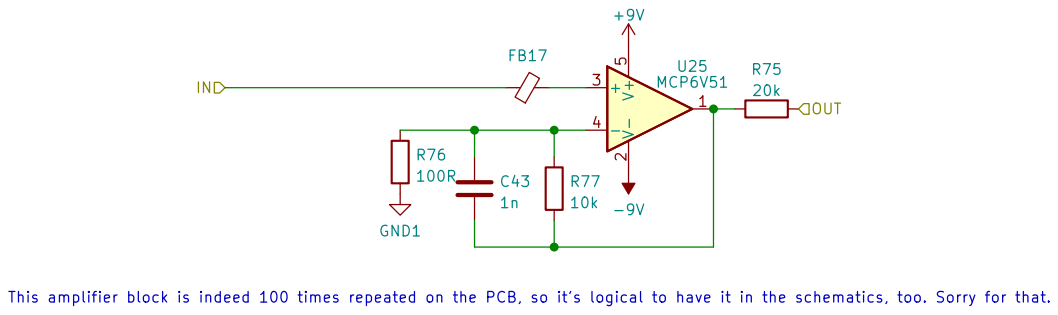
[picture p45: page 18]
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

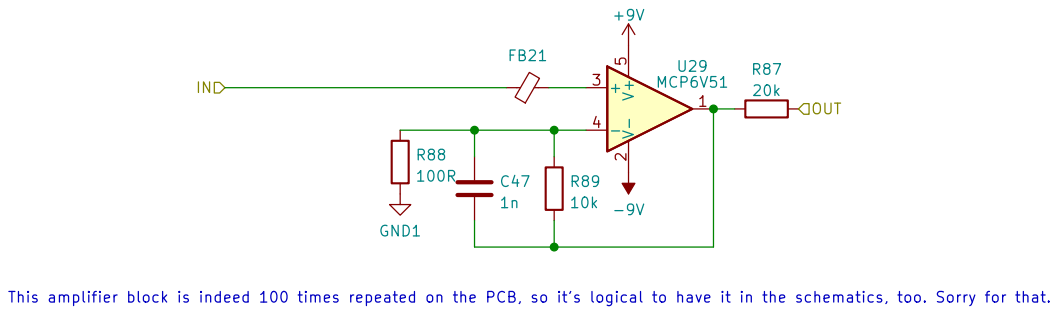
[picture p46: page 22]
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

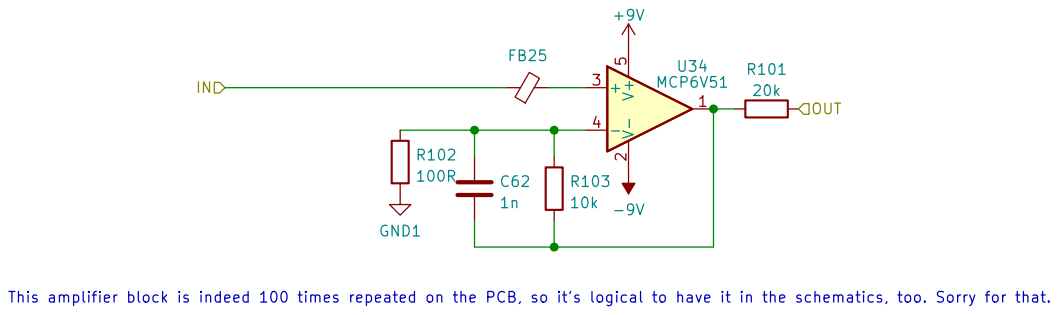
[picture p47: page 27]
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

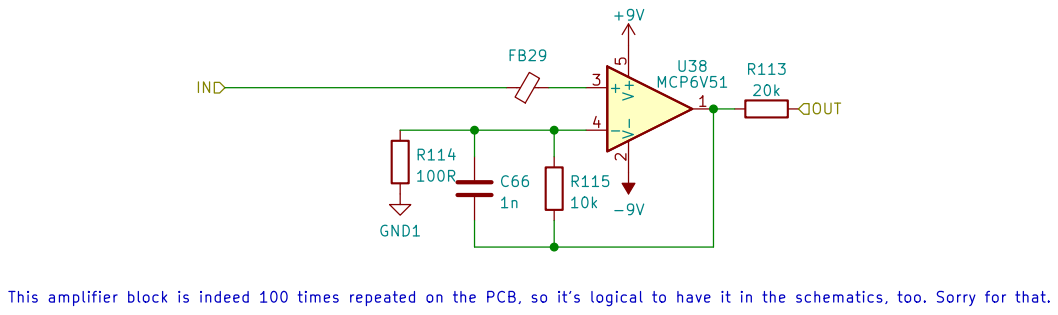
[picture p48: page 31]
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

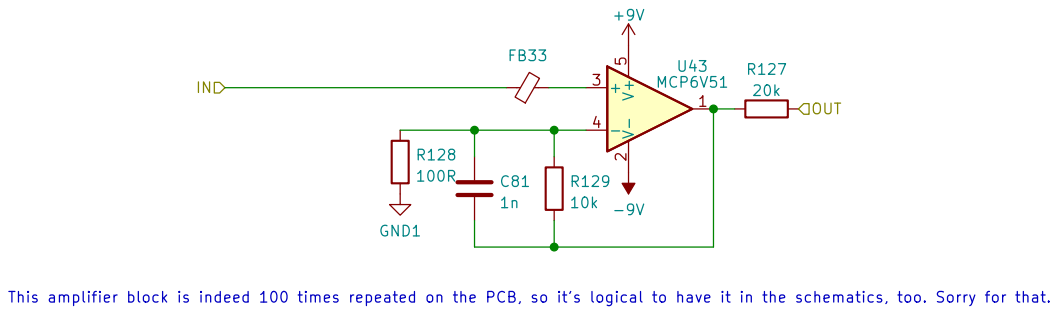
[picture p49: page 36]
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

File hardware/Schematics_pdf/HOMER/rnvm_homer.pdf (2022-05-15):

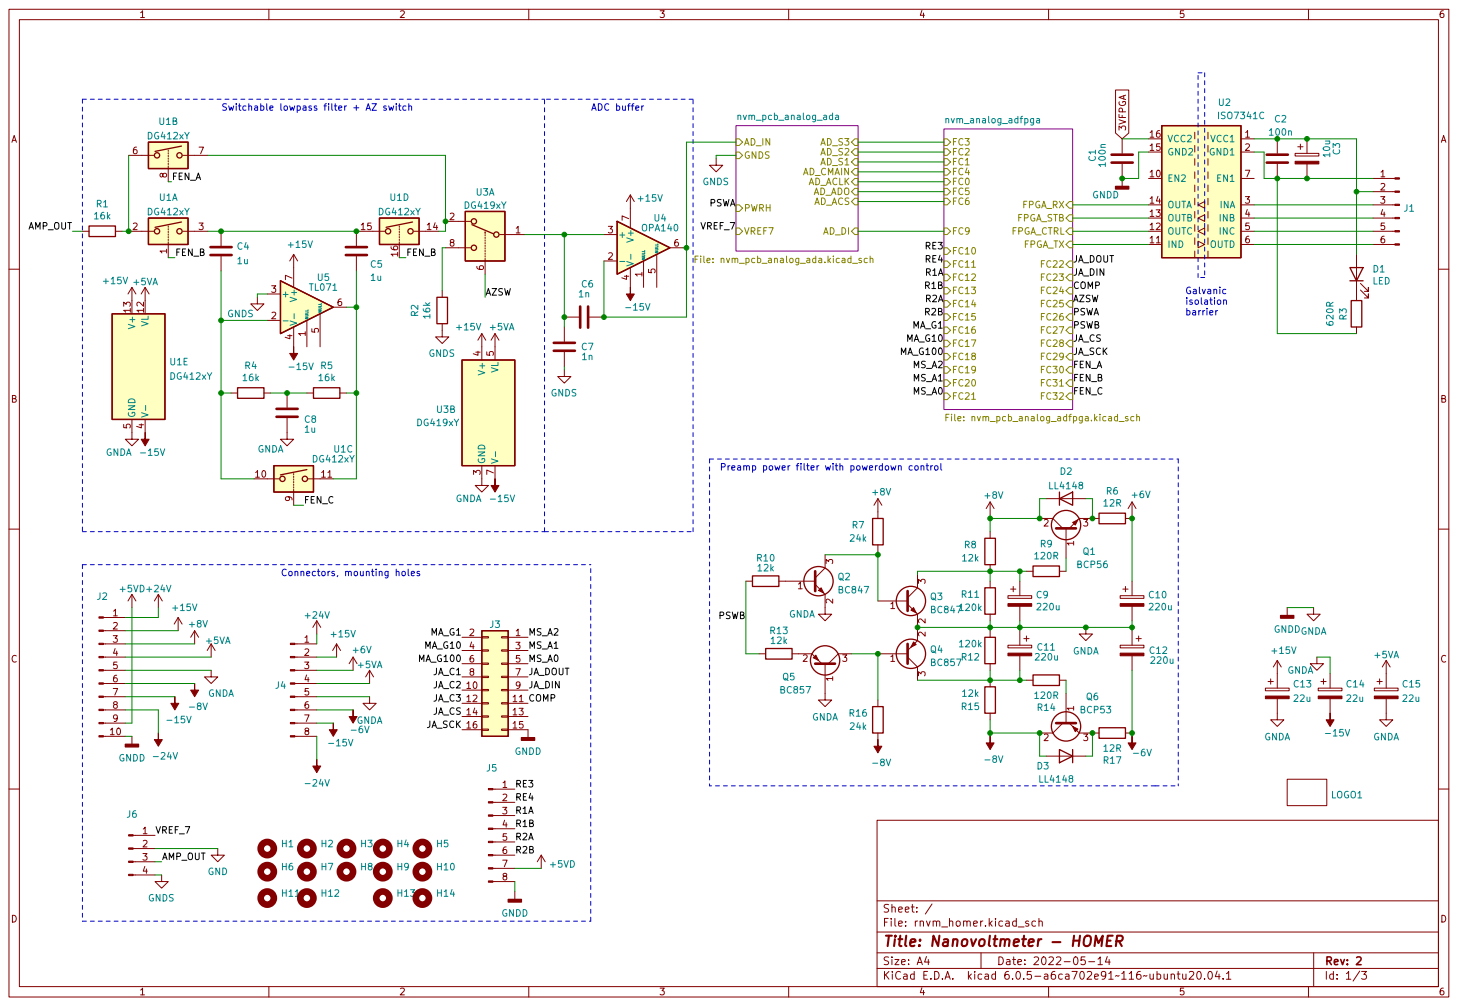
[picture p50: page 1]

barrier Preamp power filter with powerdown control ADC buffer Connectors, mounting holes

File: rnvm_homer.kicad_sch Sheet: /
Id: 1/3 Title: Nanovoltmeter - HOMER


Current steering Reference source

Residual charge amp + ADC

1 VO 2 VI 3 U14 DNP-MCP1700-18 GNDA GNDA GNDA C23

7 VOS 8 U15 OPA202 GNDA GNDA GNDA C27

Alternative residual charge ADC, not populated ADR1399 used here. LM399 will work too, with R49=7k


* do not mount R52 For ZC version

4 X1 SG-5032CANGNDD GNDD GNDD GNDD

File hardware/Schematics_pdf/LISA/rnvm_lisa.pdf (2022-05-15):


Ethernet breakout TRIG input

Connector to Marge board

6 | | 18
7 | | 19
8 | | 20
9 | | 21

File: rnvm_lisa.kicad_sch Sheet: / GND

1 ~{DSR} 10 ~{RI} 11 ~{DCD} 12 ~{DTR} 13 ~{RTS} 14 R232 VCC 15 16 TXD 2 RXD 3 V3

4 UD+ 5 UD- 6 XI 7 XO 8 ~{CTS} 9 U6 CH340G

Id: 1/1 Title: Nanovoltmeter - LISA

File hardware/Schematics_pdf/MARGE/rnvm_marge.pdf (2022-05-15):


Id: 1/4 Title: Nanovoltmeter - MARGE



Keyboard connector (to Meggie PCB)

4 MOSI 5 SCK 6 ~{HOLD} 7 VCC



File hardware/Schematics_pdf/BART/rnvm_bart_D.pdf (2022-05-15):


Floating PSU for input opamp


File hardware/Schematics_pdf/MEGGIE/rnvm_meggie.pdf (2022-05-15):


Id: 1/1 Title: Nanovoltmeter - MEGGIE

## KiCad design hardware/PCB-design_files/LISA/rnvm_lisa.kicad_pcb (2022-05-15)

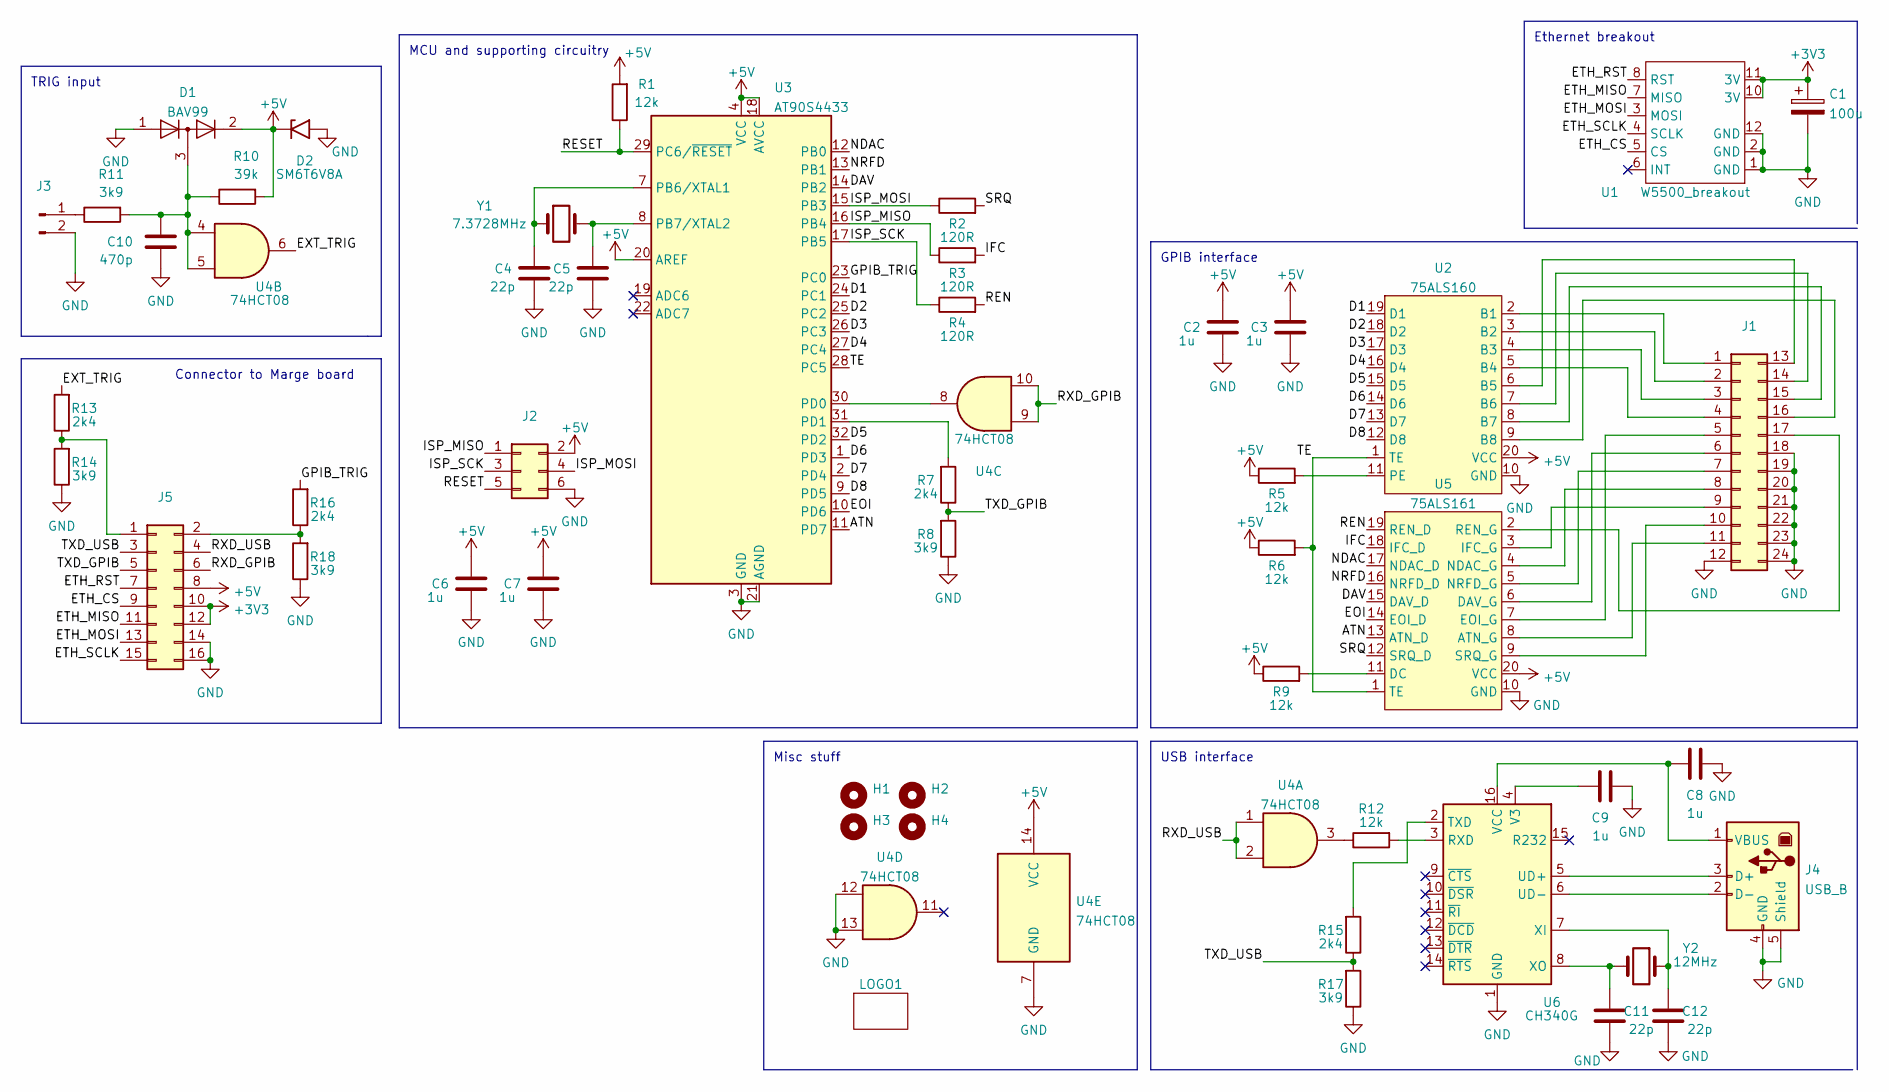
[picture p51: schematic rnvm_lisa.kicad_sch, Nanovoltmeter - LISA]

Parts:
C1: 100u; CP_EIA-7132-28_AVX-C_Pad2.72x3.50mm_HandSolder
C2, C3, C6, C7, C8, C9: 1u; C_0805_2012Metric_Pad1.18x1.45mm_HandSolder
C4, C5, C11, C12: 22p; C_0805_2012Metric_Pad1.18x1.45mm_HandSolder
C10: 470p; C_0805_2012Metric_Pad1.18x1.45mm_HandSolder
D1: BAV99; SOT-23
D2: SM6T6V8A; D_SMB
H1, H2, H3, H4: MountingHole; MountingHole_3.2mm_M3_DIN965_Pad
J1: Centronics 24, socket; CENTR_24P_F
J2: IDC_6pin; IDC-Header_2x03_P2.54mm_Vertical
J3: Conn_01x02_Male; Molex_KK-254_AE-6410-02A_1x02_P2.54mm_Vertical
J4: USB_B; USB_B_Lumberg_2411_02_Horizontal
J5: IDC_16; IDC-Header_2x08_P2.54mm_Vertical
LOGO1: PCB logo; logo_rpg7x9
R1, R5, R6, R9, R12: 12k; R_MiniMELF_MMA-0204
R2, R3, R4: 120R; R_MiniMELF_MMA-0204
R7, R13, R15, R16: 2k4; R_MiniMELF_MMA-0204
R8, R11, R14, R17, R18: 3k9; R_MiniMELF_MMA-0204
R10: 39k; R_MiniMELF_MMA-0204
U1: W5500_breakout; W5500_bo
U2: 75ALS160; SOIC-20W_7.5x12.8mm_P1.27mm
U3: AT90S4433; TQFP-32_7x7mm_P0.8mm
U4: 74HCT08; TSSOP-14_4.4x5mm_P0.65mm
U5: 75ALS161; SOIC-20W_7.5x12.8mm_P1.27mm
U6: CH340G; SOIC-16_3.9x9.9mm_P1.27mm
Y1: 7.3728MHz; Crystal_SMD_HC49-SD
Y2: 12MHz; Crystal_SMD_HC49-SD

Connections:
+3V3: C1.1, J5.10, J5.12, U1.10 (3V), U1.11 (3V)
+5V: C2.2, C3.2, C6.2, C7.2, D1.2 (A), D2.1 (A1), J2.2, J5.8, R1.2, R5.1, R6.1, R9.1, R10.2, U2.20 (VCC), U3.4 (VCC), U3.6 (VCC), U3.18 (AVCC), U3.20 (AREF), U4.14 (VCC), U5.20 (VCC)
/ATN: U3.11 (PD7), U5.13 (ATN_D)
/D1: U2.19 (D1), U3.24 (PC1)
/D2: U2.18 (D2), U3.25 (PC2)
/D3: U2.17 (D3), U3.26 (PC3)
/D4: U2.16 (D4), U3.27 (PC4)
/D5: U2.15 (D5), U3.32 (PD2)
/D6: U2.14 (D6), U3.1 (PD3)
/D7: U2.13 (D7), U3.2 (PD4)
/D8: U2.12 (D8), U3.9 (PD5)
/DAV: U3.14 (PB2), U5.15 (DAV_D)
/EOI: U3.10 (PD6), U5.14 (EOI_D)
/ETH_CS: J5.9, U1.5 (CS)
/ETH_MISO: J5.11, U1.7 (MISO)
/ETH_MOSI: J5.13, U1.3 (MOSI)
/ETH_RST: J5.7, U1.8 (RST)
/ETH_SCLK: J5.15, U1.4 (SCLK)
/EXT_TRIG: R13.2, U4.6
/GPIB_TRIG: R16.2, U3.23 (PC0)
/IFC: R3.2, U5.18 (IFC_D)
/ISP_MISO: J2.1, R3.1, U3.16 (PB4)
/ISP_MOSI: J2.4, R2.1, U3.15 (PB3)
/ISP_SCK: J2.3, R4.1, U3.17 (PB5)
/NDAC: U3.12 (PB0), U5.17 (NDAC_D)
/NRFD: U3.13 (PB1), U5.16 (NRFD_D)
/REN: R4.2, U5.19 (REN_D)
/RESET: J2.5, R1.1, U3.29 (PC6/~RESET)
/RXD_GPIB: J5.6, U4.9, U4.10
/RXD_USB: J5.4, U4.1, U4.2
/SRQ: R2.2, U5.12 (SRQ_D)
/TE: R6.2, U2.1 (TE), U3.28 (PC5), U5.1 (TE)
/TXD_GPIB: J5.5, R7.1, R8.2
/TXD_USB: J5.3, R15.1, R17.2
GND: C1.2, C2.1, C3.1, C4.2, C5.2, C6.1, C7.1, C8.2, C9.2, C10.2, C11.2, C12.2, D1.1 (K), D2.2 (A2), J1.12, J1.18, J1.19, J1.20, J1.21, J1.22, J1.23, J1.24, J2.6, J3.2, J4.4 (GND), J4.5 (Shield), J5.14, J5.16, R8.1, R14.1, R17.1, R18.1, U1.1 (GND), U1.2 (GND), U1.12 (GND), U2.10 (GND), U3.3 (GND), U3.5 (GND), U3.21 (AGND), U4.7 (GND), U4.12, U4.13, U5.10 (GND), U6.1 (GND)
unnamed: C4.1, U3.7 (PB6/XTAL1), Y1.1
unnamed: C5.1, U3.8 (PB7/XTAL2), Y1.2
unnamed: C8.1, J4.1 (VBUS), U6.16 (VCC)
unnamed: C9.1, U6.4 (V3)
unnamed: C10.1, D1.3 (K), R10.1, R11.2, U4.4, U4.5
unnamed: C11.1, U6.8 (XO), Y2.2
unnamed: C12.1, U6.7 (XI), Y2.1
unnamed: J1.1, U2.2 (B1)
unnamed: J1.2, U2.3 (B2)
unnamed: J1.3, U2.4 (B3)
unnamed: J1.4, U2.5 (B4)
unnamed: J1.5, U5.7 (EOI_G)
unnamed: J1.6, U5.6 (DAV_G)
unnamed: J1.7, U5.5 (NRFD_G)
unnamed: J1.8, U5.4 (NDAC_G)
unnamed: J1.9, U5.3 (IFC_G)
unnamed: J1.10, U5.9 (SRQ_G)
unnamed: J1.11, U5.8 (ATN_G)
unnamed: J1.13, U2.6 (B5)
unnamed: J1.14, U2.7 (B6)
unnamed: J1.15, U2.8 (B7)
unnamed: J1.16, U2.9 (B8)
unnamed: J1.17, U5.2 (REN_G)
unnamed: J3.1, R11.1
unnamed: J4.2 (D-), U6.6 (UD-)
unnamed: J4.3 (D+), U6.5 (UD+)
unnamed: J5.1, R13.1, R14.2
unnamed: J5.2, R16.1, R18.2
unnamed: R5.2, U2.11 (PE)
unnamed: R7.2, U3.31 (PD1)
unnamed: R9.2, U5.11 (DC)
unnamed: R12.1, U4.3
unnamed: R12.2, U6.3 (RXD)
unnamed: R15.2, U6.2 (TXD)
unnamed: U3.30 (PD0), U4.8

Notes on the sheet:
MCU and supporting circuitry
Connector to Marge board
Misc stuff
USB interface
TRIG input
Ethernet breakout
GPIB interface

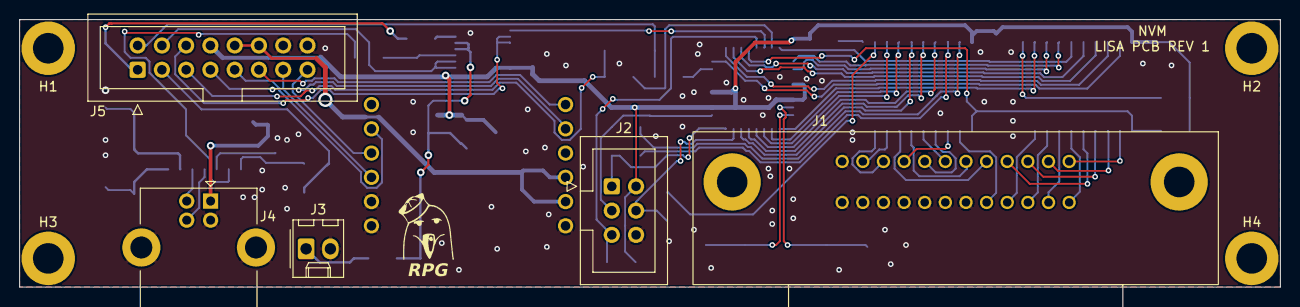
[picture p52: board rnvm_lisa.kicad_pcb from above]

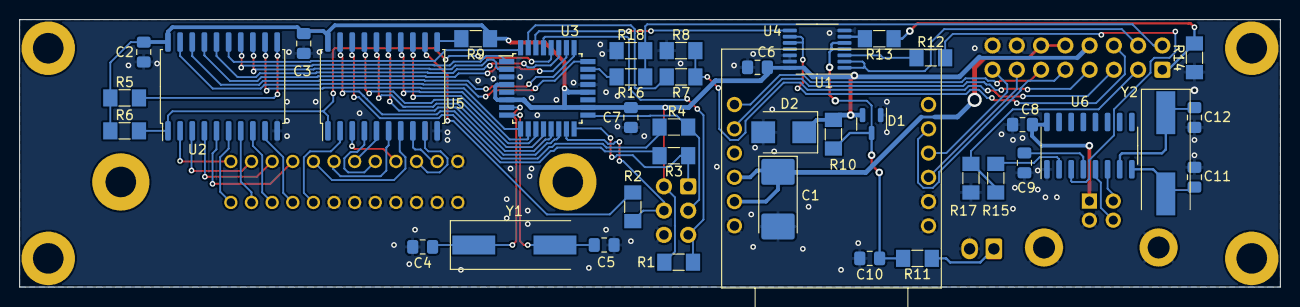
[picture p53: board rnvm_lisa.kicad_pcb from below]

Board: 2 copper layers, 132.0 x 28.0 mm, 50 parts (40 on the bottom side), 70 nets.

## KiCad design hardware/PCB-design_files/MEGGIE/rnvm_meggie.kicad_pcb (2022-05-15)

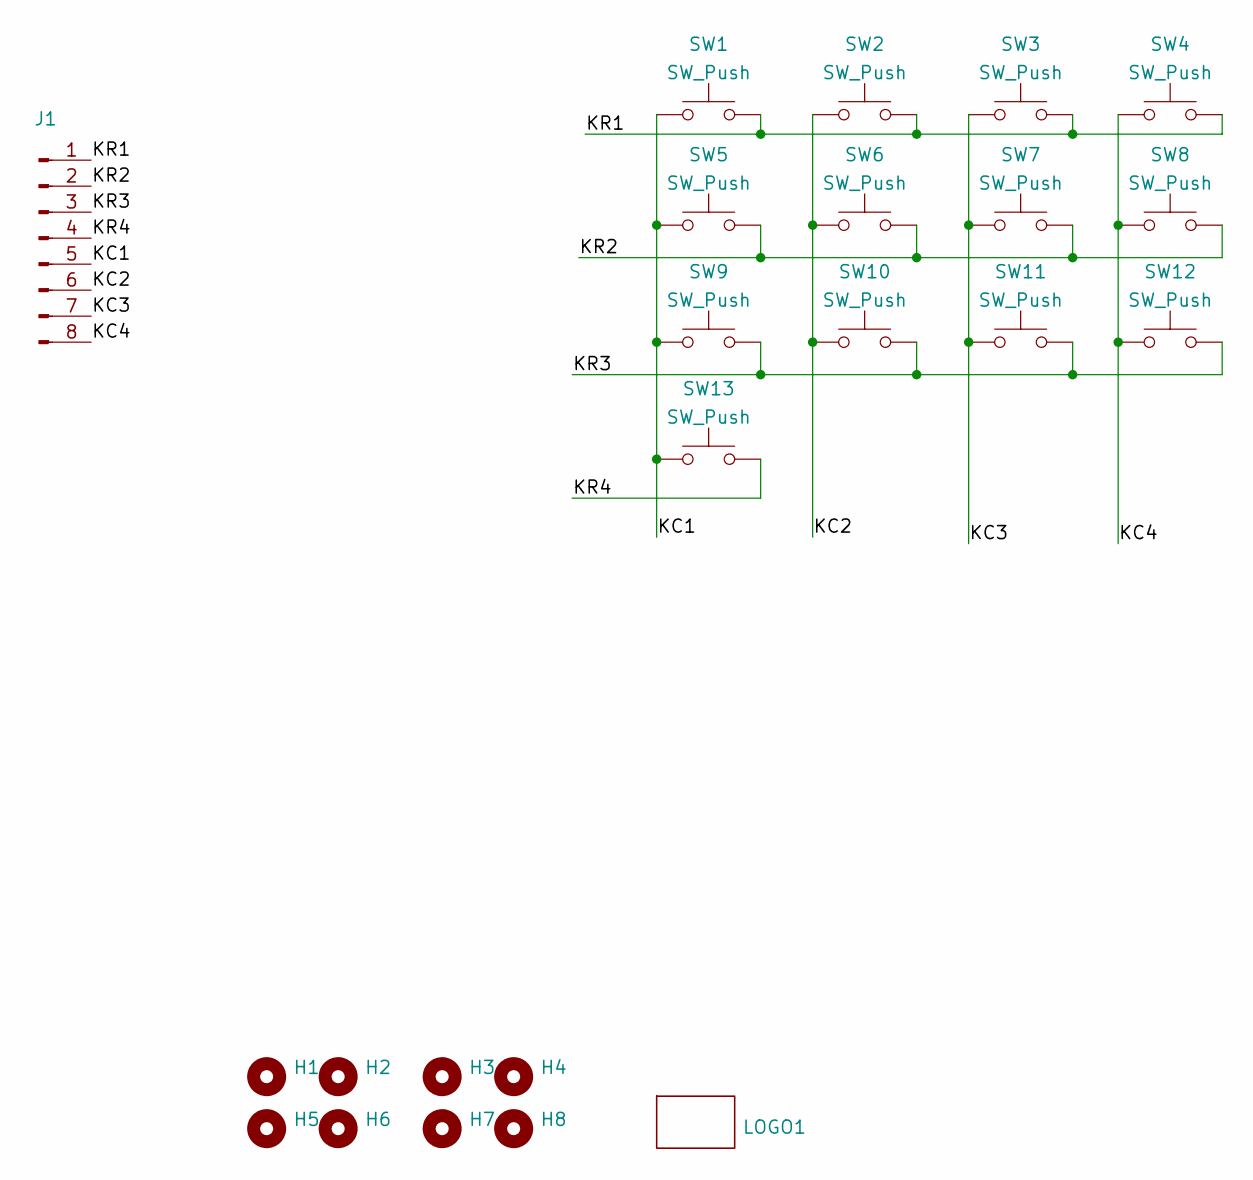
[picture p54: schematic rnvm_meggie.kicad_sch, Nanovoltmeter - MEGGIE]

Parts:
H1, H2, H5, H6: MountingHole; MountingHole_2.5mm_Pad
H3, H4, H7, H8: MountingHole; MountingHole_3.2mm_M3_DIN965_Pad
J1: Conn_01x08_Male; Molex_KK-254_AE-6410-08A_1x08_P2.54mm_Vertical
LOGO1: logo_generic; logo_rpg7x9
SW1, SW2, SW3, SW4, SW5, SW6, SW7, SW8, SW9, SW10, SW11, SW12, SW13: SW_Push; MQ_6450

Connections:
/KC1: J1.5, SW1.1, SW5.1, SW9.1, SW13.1
/KC2: J1.6, SW2.1, SW6.1, SW10.1
/KC3: J1.7, SW3.1, SW7.1, SW11.1
/KC4: J1.8, SW4.1, SW8.1, SW12.1
/KR1: J1.1, SW1.2, SW2.2, SW3.2, SW4.2
/KR2: J1.2, SW5.2, SW6.2, SW7.2, SW8.2
/KR3: J1.3, SW9.2, SW10.2, SW11.2, SW12.2
/KR4: J1.4, SW13.2

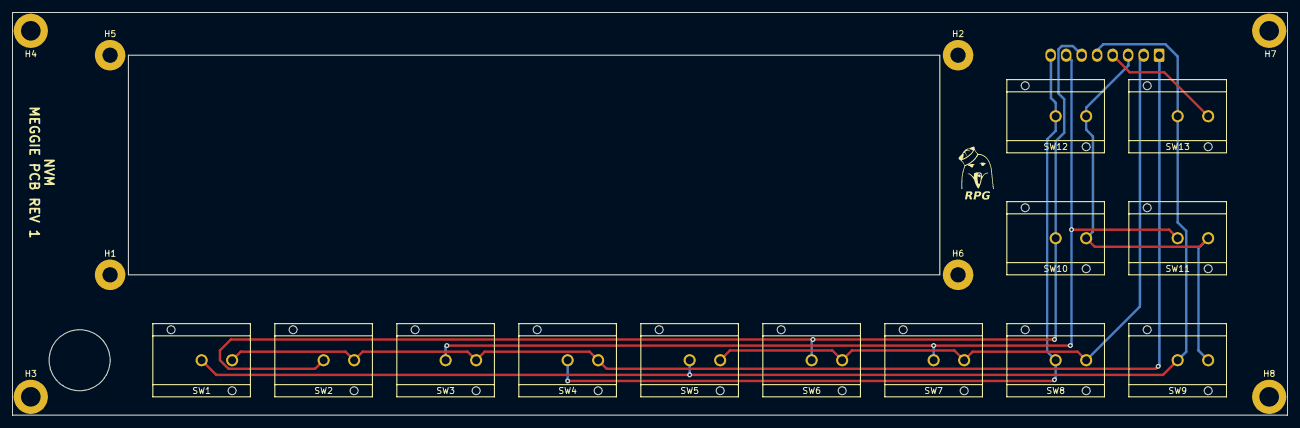
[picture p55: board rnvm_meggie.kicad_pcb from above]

Board: 2 copper layers, 209.0 x 66.0 mm, 23 parts (1 on the bottom side), 8 nets.

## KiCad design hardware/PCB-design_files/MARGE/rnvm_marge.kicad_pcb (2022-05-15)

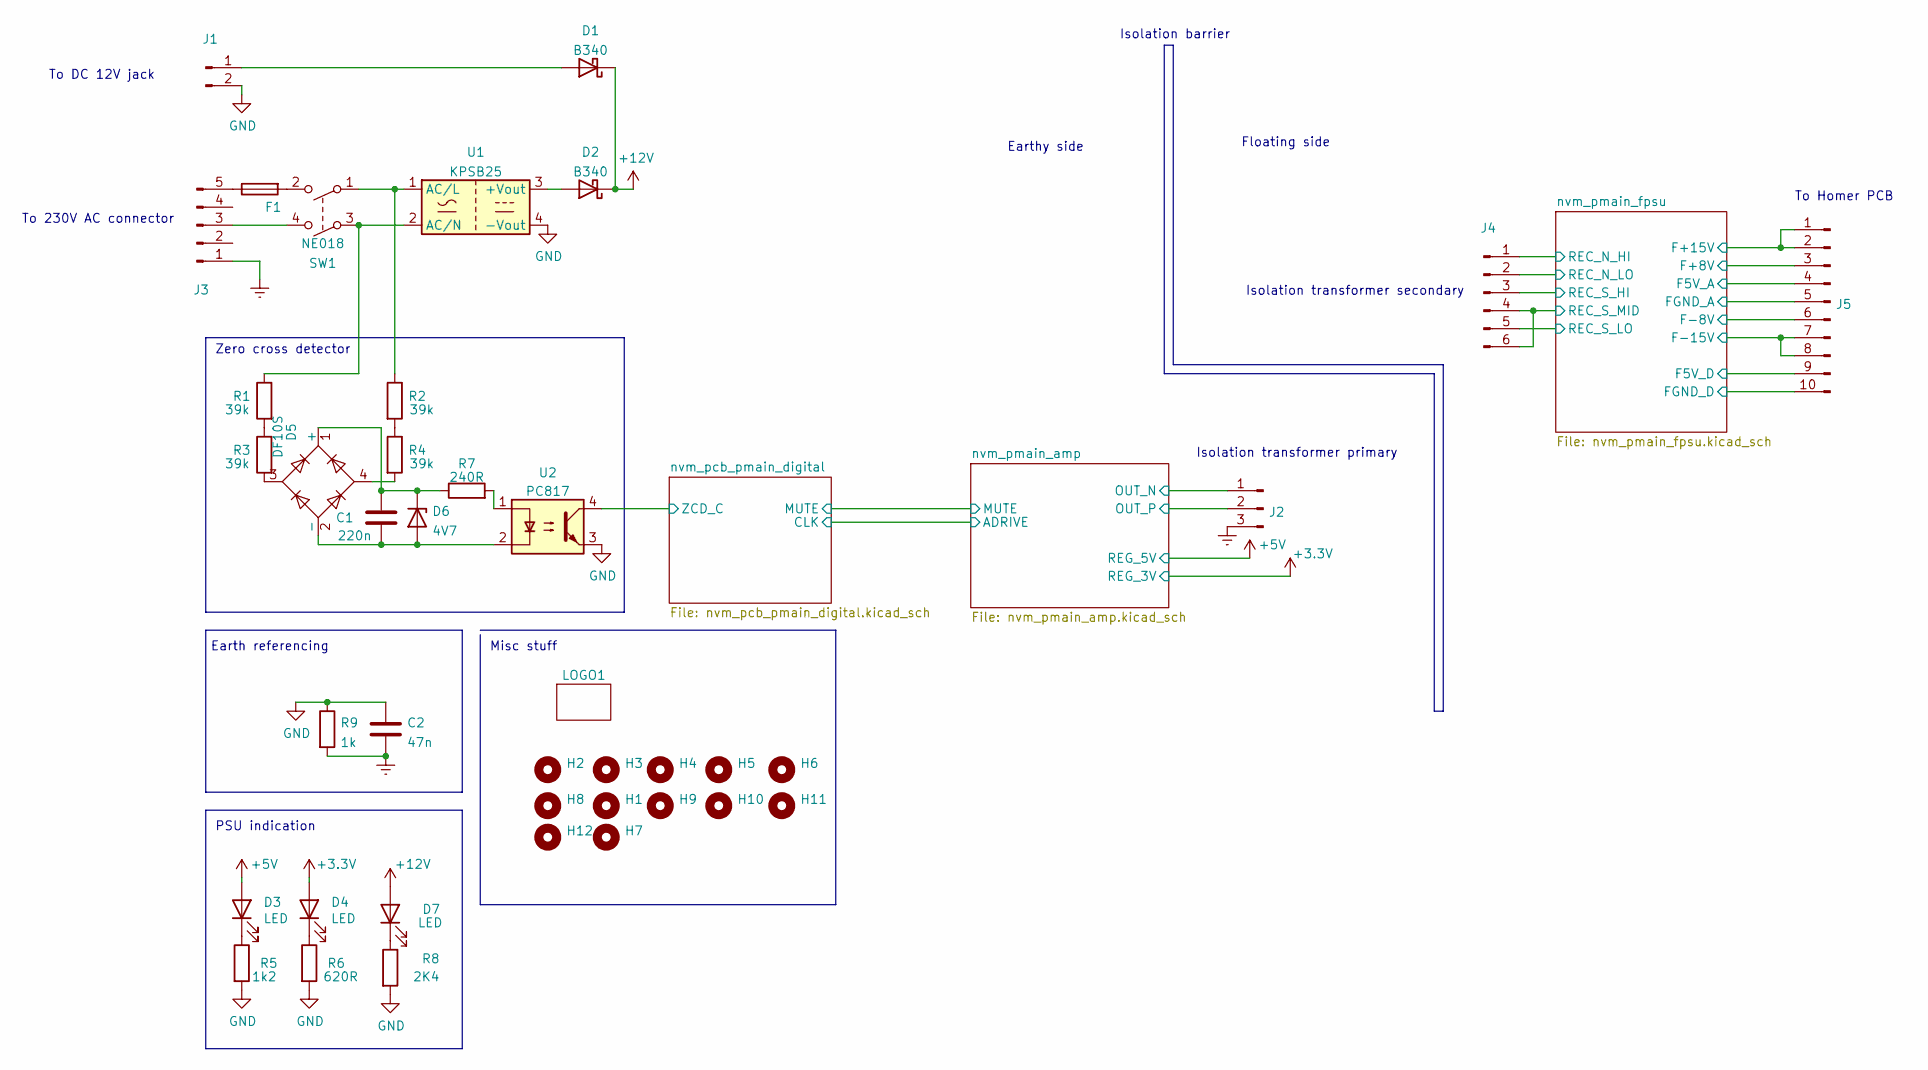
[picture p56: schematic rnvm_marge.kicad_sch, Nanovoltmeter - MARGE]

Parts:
C1: 220n; C_0805_2012Metric_Pad1.18x1.45mm_HandSolder
C2: 47n; C_Rect_L18.0mm_W6.0mm_P15.00mm_FKS3_FKP3
D1, D2: B340; D_SMC
D3, D4, D7: LED; LED_0805_2012Metric_Pad1.15x1.40mm_HandSolder
D5: DF10S; Diode_Bridge_Diotec_SO-DIL-Slim
D6: 4V7; D_MiniMELF
F1: Fuse; Fuseholder_Cylinder-5x20mm_Schurter_0031_8201_Horizontal_Op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
H1, H7, H12: MountingHole; MountingHole_3.2mm_M3_DIN965_Pad
H2, H3, H4, H5, H6, H8, H9, H10, H11: MountingHole; MountingHole_3.2mm_M3
J1: Conn_01x02_Male; Molex_KK-396_A-41791-0002_1x02_P3.96mm_Vertical
J2: Conn_01x03_Male; Molex_KK-396_A-41791-0003_1x03_P3.96mm_Vertical
J3: Conn_01x05_Male; Molex_KK-396_A-41791-0005_1x05_P3.96mm_Vertical
J4: Conn_01x06_Male; Molex_KK-396_A-41791-0006_1x06_P3.96mm_Vertical
J5: Conn_01x10_Male; Molex_KK-254_AE-6410-10A_1x10_P2.54mm_Vertical
LOGO1: logo_generic; logo_rpg7x9
R1, R2, R3, R4: 39k; R_MiniMELF_MMA-0204
R5: 1k2; R_MiniMELF_MMA-0204
R6: 620R; R_MiniMELF_MMA-0204
R7: 240R; R_MiniMELF_MMA-0204
R8: 2K4; R_MiniMELF_MMA-0204
R9: 1k; R_Axial_DIN0411_L9.9mm_D3.6mm_P12.70mm_Horizontal
SW1: NE018; NE18-2P
U1: KPSB25
U2: PC817; SMDIP-4_W9.53mm

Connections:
+3V3: D4.2 (A); also elsewhere on the board
+5V: D3.2 (A); also elsewhere on the board
+12V: D1.1 (K), D2.1 (K), D7.2 (A); also elsewhere on the board
/nvm_pcb_pmain_digital/ZCD_C: U2.4; also elsewhere on the board
/nvm_pmain_amp/OUT_N: J2.1; also elsewhere on the board
/nvm_pmain_amp/OUT_P: J2.2; also elsewhere on the board
/nvm_pmain_fpsu/F5V_A: J5.4; also elsewhere on the board
/nvm_pmain_fpsu/F5V_D: J5.9; also elsewhere on the board
/nvm_pmain_fpsu/F+8V: J5.3; also elsewhere on the board
/nvm_pmain_fpsu/F+15V: J5.1, J5.2; also elsewhere on the board
/nvm_pmain_fpsu/F-8V: J5.6; also elsewhere on the board
/nvm_pmain_fpsu/F-15V: J5.7, J5.8; also elsewhere on the board
/nvm_pmain_fpsu/FGND_A: J5.5; also elsewhere on the board
/nvm_pmain_fpsu/FGND_D: J5.10; also elsewhere on the board
/nvm_pmain_fpsu/REC_N_HI: J4.1; also elsewhere on the board
/nvm_pmain_fpsu/REC_N_LO: J4.2; also elsewhere on the board
/nvm_pmain_fpsu/REC_S_HI: J4.3; also elsewhere on the board
/nvm_pmain_fpsu/REC_S_LO: J4.5; also elsewhere on the board
/nvm_pmain_fpsu/REC_S_MID: J4.4, J4.6; also elsewhere on the board
Earth: C2.2, J2.3, J3.1, R9.2
GND: C2.1, J1.2, R5.2, R6.2, R8.2, R9.1, U1.4 (-Vout), U2.3; also elsewhere on the board
unnamed: C1.1, D5.2 (-), D6.2 (A), U2.2
unnamed: C1.2, D5.1 (+), D6.1 (K), R7.1
unnamed: D1.2 (A), J1.1
unnamed: D2.2 (A), U1.3 (+Vout)
unnamed: D3.1 (K), R5.1
unnamed: D4.1 (K), R6.1
unnamed: D5.3, R3.2
unnamed: D5.4, R4.2
unnamed: D7.1 (K), R8.1
unnamed: F1.1, J3.5
unnamed: F1.2, SW1.2
unnamed: J3.3, SW1.4
unnamed: R1.1, SW1.3, U1.2 (AC/N)
unnamed: R1.2, R3.1
unnamed: R2.1, SW1.1, U1.1 (AC/L)
unnamed: R2.2, R4.1
unnamed: R7.2, U2.1

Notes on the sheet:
To Homer PCB
Earth referencing
To DC 12V jack
Zero cross detector
PSU indication
Misc stuff
Floating side
Isolation barrier
Earthy side
To 230V AC connector
Isolation transformer secondary
Isolation transformer primary

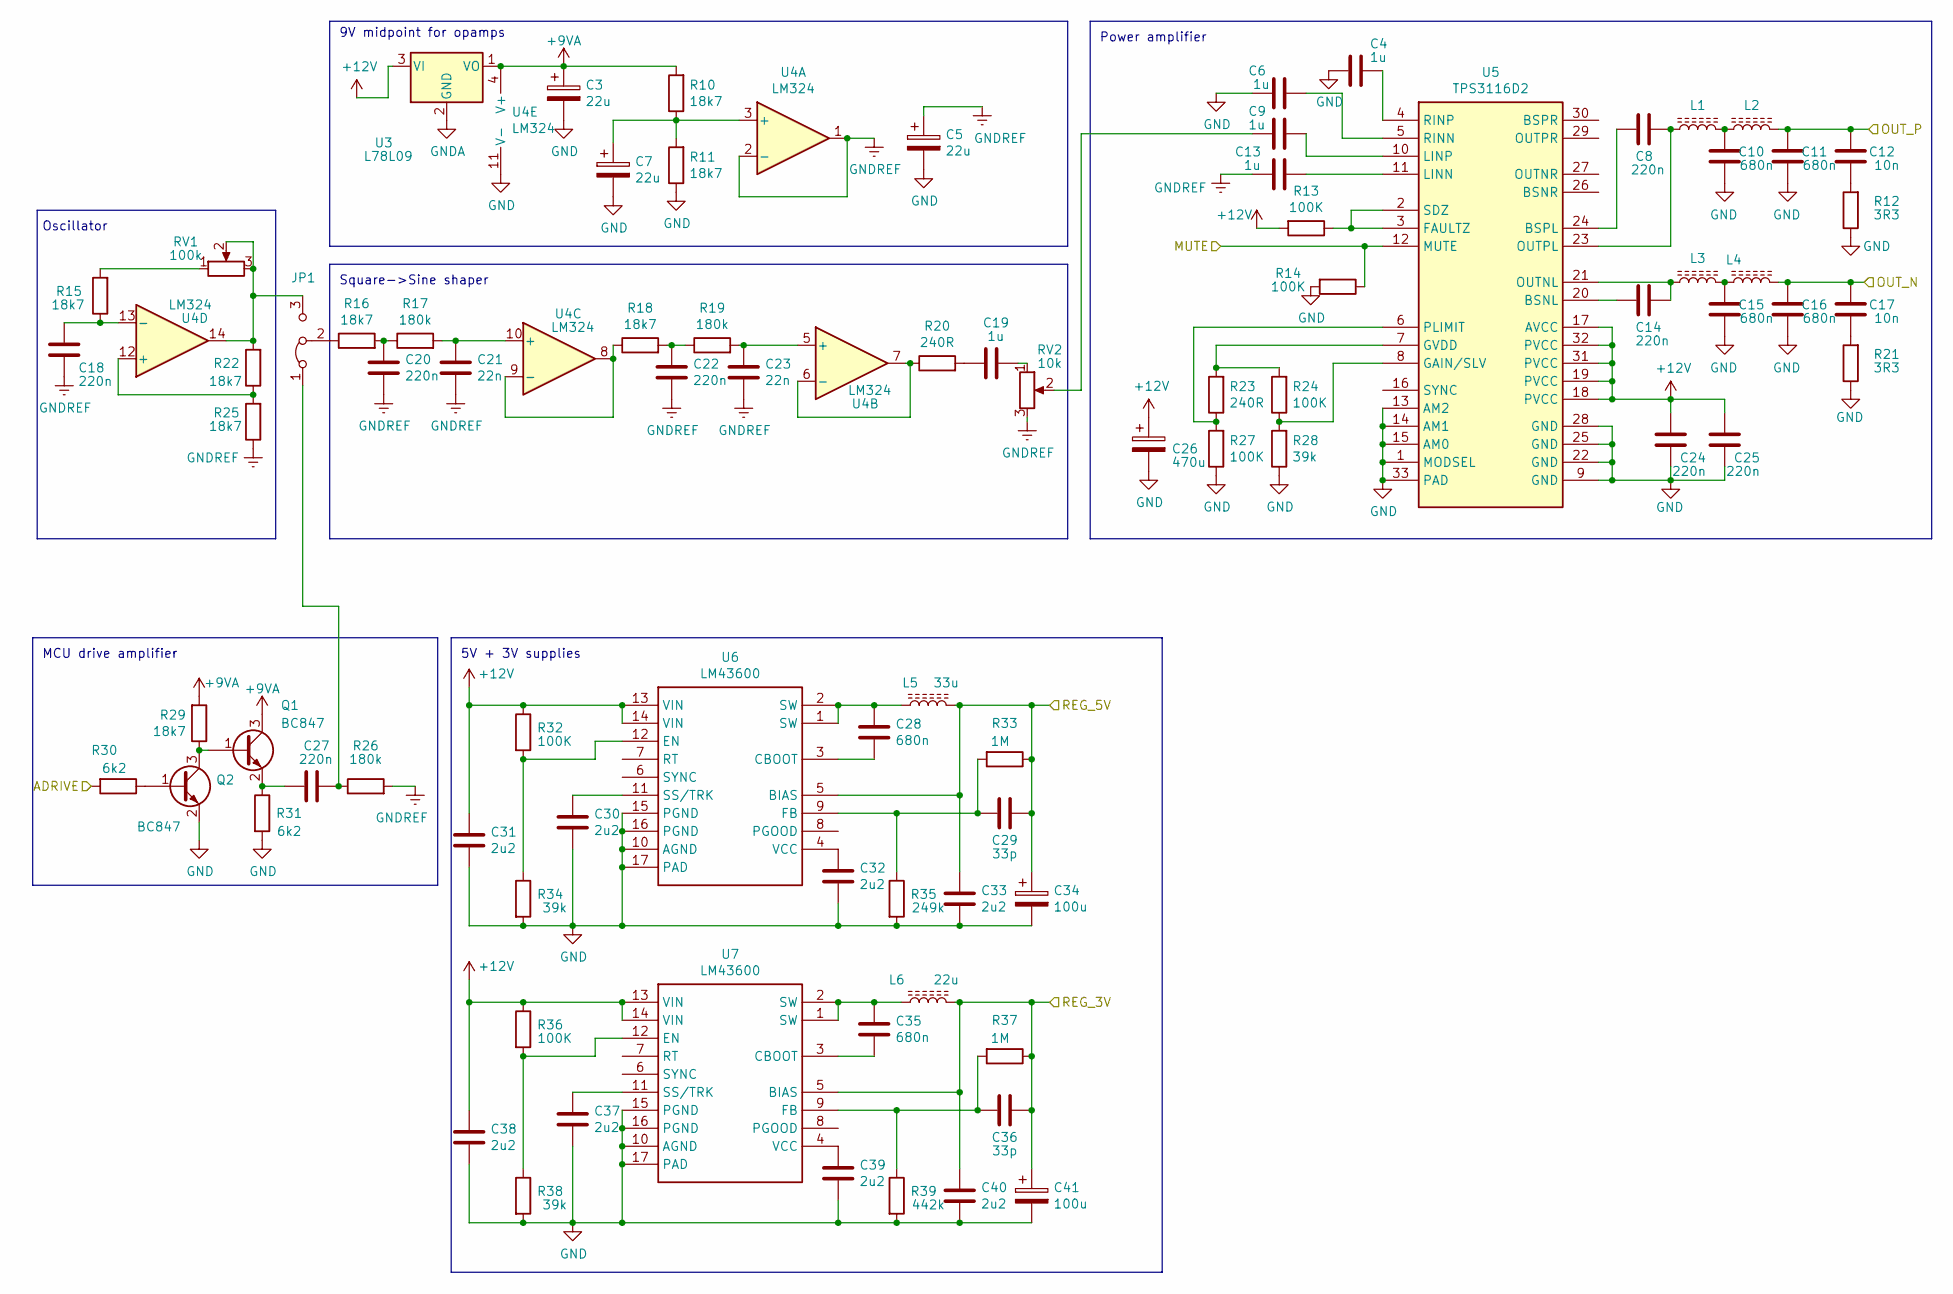
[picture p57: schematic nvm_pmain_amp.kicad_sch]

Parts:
C3, C5, C7: 22u; CP_Radial_D5.0mm_P2.50mm
C4, C6, C9, C13, C19: 1u; C_Rect_L7.0mm_W3.5mm_P5.00mm
C8, C14, C24, C25, C27: 220n; C_0805_2012Metric_Pad1.18x1.45mm_HandSolder
C10, C11, C15, C16, C28, C35: 680n; C_0805_2012Metric_Pad1.18x1.45mm_HandSolder
C12, C17: 10n; C_0805_2012Metric_Pad1.18x1.45mm_HandSolder
C18, C20, C22: 220n; C_Rect_L7.0mm_W3.5mm_P5.00mm
C21, C23: 22n; C_Rect_L7.0mm_W3.5mm_P5.00mm
C26: 470u; CP_Radial_D8.0mm_P3.50mm
C29, C36: 33p; C_0805_2012Metric_Pad1.18x1.45mm_HandSolder
C30, C31, C32, C33, C37, C38, C39, C40: 2u2; C_0805_2012Metric_Pad1.18x1.45mm_HandSolder
C34, C41: 100u; CP_EIA-7343-31_Kemet-D_Pad2.25x2.55mm_HandSolder
JP1: Jumper_3_Bridged12; PinHeader_1x03_P2.54mm_Vertical
L1, L2, L3, L4: 10u; L_10.4x10.4_H4.8
L5: 33u; L_Coilcraft_LPS5030
L6: 22u; L_Coilcraft_LPS5030
Q1, Q2: BC847; SOT-23
R10, R11, R15, R16, R18, R22, R25, R29: 18k7; R_MiniMELF_MMA-0204
R12, R21: 3R3; R_MiniMELF_MMA-0204
R13, R14, R24, R27, R32, R36: 100K; R_MiniMELF_MMA-0204
R17, R19, R26: 180k; R_MiniMELF_MMA-0204
R20, R23: 240R; R_MiniMELF_MMA-0204
R28, R34, R38: 39k; R_MiniMELF_MMA-0204
R30, R31: 6k2; R_MiniMELF_MMA-0204
R33, R37: 1M; R_MiniMELF_MMA-0204
R35: 249k; R_MiniMELF_MMA-0204
R39: 442k; R_MiniMELF_MMA-0204
RV1: 100k; Potentiometer_Bourns_3296W_Vertical
RV2: 10k; Potentiometer_Bourns_3296W_Vertical
U3: L78L09; TO-92_Wide
U4: LM324; SO-14_3.9x8.65mm_P1.27mm
U5: TPS3116D2; HTSSOP-32-1EP_6.1x11mm_P0.65mm_EP5.2x11mm_Mask4.11x4.36mm
U6, U7: LM43600; HTSSOP-16-1EP_4.4x5mm_P0.65mm_EP3.4x5mm_Mask2.46x2.31mm

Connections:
+3V3: C36.1, C40.1, C41.1, L6.2, R37.1, U7.5 (BIAS); also elsewhere on the board
+5V: C29.1, C33.1, C34.1, L5.2, R33.1, U6.5 (BIAS); also elsewhere on the board
+9VA: C3.1, Q1.3 (C), R10.2, R29.2, U3.1 (VO), U4.4 (V+)
+12V: C24.2, C25.2, C26.1, C31.1, C38.1, R13.2, R32.1, R36.1, U3.3 (VI), U5.17 (AVCC), U5.18 (PVCC), U5.19 (PVCC), U5.31 (PVCC), U5.32 (PVCC), U6.13 (VIN), U6.14 (VIN), U7.13 (VIN), U7.14 (VIN); also elsewhere on the board
/nvm_pcb_pmain_digital/MUTE: R14.1, U5.12 (MUTE); also elsewhere on the board
/nvm_pcb_pmain_digital/S_DRIV: R30.2; also elsewhere on the board
/nvm_pmain_amp/OUT_N: C16.2, C17.2, L4.2; also elsewhere on the board
/nvm_pmain_amp/OUT_P: C11.2, C12.2, L2.2; also elsewhere on the board
GND: C3.2, C4.2, C5.2, C6.2, C7.2, C10.1, C11.1, C15.1, C16.1, C24.1, C25.1, C26.2, C30.2, C31.2, C32.2, C33.2, C34.2, C37.2, C38.2, C39.2, C40.2, C41.2, Q2.2 (E), R11.1, R12.1, R14.2, R21.1, R27.1, R28.1, R31.2, R34.2, R35.2, R38.2, R39.2, U4.11 (V-), U5.1 (MODSEL), U5.9 (GND), U5.13 (AM2), U5.14 (AM1), U5.15 (AM0), U5.22 (GND), U5.25 (GND), U5.28 (GND), U5.33 (PAD), U6.10 (AGND), U6.15 (PGND), U6.16 (PGND), U6.17 (PAD), U7.10 (AGND), U7.15 (PGND), U7.16 (PGND), U7.17 (PAD); also elsewhere on the board
GNDA: U3.2 (GND)
GNDREF: C5.1, C13.2, C18.2, C20.2, C21.2, C22.2, C23.2, R25.1, R26.2, RV2.3, U4.1, U4.2 (-)
unnamed: C4.1, U5.4 (RINP)
unnamed: C6.1, U5.5 (RINN)
unnamed: C7.1, R10.1, R11.2, U4.3 (+)
unnamed: C8.1, L1.1, U5.23 (OUTPL)
unnamed: C8.2, U5.24 (BSPL)
unnamed: C9.1, U5.10 (LINP)
unnamed: C9.2, RV2.2
unnamed: C10.2, L1.2, L2.1
unnamed: C12.1, R12.2
unnamed: C13.1, U5.11 (LINN)
unnamed: C14.1, L3.1, U5.21 (OUTNL)
unnamed: C14.2, U5.20 (BSNL)
unnamed: C15.2, L3.2, L4.1
unnamed: C17.1, R21.2
unnamed: C18.1, R15.1, U4.13 (-)
unnamed: C19.1, RV2.1
unnamed: C19.2, R20.2
unnamed: C20.1, R16.2, R17.1
unnamed: C21.1, R17.2, U4.10 (+)
unnamed: C22.1, R18.2, R19.1
unnamed: C23.1, R19.2, U4.5 (+)
unnamed: C27.1, JP1.1 (A), R26.1
unnamed: C27.2, Q1.2 (E), R31.1
unnamed: C28.1, L5.1, U6.1 (SW), U6.2 (SW)
unnamed: C28.2, U6.3 (CBOOT)
unnamed: C29.2, R33.2, R35.1, U6.9 (FB)
unnamed: C30.1, U6.11 (SS/TRK)
unnamed: C32.1, U6.4 (VCC)
unnamed: C35.1, L6.1, U7.1 (SW), U7.2 (SW)
unnamed: C35.2, U7.3 (CBOOT)
unnamed: C36.2, R37.2, R39.1, U7.9 (FB)
unnamed: C37.1, U7.11 (SS/TRK)
unnamed: C39.1, U7.4 (VCC)
unnamed: JP1.2 (C), R16.1
unnamed: JP1.3 (B), R22.2, RV1.2, RV1.3, U4.14
unnamed: Q1.1 (B), Q2.3 (C), R29.1
unnamed: Q2.1 (B), R30.1
unnamed: R13.1, U5.2 (SDZ), U5.3 (FAULTZ)
unnamed: R15.2, RV1.1
unnamed: R18.1, U4.8, U4.9 (-)
unnamed: R20.1, U4.6 (-), U4.7
unnamed: R22.1, R25.2, U4.12 (+)
unnamed: R23.1, R27.2, U5.6 (PLIMIT)
unnamed: R23.2, R24.2, U5.7 (GVDD)
unnamed: R24.1, R28.2, U5.8 (GAIN/SLV)
unnamed: R32.2, R34.1, U6.12 (EN)
unnamed: R36.2, R38.1, U7.12 (EN)

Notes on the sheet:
9V midpoint for opamps
Oscillator
Square->Sine shaper
Power amplifier
5V + 3V supplies
MCU drive amplifier

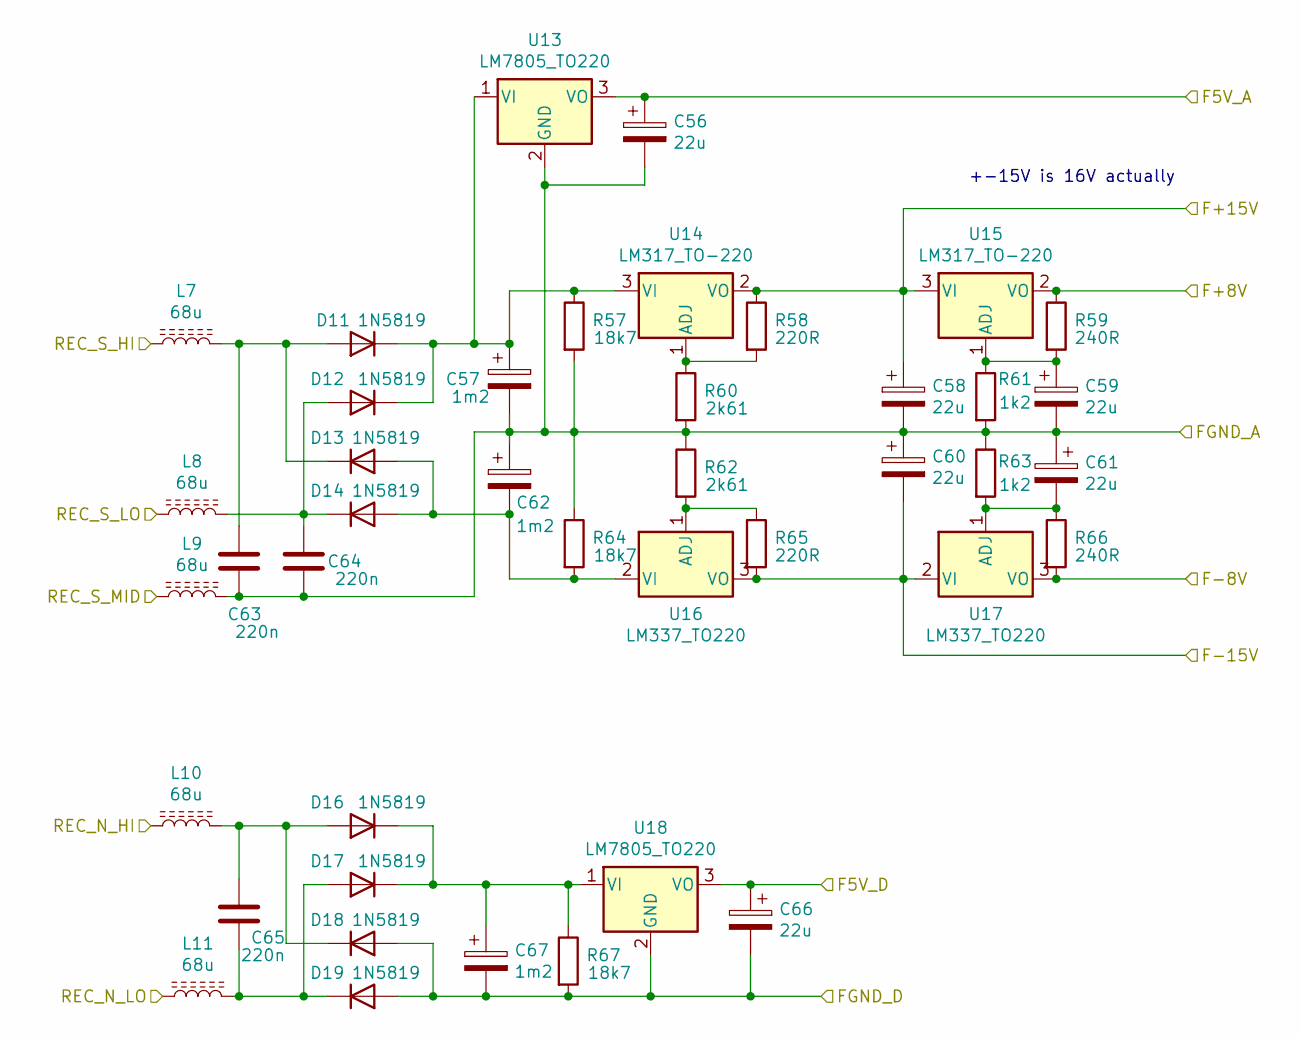
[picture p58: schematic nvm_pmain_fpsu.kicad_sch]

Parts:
C56, C58, C59, C60, C61, C66: 22u; CP_EIA-6032-28_Kemet-C_Pad2.25x2.35mm_HandSolder
C57, C62, C67: 1m2; CP_Radial_D12.5mm_P5.00mm
C63, C64, C65: 220n; C_0805_2012Metric_Pad1.18x1.45mm_HandSolder
D11, D12, D13, D14, D16, D17, D18, D19: 1N5819; D_MELF
L7, L8, L9, L10, L11: 68u; L_Bourns_SRN6045TA
R57, R64, R67: 18k7; R_MiniMELF_MMA-0204
R58, R65: 220R; R_MiniMELF_MMA-0204
R59, R66: 240R; R_MiniMELF_MMA-0204
R60, R62: 2k61; R_MiniMELF_MMA-0204
R61, R63: 1k2; R_MiniMELF_MMA-0204
U13, U18: LM7805_TO220; TO-220-3_Vertical
U14, U15: LM317_TO-220; TO-220-3_Vertical
U16, U17: LM337_TO220; TO-220-3_Vertical

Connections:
/nvm_pmain_fpsu/F5V_A: C56.1, U13.3 (VO); also elsewhere on the board
/nvm_pmain_fpsu/F5V_D: C66.1, U18.3 (VO); also elsewhere on the board
/nvm_pmain_fpsu/F+8V: R59.1, U15.2 (VO); also elsewhere on the board
/nvm_pmain_fpsu/F+15V: C58.1, R58.1, U14.2 (VO), U15.3 (VI); also elsewhere on the board
/nvm_pmain_fpsu/F-8V: R66.2, U17.3 (VO); also elsewhere on the board
/nvm_pmain_fpsu/F-15V: C60.2, R65.2, U16.3 (VO), U17.2 (VI); also elsewhere on the board
/nvm_pmain_fpsu/FGND_A: C56.2, C57.2, C58.2, C59.2, C60.1, C61.1, C62.1, C63.1, C64.1, L9.2, R57.2, R60.2, R61.2, R62.1, R63.1, R64.1, U13.2 (GND); also elsewhere on the board
/nvm_pmain_fpsu/FGND_D: C66.2, C67.2, D18.2 (A), D19.2 (A), R67.2, U18.2 (GND); also elsewhere on the board
/nvm_pmain_fpsu/REC_N_HI: L10.1; also elsewhere on the board
/nvm_pmain_fpsu/REC_N_LO: L11.1; also elsewhere on the board
/nvm_pmain_fpsu/REC_S_HI: L7.1; also elsewhere on the board
/nvm_pmain_fpsu/REC_S_LO: L8.1; also elsewhere on the board
/nvm_pmain_fpsu/REC_S_MID: L9.1; also elsewhere on the board
unnamed: C57.1, D11.1 (K), D12.1 (K), R57.1, U13.1 (VI), U14.3 (VI)
unnamed: C59.1, R59.2, R61.1, U15.1 (ADJ)
unnamed: C61.2, R63.2, R66.1, U17.1 (ADJ)
unnamed: C62.2, D13.2 (A), D14.2 (A), R64.2, U16.2 (VI)
unnamed: C63.2, D11.2 (A), D13.1 (K), L7.2
unnamed: C64.2, D12.2 (A), D14.1 (K), L8.2
unnamed: C65.1, D17.2 (A), D19.1 (K), L11.2
unnamed: C65.2, D16.2 (A), D18.1 (K), L10.2
unnamed: C67.1, D16.1 (K), D17.1 (K), R67.1, U18.1 (VI)
unnamed: R58.2, R60.1, U14.1 (ADJ)
unnamed: R62.2, R65.1, U16.1 (ADJ)

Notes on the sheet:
+-15V is 16V actually

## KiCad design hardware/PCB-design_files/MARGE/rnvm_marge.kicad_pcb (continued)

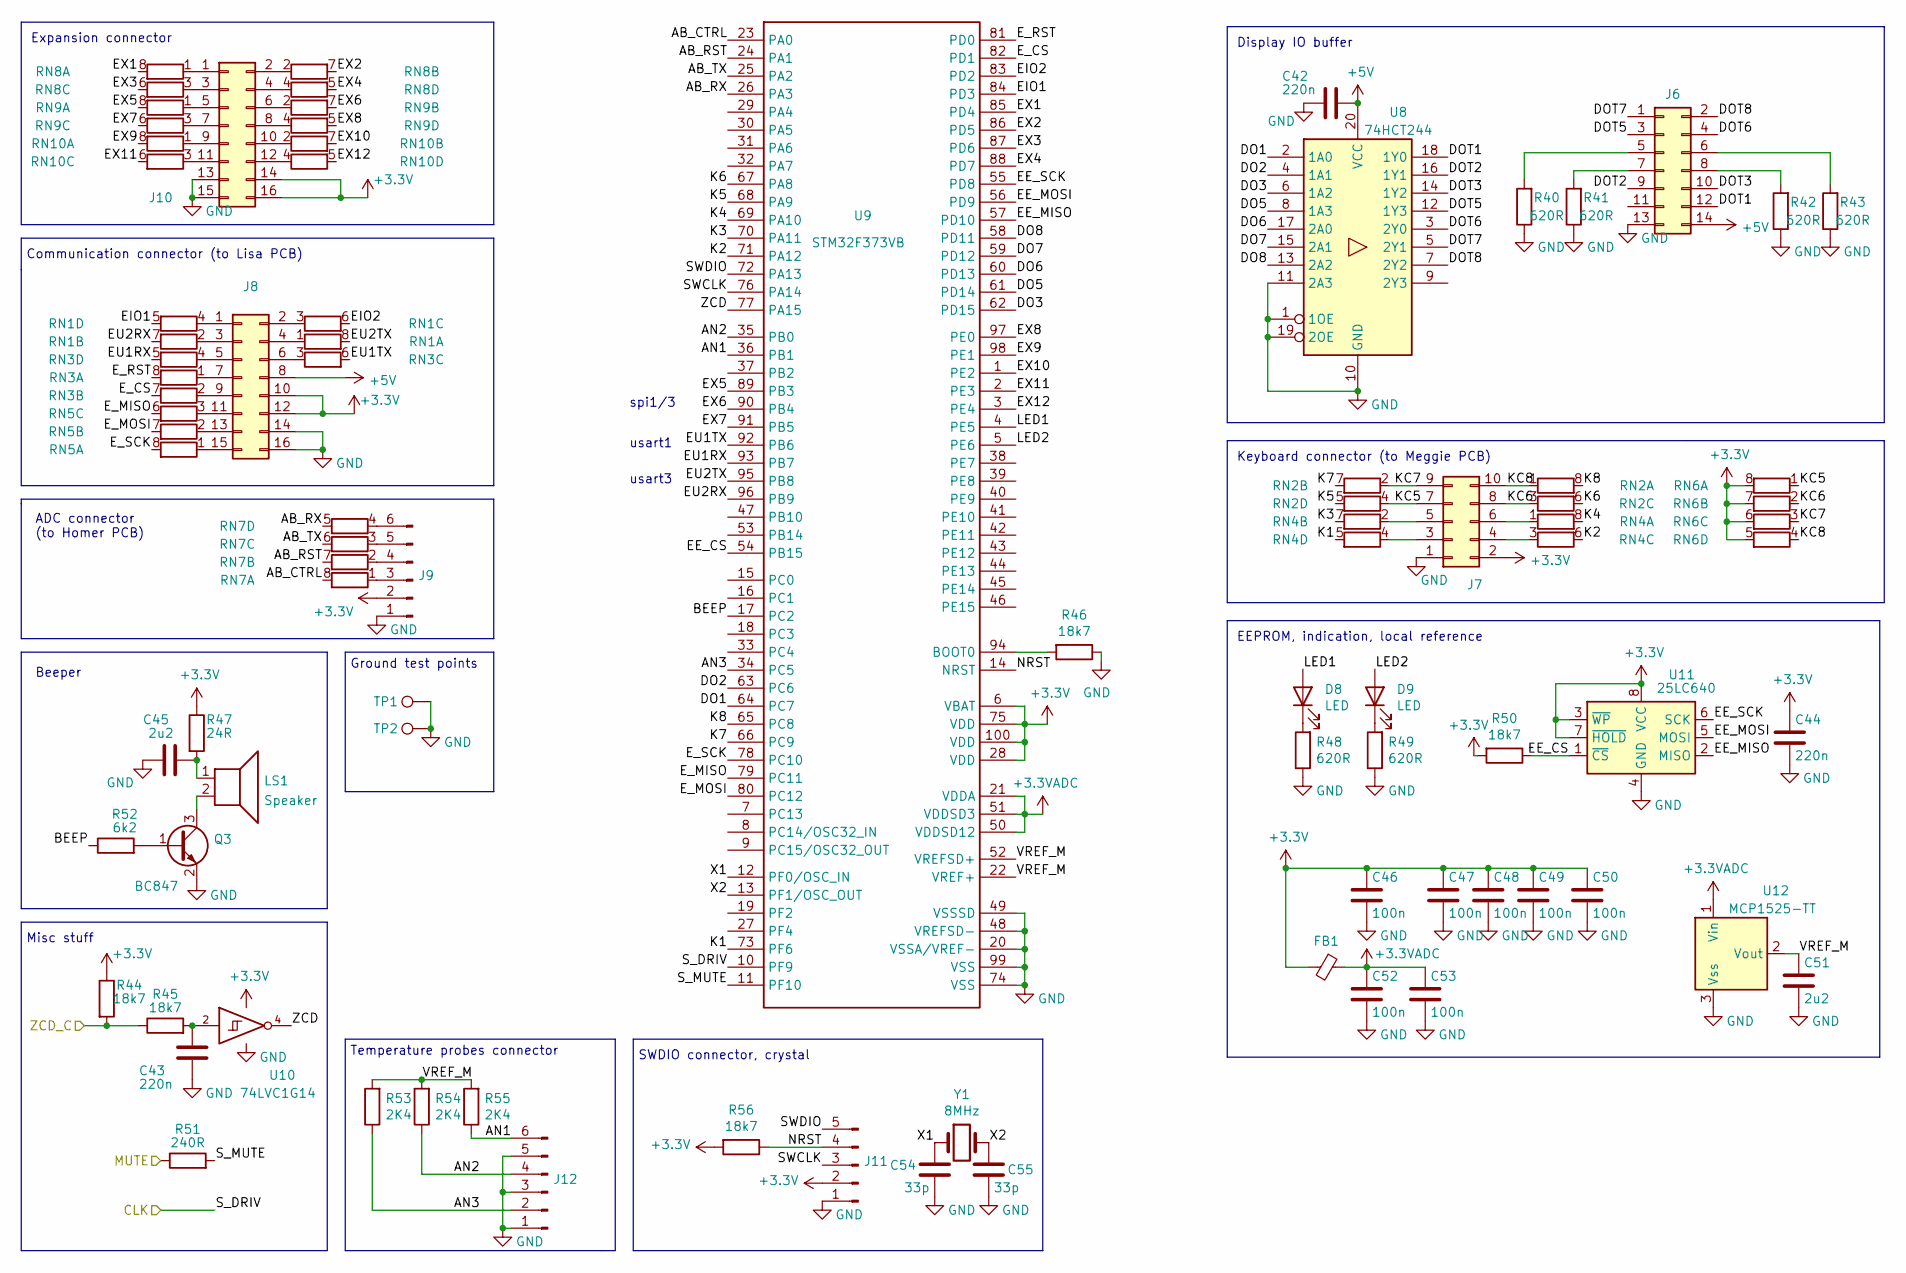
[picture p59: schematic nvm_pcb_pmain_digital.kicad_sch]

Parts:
C42, C43, C44: 220n; C_0805_2012Metric_Pad1.18x1.45mm_HandSolder
C45, C51: 2u2; C_0805_2012Metric_Pad1.18x1.45mm_HandSolder
C46, C47, C48, C49, C50, C52, C53: 100n; C_0603_1608Metric_Pad1.08x0.95mm_HandSolder
C54, C55: 33p; C_0805_2012Metric_Pad1.18x1.45mm_HandSolder
D8, D9: LED; LED_0805_2012Metric_Pad1.15x1.40mm_HandSolder
FB1: Ferrite_Bead_Small; L_0805_2012Metric_Pad1.05x1.20mm_HandSolder
J6: Conn_02x07_Odd_Even; IDC-Header_2x07_P2.54mm_Vertical
J7: Conn_02x05_Odd_Even; IDC-Header_2x05_P2.54mm_Vertical
J8: Conn_02x08_Odd_Even; IDC-Header_2x08_P2.54mm_Vertical
J9: Conn_01x06_Male; Molex_KK-254_AE-6410-06A_1x06_P2.54mm_Vertical
J10: Conn_02x08_Odd_Even; PinHeader_2x08_P2.54mm_Vertical
J11: Conn_01x05_Male; PinHeader_1x05_P2.54mm_Vertical
J12: Conn_01x06_Male; PinHeader_1x06_P2.54mm_Vertical
LS1: Speaker; beeper12
Q3: BC847; SOT-23
R40, R41, R42, R43, R48, R49: 620R; R_MiniMELF_MMA-0204
R44, R45, R46, R50, R56: 18k7; R_MiniMELF_MMA-0204
R47: 24R; R_MiniMELF_MMA-0204
R51: 240R; R_MiniMELF_MMA-0204
R52: 6k2; R_MiniMELF_MMA-0204
R53, R54, R55: 2K4; R_MiniMELF_MMA-0204
RN1, RN2, RN3, RN4, RN5, RN7, RN8, RN9, RN10: 51R; R_Array_Convex_4x1206
RN6: 20k; R_Array_Convex_4x1206
TP1, TP2: TestPoint; TestPoint_Loop_D3.50mm_Drill1.4mm_Beaded
U8: 74HCT244; SOIC-20W_7.5x12.8mm_P1.27mm
U9: STM32F373VB; TQFP-100_14x14mm_P0.5mm
U10: 74LVC1G14; SOT-23-5_HandSoldering
U11: 25LC640; SOIC-8_3.9x4.9mm_P1.27mm
U12: MCP1525-TT; SOT-23
Y1: 8MHz; Crystal_SMD_HC49-SD

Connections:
+3.3VADC: C52.1, C53.1, FB1.1, U9.21 (VDDA), U9.50 (VDDSD12), U9.51 (VDDSD3), U12.1 (Vin)
+3V3: C44.1, C46.1, C47.1, C48.1, C49.1, C50.1, FB1.2, J7.2, J8.10, J8.12, J9.2, J10.14, J10.16, J11.2, R44.1, R47.1, R50.2, R56.2, RN6.5 (R4.2), RN6.6 (R3.2), RN6.7 (R2.2), RN6.8 (R1.2), U9.6 (VBAT), U9.28 (VDD), U9.75 (VDD), U9.100 (VDD), U10.5 (VCC), U11.3 (~WP), U11.7 (~HOLD), U11.8 (VCC); also elsewhere on the board
+5V: C42.1, J6.14, J8.8, U8.20 (VCC); also elsewhere on the board
/nvm_pcb_pmain_digital/AB_CTRL: RN7.8 (R1.2), U9.23 (PA0)
/nvm_pcb_pmain_digital/AB_RST: RN7.7 (R2.2), U9.24 (PA1)
/nvm_pcb_pmain_digital/AB_RX: RN7.5 (R4.2), U9.26 (PA3)
/nvm_pcb_pmain_digital/AB_TX: RN7.6 (R3.2), U9.25 (PA2)
/nvm_pcb_pmain_digital/AN1: J12.6, R55.1, U9.36 (PB1)
/nvm_pcb_pmain_digital/AN2: J12.4, R54.1, U9.35 (PB0)
/nvm_pcb_pmain_digital/AN3: J12.2, R53.1, U9.34 (PC5)
/nvm_pcb_pmain_digital/BEEP: R52.1, U9.17 (PC2)
/nvm_pcb_pmain_digital/DO1: U8.2 (1A0), U9.64 (PC7)
/nvm_pcb_pmain_digital/DO2: U8.4 (1A1), U9.63 (PC6)
/nvm_pcb_pmain_digital/DO3: U8.6 (1A2), U9.62 (PD15)
/nvm_pcb_pmain_digital/DO5: U8.8 (1A3), U9.61 (PD14)
/nvm_pcb_pmain_digital/DO6: U8.17 (2A0), U9.60 (PD13)
/nvm_pcb_pmain_digital/DO7: U8.15 (2A1), U9.59 (PD12)
/nvm_pcb_pmain_digital/DO8: U8.13 (2A2), U9.58 (PD11)
/nvm_pcb_pmain_digital/DOT1: J6.12, U8.18 (1Y0)
/nvm_pcb_pmain_digital/DOT2: J6.9, U8.16 (1Y1)
/nvm_pcb_pmain_digital/DOT3: J6.10, U8.14 (1Y2)
/nvm_pcb_pmain_digital/DOT5: J6.3, U8.12 (1Y3)
/nvm_pcb_pmain_digital/DOT6: J6.4, U8.3 (2Y0)
/nvm_pcb_pmain_digital/DOT7: J6.1, U8.5 (2Y1)
/nvm_pcb_pmain_digital/DOT8: J6.2, U8.7 (2Y2)
/nvm_pcb_pmain_digital/EE_CS: R50.1, U9.54 (PB15), U11.1 (~CS)
/nvm_pcb_pmain_digital/EE_MISO: U9.57 (PD10), U11.2 (MISO)
/nvm_pcb_pmain_digital/EE_MOSI: U9.56 (PD9), U11.5 (MOSI)
/nvm_pcb_pmain_digital/EE_SCK: U9.55 (PD8), U11.6 (SCK)
/nvm_pcb_pmain_digital/EIO1: RN1.5 (R4.2), U9.84 (PD3)
/nvm_pcb_pmain_digital/EIO2: RN1.6 (R3.2), U9.83 (PD2)
/nvm_pcb_pmain_digital/EU1RX: RN3.5 (R4.2), U9.93 (PB7)
/nvm_pcb_pmain_digital/EU1TX: RN3.6 (R3.2), U9.92 (PB6)
/nvm_pcb_pmain_digital/EU2RX: RN1.7 (R2.2), U9.96 (PB9)
/nvm_pcb_pmain_digital/EU2TX: RN1.8 (R1.2), U9.95 (PB8)
/nvm_pcb_pmain_digital/EX1: RN8.8 (R1.2), U9.85 (PD4)
/nvm_pcb_pmain_digital/EX2: RN8.7 (R2.2), U9.86 (PD5)
/nvm_pcb_pmain_digital/EX3: RN8.6 (R3.2), U9.87 (PD6)
/nvm_pcb_pmain_digital/EX4: RN8.5 (R4.2), U9.88 (PD7)
/nvm_pcb_pmain_digital/EX5: RN9.8 (R1.2), U9.89 (PB3)
/nvm_pcb_pmain_digital/EX6: RN9.7 (R2.2), U9.90 (PB4)
/nvm_pcb_pmain_digital/EX7: RN9.6 (R3.2), U9.91 (PB5)
/nvm_pcb_pmain_digital/EX8: RN9.5 (R4.2), U9.97 (PE0)
/nvm_pcb_pmain_digital/EX9: RN10.8 (R1.2), U9.98 (PE1)
/nvm_pcb_pmain_digital/EX10: RN10.7 (R2.2), U9.1 (PE2)
/nvm_pcb_pmain_digital/EX11: RN10.6 (R3.2), U9.2 (PE3)
/nvm_pcb_pmain_digital/EX12: RN10.5 (R4.2), U9.3 (PE4)
/nvm_pcb_pmain_digital/E_CS: RN3.7 (R2.2), U9.82 (PD1)
/nvm_pcb_pmain_digital/E_MISO: RN5.6 (R3.2), U9.79 (PC11)
/nvm_pcb_pmain_digital/E_MOSI: RN5.7 (R2.2), U9.80 (PC12)
/nvm_pcb_pmain_digital/E_RST: RN3.8 (R1.2), U9.81 (PD0)
/nvm_pcb_pmain_digital/E_SCK: RN5.8 (R1.2), U9.78 (PC10)
/nvm_pcb_pmain_digital/K1: RN4.5 (R4.2), U9.73 (PF6)
/nvm_pcb_pmain_digital/K2: RN4.6 (R3.2), U9.71 (PA12)
/nvm_pcb_pmain_digital/K3: RN4.7 (R2.2), U9.70 (PA11)
/nvm_pcb_pmain_digital/K4: RN4.8 (R1.2), U9.69 (PA10)
/nvm_pcb_pmain_digital/K5: RN2.5 (R4.2), U9.68 (PA9)
/nvm_pcb_pmain_digital/K6: RN2.6 (R3.2), U9.67 (PA8)
/nvm_pcb_pmain_digital/K7: RN2.7 (R2.2), U9.66 (PC9)
/nvm_pcb_pmain_digital/K8: RN2.8 (R1.2), U9.65 (PC8)
/nvm_pcb_pmain_digital/KC5: J7.7, RN2.4 (R4.1), RN6.1 (R1.1)
/nvm_pcb_pmain_digital/KC6: J7.8, RN2.3 (R3.1), RN6.2 (R2.1)
/nvm_pcb_pmain_digital/KC7: J7.9, RN2.2 (R2.1), RN6.3 (R3.1)
/nvm_pcb_pmain_digital/KC8: J7.10, RN2.1 (R1.1), RN6.4 (R4.1)
/nvm_pcb_pmain_digital/LED1: D8.2 (A), U9.4 (PE5)
/nvm_pcb_pmain_digital/LED2: D9.2 (A), U9.5 (PE6)
/nvm_pcb_pmain_digital/MUTE: R51.1; also elsewhere on the board
/nvm_pcb_pmain_digital/NRST: J11.4, R56.1, U9.14 (NRST)
/nvm_pcb_pmain_digital/SWCLK: J11.3, U9.76 (PA14)
/nvm_pcb_pmain_digital/SWDIO: J11.5, U9.72 (PA13)
/nvm_pcb_pmain_digital/S_DRIV: U9.10 (PF9); also elsewhere on the board
/nvm_pcb_pmain_digital/S_MUTE: R51.2, U9.11 (PF10)
/nvm_pcb_pmain_digital/VREF_M: C51.1, R53.2, R54.2, R55.2, U9.22 (VREF+), U9.52 (VREFSD+), U12.2 (Vout)
/nvm_pcb_pmain_digital/X1: C54.1, U9.12 (PF0/OSC_IN), Y1.1
/nvm_pcb_pmain_digital/X2: C55.1, U9.13 (PF1/OSC_OUT), Y1.2
/nvm_pcb_pmain_digital/ZCD: U9.77 (PA15), U10.4
/nvm_pcb_pmain_digital/ZCD_C: R44.2, R45.1; also elsewhere on the board
GND: C42.2, C43.2, C44.2, C45.1, C46.2, C47.2, C48.2, C49.2, C50.2, C51.2, C52.2, C53.2, C54.2, C55.2, J6.13, J7.1, J8.14, J8.16, J9.1, J10.13, J10.15, J11.1, J12.1, J12.3, J12.5, Q3.2 (E), R40.1, R41.1, R42.1, R43.1, R46.1, R48.1, R49.1, TP1.1, TP2.1, U8.1 (1OE), U8.10 (GND), U8.11 (2A3), U8.19 (2OE), U9.20 (VSSA/VREF-), U9.48 (VREFSD-), U9.49 (VSSSD), U9.74 (VSS), U9.99 (VSS), U10.3 (GND), U11.4 (GND), U12.3 (Vss); also elsewhere on the board
unnamed: C43.1, R45.2, U10.2
unnamed: C45.2, LS1.1, R47.2
unnamed: D8.1 (K), R48.2
unnamed: D9.1 (K), R49.2
unnamed: J6.5, R40.2
unnamed: J6.6, R43.2
unnamed: J6.7, R41.2
unnamed: J6.8, R42.2
unnamed: J7.3, RN4.4 (R4.1)
unnamed: J7.4, RN4.3 (R3.1)
unnamed: J7.5, RN4.2 (R2.1)
unnamed: J7.6, RN4.1 (R1.1)
unnamed: J8.1, RN1.4 (R4.1)
unnamed: J8.2, RN1.3 (R3.1)
unnamed: J8.3, RN1.2 (R2.1)
unnamed: J8.4, RN1.1 (R1.1)
unnamed: J8.5, RN3.4 (R4.1)
unnamed: J8.6, RN3.3 (R3.1)
unnamed: J8.7, RN3.1 (R1.1)
unnamed: J8.9, RN3.2 (R2.1)
unnamed: J8.11, RN5.3 (R3.1)
unnamed: J8.13, RN5.2 (R2.1)
unnamed: J8.15, RN5.1 (R1.1)
unnamed: J9.3, RN7.1 (R1.1)
unnamed: J9.4, RN7.2 (R2.1)
unnamed: J9.5, RN7.3 (R3.1)
unnamed: J9.6, RN7.4 (R4.1)
unnamed: J10.1, RN8.1 (R1.1)
unnamed: J10.2, RN8.2 (R2.1)
unnamed: J10.3, RN8.3 (R3.1)
unnamed: J10.4, RN8.4 (R4.1)
unnamed: J10.5, RN9.1 (R1.1)
unnamed: J10.6, RN9.2 (R2.1)
unnamed: J10.7, RN9.3 (R3.1)
unnamed: J10.8, RN9.4 (R4.1)
unnamed: J10.9, RN10.1 (R1.1)
unnamed: J10.10, RN10.2 (R2.1)
unnamed: J10.11, RN10.3 (R3.1)
unnamed: J10.12, RN10.4 (R4.1)
unnamed: LS1.2, Q3.3 (C)
unnamed: Q3.1 (B), R52.2
unnamed: R46.2, U9.94 (BOOT0)

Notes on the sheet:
Beeper
Expansion connector
Temperature probes connector
SWDIO connector, crystal
Communication connector (to Lisa PCB)
Ground test points
ADC connector (to Homer PCB)
Keyboard connector (to Meggie PCB)
spi1/3
usart3
Display IO buffer
usart1
EEPROM, indication, local reference
Misc stuff

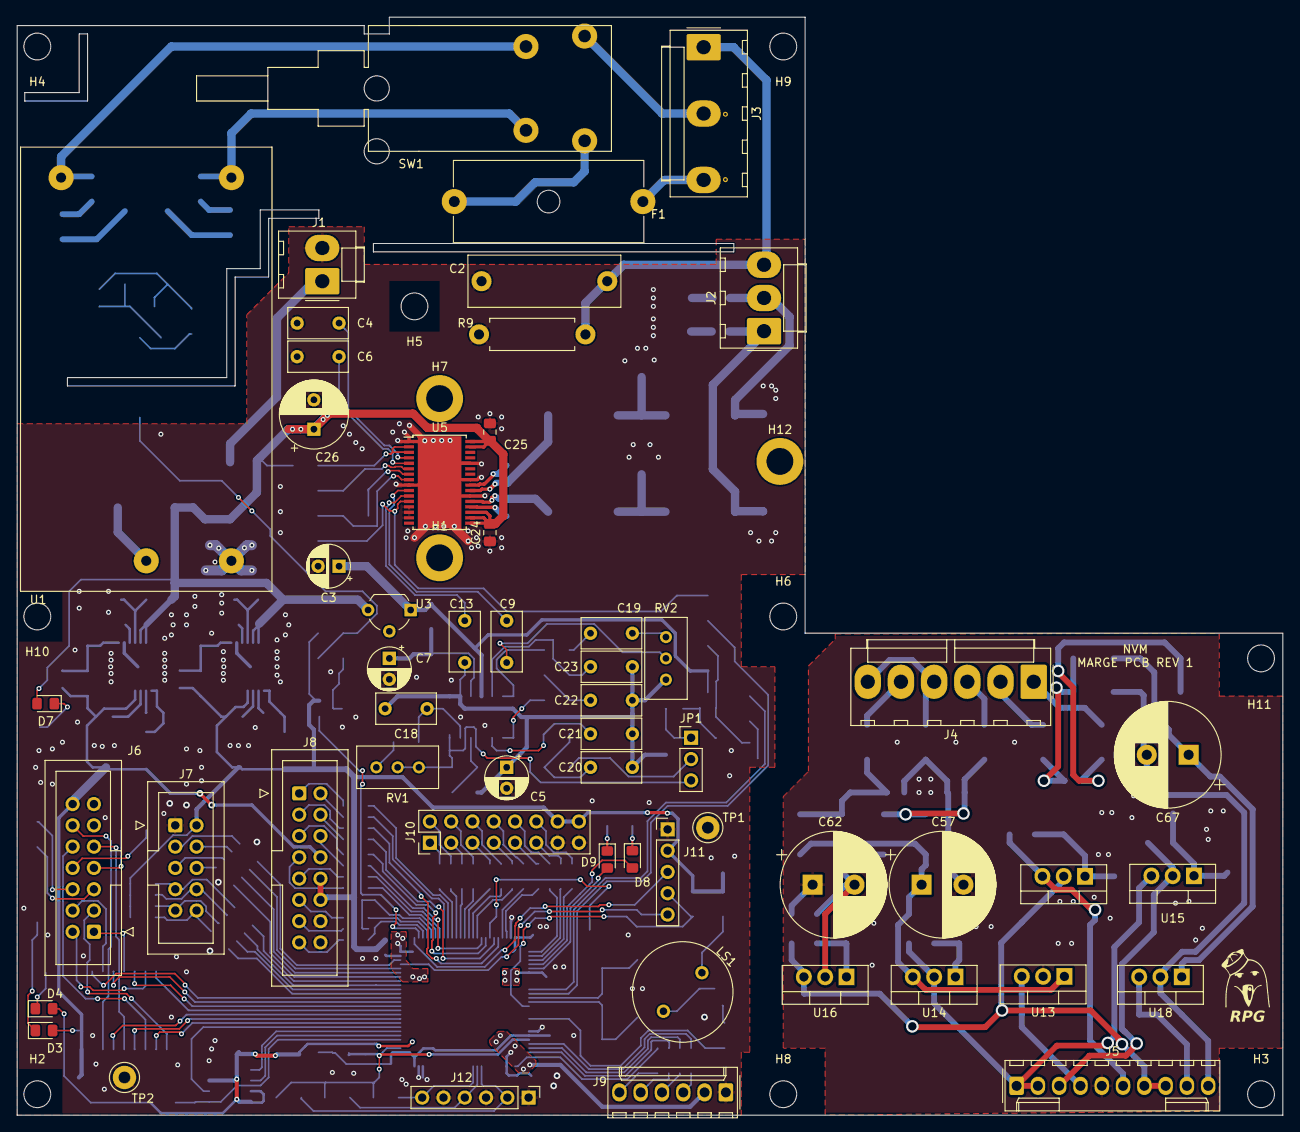
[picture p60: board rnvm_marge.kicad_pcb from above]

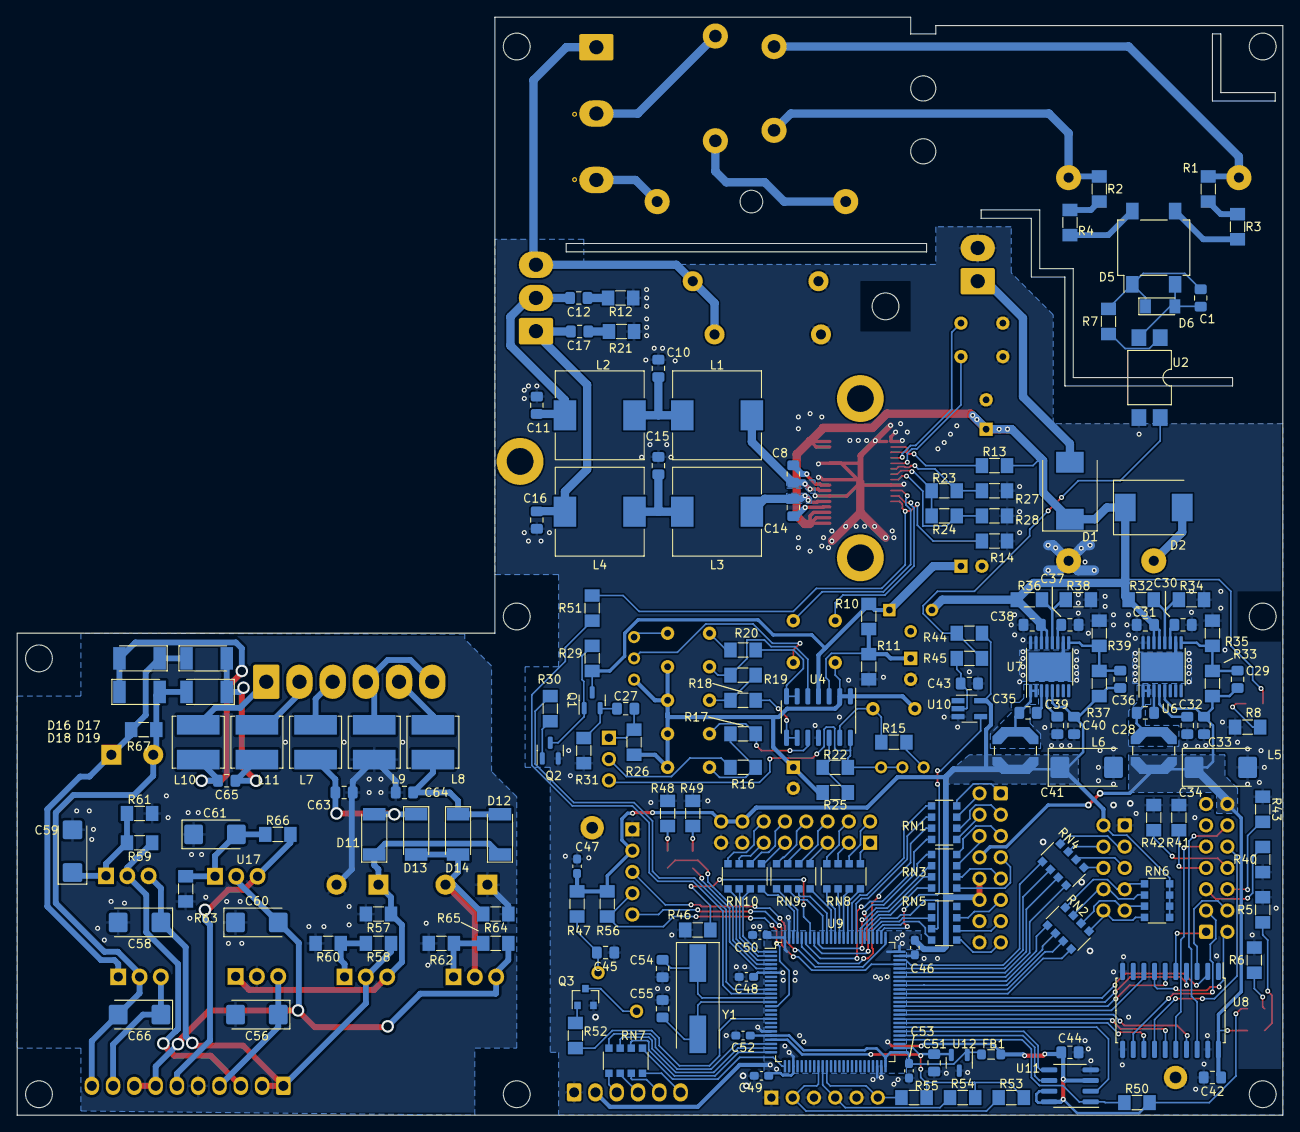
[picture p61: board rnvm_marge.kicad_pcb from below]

Board: 2 copper layers, 151.0 x 131.0 mm, 228 parts (160 on the bottom side), 214 nets.

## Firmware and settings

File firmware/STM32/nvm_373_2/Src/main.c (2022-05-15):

#include <stdio.h>
#include <stdlib.h>
#include <string.h>
#include "stm32f373xc.h"
#include "globals.h"
#include "socket.h"
#include "wizchip_conf.h"
#include "loopback.h"
#include "telnet.h"
#include "dhcp.h"
#include "hw.h"
#include "scpi.h"
#include "acal.h"

char lcd_str[50],disp_msg[30],scpi_response[50],volt_reading[20],tx_str[60];
uint8_t pwm_div=0, pwm_cnt=0;
uint8_t vol_hist_ptr=0;
uint8_t f_vol_newval,adc_update_stat,f_disp_update;
uint8_t f_input_changed,f_eesave_sets,f_eesave_cal1,f_eth_avilable,f_cal_unlocked=0;
uint8_t uzero_enabled[RANGE_MAX+1];
uint8_t range,f_range_updated,main_state;
int16_t nd;
uint16_t tick_main, tick_kbd,tick_adcu,tick_eth,tick_psu;
float voltage,voltage_avg,voltage_zero,voltage_raw,voltage_corr;
float voltage_uzero[RANGE_MAX+1],voltage_display,vol_hist[70];
volatile uint8_t rx_msg[10],rx_msg_ptr,rx_flag,adc_data[6];

key_var keys,keys_new,keys_old;
settings_var settings;
calibration_var calibration_act;
scpi_t scpi_context;
adc_cfg_var adc_cfg;

static char scpi_input_buffer[SCPI_INPUT_BUFFER_LENGTH];
scpi_error_t scpi_error_queue_data[SCPI_ERROR_QUEUE_SIZE];

int16_t menu_items_val[MENU_ITEMS] = {0,0,0,0,0};
const char menu_items_text[MENU_ITEMS][DISPLAY_LEN] =
		{"AUTOZERO ON  ","DIGITS   ","AC SYNC SAMPLING  ","BEEP ON   ","GPIB ADDRESS   "};
const int16_t menu_items_limit_max[MENU_ITEMS] = {1,6,1,1,31};
const int16_t menu_items_limit_min[MENU_ITEMS] = {0,3,0,0,0};
const char nplc_settings[5] = {1,2,5,10,20};
uint8_t gDATABUF_DHCP[DATA_BUF_SIZE_DHCP],my_dhcp_retry = 0,run_user_applications = 0;
uint8_t ethBuf0[ETH_MAX_BUF_SIZE],ethBuf1[ETH_MAX_BUF_SIZE];
uint8_t ethBut3_TELNET[TELNET_BUF_SIZE],ethBut4_TELNET[TELNET_BUF_SIZE];
wiz_NetInfo netInfo = { .mac  = {0x00, 0x08, 0xdc, 0xab, 0xcd, 0xef}, // Mac address
		.ip   = {192, 168, 0, 199},         // IP address
		.sn   = {255, 255, 255, 0},         // Subnet mask
		.dns =  {8,8,8,8},			  // DNS address (google dns)
		.gw   = {192, 168, 0, 1}, // Gateway address
		.dhcp = NETINFO_DHCP};    //Static IP configuration
wiz_NetInfo netInfo_r;

void check_network_information (void)
	{
	wizchip_getnetinfo(&netInfo_r);
	if(wizphy_getphylink() == PHY_LINK_ON) f_eth_avilable = 1;
	else f_eth_avilable = 0;
	}

void telnet_call (char * str_in, char * str_out)
{
	if (SCPI_Input(&scpi_context, str_in, strlen(str_in))==TRUE)
		{
		}
}

/*******************************************************
 * @ brief Call back for ip assing & ip update from DHCP
 *******************************************************/
void my_ip_assign(void)
{
   getIPfromDHCP(netInfo.ip);
   getGWfromDHCP(netInfo.gw);
   getSNfromDHCP(netInfo.sn);
   getDNSfromDHCP(netInfo.dns);
   netInfo.dhcp = NETINFO_DHCP;
   /* Network initialization */
   //Net_Conf();      // apply from DHCP
	wizchip_setnetinfo(&netInfo);// apply from DHCP
//#ifdef _MAIN_DEBUG_
//   Display_Net_Conf();
//	print_network_information();
#if 0
   PRINTF("DHCP LEASED TIME : %ld Sec.\r\n", getDHCPLeasetime());
   PRINTF("\r\n");
#endif
}

void my_ip_conflict(void)
{
}


void TIM6_DAC1_IRQHandler(void)
    {
    TIM6->SR=0;
    TIM6->CR1=0x0000;
    NVIC_DisableIRQ(TIM6_DAC1_IRQn);
    if (rx_msg_ptr==6)
		{
		rx_flag=1;
		adc_data[0]=rx_msg[0];
		adc_data[1]=rx_msg[1];
		adc_data[2]=rx_msg[2];
		adc_data[3]=rx_msg[3];
		adc_data[4]=rx_msg[4];
		adc_data[5]=rx_msg[5];
		}
    rx_msg_ptr=0;
    }

void USART2_IRQHandler(void)
    {
    uint8_t b;
    b = USART2->RDR;
    rx_msg[rx_msg_ptr++] = b;
    if (rx_msg_ptr>9) rx_msg_ptr = 9;
    TIM6->CR1=0x0000;
    TIM6->SR=0;
    TIM6->CNT=0x0000;
    TIM6->PSC=0x0000;
    TIM6->ARR=1600;
    TIM6->DIER=0x0001;
    TIM6->CR1=0x0001;
    NVIC_EnableIRQ(TIM6_DAC1_IRQn);
    }

void USART3_IRQHandler(void)
    {
    uint8_t b;
    b = USART3->RDR;
    }


void send_adc_config (uint32_t config_word)
	{
	LO(GPIOA, 1);
	delay_ms(1);
	uart2_send_byte((config_word>>0)&0xFF);
	delay_ms(1);
	uart2_send_byte((config_word>>8)&0xFF);
	delay_ms(1);
	uart2_send_byte((config_word>>16)&0xFF);
	delay_ms(1);
	uart2_send_byte((config_word>>24)&0xFF);
	delay_ms(1);
	HI(GPIOA, 1);
	}



void eeprom_task (void)
	{
	if (f_eesave_sets)
		{
		f_eesave_sets = 0;
		settings_save(EE_ADDR_SETS,&settings);
		}
	}

void keyboard_task (void)
	{
	if ((uint16_t)(get_tick()-tick_kbd)>INT_KBD)
		{
		tick_kbd = get_tick();
		keys_new.INT16 = kbd_get_keys();
		if (((keys_new.INT16^keys_old.INT16)&keys_new.INT16)&&(settings.beep)) buzzer_start(9, 10);
    	keys.INT16 = keys.INT16 | ((keys_new.INT16^keys_old.INT16)&keys_new.INT16);
    	keys_old.INT16 =keys_new.INT16;
		}
	}

void adc_task (void)
	{
	int16_t adc_cvmul;
	int32_t adcres,adcres_a,adcres_b;
	adc_cvmul = calibration_act.adc_scale;
	uint16_t n1,n2,n3,az,i;
	static uint16_t np;
	if (rx_flag==1)
		{
		rx_flag=0;
		if (adc_data[4]&0x80) az = 1;
		else az = 0;
		adc_data[4] = adc_data[4]&0x7F;
		n1 = (((uint16_t)(adc_data[0]))<<8)+(((uint16_t)(adc_data[1]))<<0);
		n2 = (((uint16_t)(adc_data[2]))<<8)+(((uint16_t)(adc_data[3]))<<0);
		n3 = (((uint16_t)(adc_data[4]))<<8)+(((uint16_t)(adc_data[5]))<<0);
		n3 = n3>>1;
		nd = n3-np;
		np = n3;
		adcres_a = (((int32_t)(n1))*((int32_t)(adc_cvmul)));
		adcres_b = (((int32_t)(n2))*((int32_t)(-adc_cvmul)));
		adcres = nd-(adcres_a + adcres_b);
		voltage_raw = ((float)(adcres))/(1991580.0/10.0);
		voltage_raw = voltage_raw / ((float)(nplc_settings[settings.nplc])/2.0);
//		sprintf(tx_str,"%u %u %u %d %d %f\n",n1,n2,n3,nd,az,voltage_raw);
//		uart3_send_str(tx_str);
		if (az==1) voltage_zero = voltage_raw;
		else
			{
			voltage = voltage_raw - voltage_zero;
//			voltage = voltage/(1990635.0/10.0);
//			voltage = voltage / ((float)(nplc_settings[settings.nplc])/2.0);
			}
		if (az==0)
			{
			if (settings.filter_digital>1)
				{
				vol_hist[vol_hist_ptr++] = voltage;
				if (vol_hist_ptr>=settings.filter_digital)
					vol_hist_ptr=0;
				voltage = 0;
				for (i=0;i<settings.filter_digital;i++) voltage = voltage + vol_hist[i];
				voltage = voltage / ((float)(settings.filter_digital));
				}
			voltage_corr = (voltage + calibration_act.ranges[range].range_zero_corr) / calibration_act.ranges[range].range_gain_corr;
			f_vol_newval = 1;
			}
		}
	if (adc_update_stat==1)
		{
		send_adc_config(adc_cfg.INT32);
		if ((adc_cfg.re1a)|(adc_cfg.re1b)|(adc_cfg.re2a)|(adc_cfg.re2b))
			{
			tick_adcu = get_tick();
			adc_update_stat=2;
			}
		else
			{
			adc_update_stat=0;
			}
		}
	if (adc_update_stat==2)
		{
		if ((uint16_t)(get_tick()-tick_adcu)>INT_ADC_DU)
			{
			adc_cfg.re1a=0;
			adc_cfg.re2a=0;
			adc_cfg.re1b=0;
			adc_cfg.re2b=0;
			send_adc_config(adc_cfg.INT32);
			adc_update_stat=0;
			}
		}
	}
void psu_task (void)
	{
	if ((uint16_t)(get_tick()-tick_psu)>INT_PSU)
		{
		tick_psu = get_tick();
		pwm_set(pwm_div);
		if (pwm_div<66) pwm_div++;
		}

	}

void main_state_normal (void)
	{
	memset(lcd_str,' ',sizeof(lcd_str));
	strcpy (lcd_str+0,volt_reading);
	sprintf (lcd_str+20,"CH%d Z%d %dNPLC ETH%d",settings.input+1,uzero_enabled[range],nplc_settings[settings.nplc],f_eth_avilable);
	if (keys.up)
		{
		keys.up=0;
		if (range<RANGE_MAX) range++;
		f_range_updated = 1;
		}
	if (keys.down)
		{
		keys.down=0;
		if (range>0) range--;
		f_range_updated = 1;
		}
	if (keys.filter)
		{
		keys.filter = 0;
		main_state = ST_MAIN_FILTER;
		f_disp_update=1;
		}
	if (keys.menu)
		{
		keys.menu = 0;
		main_state = ST_MAIN_MENU;
		f_disp_update=1;
		}
	if (keys.input)
		{
		keys.input=0;
		if (settings.input==0) settings.input = 1;
		else settings.input = 0;
		f_input_changed = 1;
		}
	if (keys.zero)
		{
		keys.zero = 0;
		if (uzero_enabled[range]==0)
			{
			uzero_enabled[range] = 1;
			voltage_uzero[range] = voltage_corr;
			}
		else
			{
			uzero_enabled[range] = 0;
			voltage_uzero[range] = 0.0;
			}
		}
	if (keys.enter)
		{
		keys.enter=0;
		main_state = ST_MAIN_INFO;
		f_disp_update=1;
		}
	if (keys.acal)
		{
		keys.acal = 0;
		main_state = ST_MAIN_ACAL;
		f_disp_update=1;
		}
	}

void main_state_info (void)
	{
	memset(lcd_str,' ',sizeof(lcd_str));
	wizchip_getnetinfo(&netInfo_r);
	if(wizphy_getphylink() == PHY_LINK_ON)
		sprintf(lcd_str,"IP: %d.%d.%d.%d   %s",netInfo_r.ip[0],netInfo_r.ip[1],netInfo_r.ip[2],netInfo_r.ip[3],disp_msg);
	else
		sprintf(lcd_str,"NO ETH LINK      ");
	sprintf (lcd_str+20, "...");
	if (keys.enter)
		{
		keys.enter=0;
		main_state = ST_MAIN_NORMAL;
		f_disp_update=1;
		}
	if (keys.esc)
		{
		keys.esc=0;
		main_state = ST_MAIN_NORMAL;
		f_disp_update=1;
		}
	}

void main_state_menu (void)
	{
	static uint8_t menu_ptr=0, substate_menu=0;
	memset(lcd_str,' ',sizeof(lcd_str));
	sprintf (lcd_str+0, "  %s",menu_items_text[menu_ptr]);
	sprintf (lcd_str+20, "  %d",menu_items_val[menu_ptr]);
	if (substate_menu==0) lcd_str[0]='>';
	if (substate_menu==1) lcd_str[20]='>';
	if (keys.up)
		{
		keys.up=0;
		if (substate_menu==0) if (menu_ptr<(MENU_ITEMS-1)) menu_ptr++;
		if (substate_menu==1) menu_items_val[menu_ptr]++;
		}
	if (keys.down)
		{
		keys.down=0;
		if (substate_menu==0) if (menu_ptr>0) menu_ptr--;
		if (substate_menu==1) menu_items_val[menu_ptr]--;
		}
	if (keys.esc)
		{
		keys.esc=0;
		if (substate_menu==0) main_state=ST_MAIN_NORMAL;
		if (substate_menu==1) substate_menu=0;
		}
	if (keys.enter)
		{
		keys.enter=0;
		if (substate_menu==0) substate_menu=1;
		}
	if (keys.menu)
		{
		keys.menu=0;
		main_state=ST_MAIN_NORMAL;
		settings.autozero = menu_items_val[0];
		settings.digits = menu_items_val[1];
		settings.ac_sampling = menu_items_val[2];
		settings.beep = menu_items_val[3];
		settings.gpib_addr = menu_items_val[4];
		f_eesave_sets = 1;
		adc_update_stat = 1;
		adc_cfg.az = settings.autozero;
		}
	if (menu_items_val[menu_ptr]<menu_items_limit_min[menu_ptr]) menu_items_val[menu_ptr]=menu_items_limit_min[menu_ptr];
	if (menu_items_val[menu_ptr]>menu_items_limit_max[menu_ptr]) menu_items_val[menu_ptr]=menu_items_limit_max[menu_ptr];
	}

void main_state_filter (void)
	{
	static uint8_t substate_filter=0;
	memset(lcd_str,' ',sizeof(lcd_str));
	if (substate_filter==0)
		{
		sprintf (lcd_str+0, "> Analog filter %d",settings.filter_analog);
		sprintf (lcd_str+20,"  Digital filter %d",settings.filter_digital);
		}
	if (substate_filter==1)
		{
		sprintf (lcd_str+0, "  Analog filter %d",settings.filter_analog);
		sprintf (lcd_str+20,"> Digital filter %d",settings.filter_digital);
		}
	if (substate_filter==2)
		{
		sprintf (lcd_str+0, "  Digital filter %d",settings.filter_digital);
		sprintf (lcd_str+20,"> NPLC  %d",nplc_settings[settings.nplc]);
		}
	if (keys.up)
		{
		keys.up=0;
		if (substate_filter==0) settings.filter_analog = 1;
		if (substate_filter==1)
			{
			if (settings.filter_digital==0) settings.filter_digital=1;
			if (settings.filter_digital<64)
				settings.filter_digital = settings.filter_digital*2;
			}
		if (substate_filter==2)
			{
			if (settings.nplc<4) settings.nplc++;
			}
		}
	if (keys.down)
		{
		keys.down=0;
		if (substate_filter==0) settings.filter_analog = 0;
		if (substate_filter==1)
			{
			if (settings.filter_digital>1)
				settings.filter_digital = settings.filter_digital/2;
			}
		if (substate_filter==2)
			{
			if (settings.nplc>0) settings.nplc--;
			}
		}
	if (keys.filter)
		{
		keys.filter = 0;
		if (substate_filter==0) substate_filter=1;
		else if (substate_filter==1) substate_filter=2;
		else if (substate_filter==2)
			{
			substate_filter=0;
			main_state=ST_MAIN_NORMAL;
			adc_cfg.fen = settings.filter_analog;
			adc_cfg.plc = settings.nplc+3;
			adc_update_stat= 1;
			f_eesave_sets = 1;
			}
		f_disp_update=1;
		}
	}

//SPCI helper functions
size_t SCPIWrite(scpi_t * context, const char * data, size_t len)
	{
	char out_str[50];
    (void) context;
	strncpy(out_str,data,len);
	out_str[len]=0;
	send(3, out_str, strlen(out_str));
    return len;
	}

static scpi_result_t EXT_MeasVoltQ(scpi_t * context)
	{
    SCPI_ResultFloat(context, voltage_corr);
	return SCPI_RES_OK;
	}
static scpi_result_t EXT_CalVref(scpi_t * context)
	{
	float param;
	if (!SCPI_ParamFloat(context, &param, TRUE))  return SCPI_RES_ERR;
	calibration_act.VREF_7 = param;
    return SCPI_RES_OK;
	}
static scpi_result_t EXT_CalVrefQ(scpi_t * context)
	{
    SCPI_ResultFloat(context, calibration_act.VREF_7);
	return SCPI_RES_OK;
	}
static scpi_result_t EXT_CalUnl(scpi_t * context)
	{
	int32_t param;
	if (!SCPI_ParamInt32(context, &param, TRUE))  return SCPI_RES_ERR;
	f_cal_unlocked = param;
    return SCPI_RES_OK;
	}
static scpi_result_t EXT_CalSave(scpi_t * context)
	{
	if (f_cal_unlocked) calibration_save(EE_ADDR_CAL1, &calibration_act);
	return SCPI_RES_OK;
	}
static scpi_result_t EXT_CalACAL(scpi_t * context)
	{
	main_state = ST_MAIN_ACAL;
	return SCPI_RES_OK;
	}
static scpi_result_t EXT_SenseChannel(scpi_t * context)
	{
	int32_t param;
	if (!SCPI_ParamInt32(context, &param, TRUE))  return SCPI_RES_ERR;
	settings.input = param-1;
	f_input_changed = 1;
    return SCPI_RES_OK;
	}
static scpi_result_t EXT_SenseChannelQ(scpi_t * context)
	{
    SCPI_ResultInt32(context, settings.input+1);
	return SCPI_RES_OK;
	}
static scpi_result_t EXT_SenseDfil(scpi_t * context)
	{
	int32_t param;
	if (!SCPI_ParamInt32(context, &param, TRUE))  return SCPI_RES_ERR;
	settings.filter_digital = param;
    return SCPI_RES_OK;
	}
static scpi_result_t EXT_SenseDfilQ(scpi_t * context)
	{
    SCPI_ResultInt32(context, settings.filter_analog);
	return SCPI_RES_OK;
	}
static scpi_result_t EXT_SenseAfil(scpi_t * context)
	{
	int32_t param;
	if (!SCPI_ParamInt32(context, &param, TRUE))  return SCPI_RES_ERR;
	settings.filter_digital = param;
    return SCPI_RES_OK;
	}
static scpi_result_t EXT_SenseAfilQ(scpi_t * context)
	{
    SCPI_ResultInt32(context, settings.filter_analog);
	return SCPI_RES_OK;
	}
static scpi_result_t EXT_SenseDigits(scpi_t * context)
	{
	int32_t param;
	if (!SCPI_ParamInt32(context, &param, TRUE))  return SCPI_RES_ERR;
	settings.digits = param;
    return SCPI_RES_OK;
	}
static scpi_result_t EXT_SenseDigitsQ(scpi_t * context)
	{
    SCPI_ResultInt32(context, settings.digits);
	return SCPI_RES_OK;
	}
static scpi_result_t EXT_SenseNPLC(scpi_t * context)
	{
	int32_t param;
	if (!SCPI_ParamInt32(context, &param, TRUE))  return SCPI_RES_ERR;
	settings.nplc = param;
    return SCPI_RES_OK;
	}
static scpi_result_t EXT_SenseNPLCQ(scpi_t * context)
	{
    SCPI_ResultInt32(context, settings.nplc);
	return SCPI_RES_OK;
	}
static scpi_result_t EXT_SenseAZ(scpi_t * context)
	{
	int32_t param;
	if (!SCPI_ParamInt32(context, &param, TRUE))  return SCPI_RES_ERR;
	settings.autozero = param;
    return SCPI_RES_OK;
	}
static scpi_result_t EXT_SenseAZQ(scpi_t * context)
	{
    SCPI_ResultInt32(context, settings.autozero);
	return SCPI_RES_OK;
	}
static scpi_result_t EXT_SystBeep(scpi_t * context)
	{
	int32_t param;
	if (!SCPI_ParamInt32(context, &param, TRUE))  return SCPI_RES_ERR;
	settings.beep = param;
    return SCPI_RES_OK;
	}
static scpi_result_t EXT_SystBeepQ(scpi_t * context)
	{
    SCPI_ResultInt32(context, settings.beep);
	return SCPI_RES_OK;
	}

scpi_command_t scpi_commands[] = {
	{ .pattern = "*IDN?", .callback = SCPI_CoreIdnQ,},
	{ .pattern = "*RST", .callback = SCPI_CoreRst,},
	{ .pattern = "*CLS", .callback = SCPI_CoreCls,},
    { .pattern = "SYSTem:ERRor[:NEXT]?", .callback = SCPI_SystemErrorNextQ,},
    { .pattern = "SYSTem:ERRor:COUNt?", .callback = SCPI_SystemErrorCountQ,},
    { .pattern = "SYSTem:VERSion?", .callback = SCPI_SystemVersionQ,},
	{ .pattern = "MEASure:VOLTage?", .callback = EXT_MeasVoltQ,},
	{ .pattern = "CALibration:VREF", .callback = EXT_CalVref,},
	{ .pattern = "CALibration:VREF?", .callback = EXT_CalVrefQ,},
	{ .pattern = "CALibration:UNLock", .callback = EXT_CalUnl,},
	{ .pattern = "CALibration:SAVe", .callback = EXT_CalSave,},
	{ .pattern = "CALibration:ACAL", .callback = EXT_CalACAL,},
	{ .pattern = "SENSe:CHANnel", .callback = EXT_SenseChannel,},
	{ .pattern = "SENSe:CHANnel?", .callback = EXT_SenseChannelQ,},
	{ .pattern = "SENSe:DFILter", .callback = EXT_SenseDfil,},
	{ .pattern = "SENSe:DFILter?", .callback = EXT_SenseDfilQ,},
	{ .pattern = "SENSe:AFILter", .callback = EXT_SenseAfil,},
	{ .pattern = "SENSe:AFILter?", .callback = EXT_SenseAfilQ,},
	{ .pattern = "SENSe:DIGits", .callback = EXT_SenseDigits,},
	{ .pattern = "SENSe:DIGits?", .callback = EXT_SenseDigitsQ,},
	{ .pattern = "SENSe:NPLC", .callback = EXT_SenseNPLC,},
	{ .pattern = "SENSe:NPLC?", .callback = EXT_SenseNPLCQ,},
	{ .pattern = "SENSe:AZero", .callback = EXT_SenseAZ,},
	{ .pattern = "SENSe:AZero?", .callback = EXT_SenseAZQ,},
	{ .pattern = "SYSTem:BEEPer", .callback = EXT_SystBeep,},
	{ .pattern = "SYSTem:BEEPer?", .callback = EXT_SystBeepQ,},

	SCPI_CMD_LIST_END
};

//SCPI interface
int16_t SCPI_Error(scpi_t * context, int_fast16_t err) {
    (void) context;
	char errmsg[40];
    sprintf(errmsg, "**ERROR: %d, \"%s\"\r\n", (int16_t) err, SCPI_ErrorTranslate(err));
    send(3, errmsg, strlen(errmsg));
    return 0;
}

scpi_interface_t scpi_interface = {
	.write = SCPIWrite,
	.error = SCPI_Error,
	.reset = NULL,
//	.srq = NULL,
};


int main (void)
	{
	hw_init();
	settings_read(EE_ADDR_SETS,&settings);
	calibration_read(EE_ADDR_CAL1, &calibration_act);
	buzzer_init();
	initLCD();
	spi_init();
	uart2_init();
	uart3_init();
	timer_init();
	delay_ms(300);
	pwm_init();
	HI(GPIOA, 1);
	sprintf(lcd_str,"****************************************");
	lcd_update(lcd_str);
	tick_kbd = get_tick();
	adc_cfg.fen=settings.filter_analog;
	adc_cfg.mux = ADC_MUX_IN;
	adc_cfg.gain = ADC_GAIN_1;
	adc_cfg.dac_w = calibration_act.dac_v;
	adc_cfg.dac_c = ADC_DAC_B;
	adc_cfg.plc = settings.nplc+3;
	adc_cfg.re2a = 1;
	adc_cfg.az = settings.autozero;
	adc_update_stat= 1;
	range = 5;
	f_range_updated = 1;
	f_input_changed = 1;

	IO_LIBRARY_Init();
	if(netInfo.dhcp == NETINFO_DHCP)
	{
		DHCP_init(SOCK_DHCPC, gDATABUF_DHCP);
		reg_dhcp_cbfunc(my_ip_assign, my_ip_assign, my_ip_conflict);
	}
	SCPI_Init(&scpi_context,
		scpi_commands,
		&scpi_interface,
		scpi_units_def,
		SCPI_IDN1, SCPI_IDN2, SCPI_IDN3, SCPI_IDN4,
		scpi_input_buffer, SCPI_INPUT_BUFFER_LENGTH,
		scpi_error_queue_data, SCPI_ERROR_QUEUE_SIZE);

	while (1)
		{
		if(run_user_applications)
			{
			telnet_srv(3, ethBut3_TELNET, TELNET_PORT);
			telnet_auth_srv(4, ethBut4_TELNET, TELNET_AUTH_PORT);
			loopback_tcps(0,ethBuf0,5025);
			loopback_udps(1, ethBuf0, 3000);
			}
    	if(netInfo.dhcp == NETINFO_DHCP)
    		{
			switch(DHCP_run())
				{
				case DHCP_IP_ASSIGN:
				case DHCP_IP_CHANGED:
					break;
				case DHCP_IP_LEASED:
					run_user_applications = 1;
					break;
				case DHCP_FAILED:
					my_dhcp_retry++;
					if(my_dhcp_retry > MY_MAX_DHCP_RETRY)
					{
						netInfo.dhcp = NETINFO_STATIC;
						DHCP_stop();      // if restart, recall DHCP_init()
						IO_LIBRARY_Init(); //After that ping must working
						my_dhcp_retry = 0;
						run_user_applications = 1;
					}
					break;
				default:
					break;
				}
    		}
    	if ((uint16_t)(get_tick()-tick_eth)>INT_ETH)
    		{
    		tick_eth = get_tick();
        	DHCP_time_handler();
    		check_network_information();
    		}

		keyboard_task();
		adc_task();
		psu_task();
		eeprom_task();
		if (f_disp_update)
			{
			f_disp_update=0;
			HI(GPIOE, 5);
			lcd_update(lcd_str);
			LO(GPIOE, 5);
			}
		if (f_range_updated)
			{
			f_range_updated = 0;
			adc_update_stat = 1;
			if (range==0)
				{
				adc_cfg.mux = ADC_MUX_AMP;
				adc_cfg.gain = ADC_GAIN_100;
				adc_cfg.re2b = 1;
				}
			if (range==1)
				{
				adc_cfg.mux = ADC_MUX_AMP;
				adc_cfg.gain = ADC_GAIN_10;
				adc_cfg.re2b = 1;
				}
			if (range==2)
				{
				adc_cfg.mux = ADC_MUX_AMP;
				adc_cfg.gain = ADC_GAIN_1;
				adc_cfg.re2b = 1;
				}
			if (range==3)
				{
				adc_cfg.mux = ADC_MUX_IN;
				adc_cfg.gain = ADC_GAIN_100;
				adc_cfg.re2a = 1;
				}
			if (range==4)
				{
				adc_cfg.mux = ADC_MUX_IN;
				adc_cfg.gain = ADC_GAIN_10;
				adc_cfg.re2a = 1;
				}
			if (range==5)
				{
				adc_cfg.mux = ADC_MUX_IN;
				adc_cfg.gain = ADC_GAIN_1;
				adc_cfg.re2a = 1;
				}
			}
		if (f_input_changed)
			{
			f_input_changed = 0;
			if (settings.input==0) adc_cfg.re1b = 1;
			if (settings.input==1) adc_cfg.re1a = 1;
			adc_update_stat = 1;
			}

		if ((f_vol_newval!=0)&(main_state!=ST_MAIN_ACAL))
			{
			f_vol_newval=0;
			voltage_display = voltage_corr;
			if (uzero_enabled[range]) voltage_display = voltage_display - voltage_uzero[range];
			if (range==5) sprintf(volt_reading,"%+09.5f V R:10V",voltage_display*1.0);
			if (range==4) sprintf(volt_reading,"%+09.6f V R:1V",voltage_display*1.0);
			if (range==3) sprintf(volt_reading,"%+09.4fmV R:100mV",voltage_display*1000.0);
			if (range==2) sprintf(volt_reading,"%+09.5fmV R:10mV",voltage_display*1000.0);
			if (range==1) sprintf(volt_reading,"%+09.6fmV R:1mV",voltage_display*1000.0);
			if (range==0) sprintf(volt_reading,"%+09.4fuV R:100uV",voltage_display*1000000.0);
//			uart3_send_str(volt_reading);
//			uart3_send_str("\n");
			f_disp_update = 1;
			}
		if (keys.INT16!=0) f_disp_update=1;
		if (main_state==ST_MAIN_NORMAL) main_state_normal();
		if (main_state==ST_MAIN_FILTER) main_state_filter();
		if (main_state==ST_MAIN_ACAL) main_state_acal();
		if (main_state==ST_MAIN_MENU) main_state_menu();
		if (main_state==ST_MAIN_INFO) main_state_info();
		if (keys.INT16!=0) keys.INT16=0;
		}
	}

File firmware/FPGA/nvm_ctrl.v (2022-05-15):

//sudo rmmod ftdi_sio

module nvm_ctrl(
	CLK_32M,
	RESET,
	LED,LED2,DEBUG_TP1,DEBUG_TP2,DEBUG_TP3,
	SW_P, SW_N, SW_IN,
	AD_ACS,AD_ADO,AD_ACLK,
	COMP_IN,UART_RX,CON_START,
	UART_TX, CLK_OUT,
	RE3,RE4,RE1A,RE1B,RE2A,RE2B,MAG1,MAG10,MAG100,
	MS_A0,MS_A1,MS_A2,FEN_A,FEN_B,FEN_C,
	JA_DOUT,JA_DIN,JA_COMP,JA_C1,JA_C2,JA_C3,JA_SCK,JA_CS,
	AZ_SW, PW1, PW2, SU_A, SU_B
);
/*
39 - FC9 - AD_DI (unused)
42 - FC6 - ADACS
41 - FC5 - ADADO
40 - FC0 - ADACLK
51 - FC4 - COMP
52 - FC1 - S1 - INT_VP_GND/INT_VP_ACT
53 - FC2 - S2 - INT_IN_GND/INT_IN_ACT
54 - FC3 - S3 - INT_VN_GND/INT_VN_ACT
1 - FC10 - RE3
2 - FC11 - RE4
3 - FC12 - R1A
8 - FC13 - R1B
9 - FC14 - R2A
10 - FC15 - R2B
75 - FC16 - MAG1
71 - FC17 - MAG10
69 - FC18 - MAG100
74 - FC19 - MS_A2
70 - FC20 - MS_A1
68 - FC21 - MS_A0
66 - FC22 - JA_DOUT
64 - FC23 - JA_DIN
62 - FC24 - JA_COMP
67 - FC25 - JA_C1
65 - FC26 - JA_C2
63 - FC27 - JA_C3
61 - FC28 - JA_CS
60 - FC29 - JA_SCK
59 - FC30 - FEN_A
57 - FC31 - FEN_B
58 - FC32 - FEN_C
*/





input  CLK_32M,COMP_IN,UART_RX,CON_START,RESET;
output LED,LED2,SW_P,SW_N,SW_IN,UART_TX;
output DEBUG_TP1,DEBUG_TP2,DEBUG_TP3;
output AD_ACS,AD_ACLK,CLK_OUT;
input AD_ADO;
output RE3,RE4,RE1A,RE1B,RE2A,RE2B,MAG1,MAG10,MAG100;
output MS_A0,MS_A1,MS_A2,FEN_A,FEN_B,FEN_C;
input JA_DOUT,JA_COMP;
output JA_C1,JA_C2,JA_C3,JA_SCK,JA_CS,JA_DIN;
output AZ_SW, PW1, PW2, SU_A, SU_B;


reg led_r,sw_in_r,sw_p_r, sw_n_r;
reg comp_in_r,comp_in_ff,ad_ado_ff,ad_ado_r,con_start_ff,con_start_r;
reg ad_acs_r,ad_aclk_r;
reg reset_in_r,reset_in_ff;
reg debug_A,debug_B;
reg [20:0] cnt_msm;
reg [20:0] cnt_ic;
reg [20:0] cnt_ic_set;
reg [20:0] cnt_ic_pos;
reg [20:0] cnt_ic_neg;
reg [15:0] adc_res;
reg [4:0] main_state;
reg [6:0] spi_cnt;

reg uart_tx_start, uart_frame_start,uart_rx_rst;
reg [2:0] uart_frame_state,uart_frame_r;
reg [3:0] uart_frame_cnt;
wire uart_busy,uart_tx_bit_clock,uart_rx_bit_clock,uart_rx_ready;
reg [47:0] frame_content;
reg [47:0] result_content;
reg [31:0] uart_rx_frame;
reg [7:0] uart_tx_register;
reg [2:0] uart_rx_state;
wire [7:0] uart_rx_register;
reg[5:0] uart_divider;
reg[2:0] uart_rx_cnt;
reg[5:0] uart_prediv;
reg cal_en;
reg az_state, az_switch;

reg [4:0] adc_chrg_cnt;
reg [4:0] adc_chrg;
reg [10:0] adc_chrg_acc;
reg adc_chrg_pol,adc_chrg_force,sw_final;
reg cstart_slow, cstart_slow_sync;
reg [2:0] uart_rx_state;
reg dac_update;
reg [2:0] dac_state;
reg [7:0] dac_cnt;
reg [15:0] dac_word;
reg [15:0] dac_div;
reg dac_clk_r,dac_do_r,dac_cs_r,su_a_r,su_b_r;
reg [32:0] startup_cnt;

/*
always @(posedge CLK_32M)
	begin
	cnt_msm <= cnt_msm + 1;
	if (cnt_msm==2000)
		begin
		cnt_msm <= 0;
		cnt_ic  <= cnt_ic + 1;
		led_r <= ~ led_r;
		if (cnt_ic[0]==0)
			begin
			sw_p_r <= 0;
			sw_n_r <= 1;
			end
		else
			begin
			sw_p_r <= 1;
			sw_n_r <= 0;
			end			
		end
	end
*/



always @(posedge CLK_32M)
begin
	reset_in_ff <= RESET;
	reset_in_r <= reset_in_ff;
	if (reset_in_r==0) 
		begin
		startup_cnt<=0;
		end
	else
		begin
		if (startup_cnt>=10000000*32)
			su_a_r<=1;
		else
			su_a_r<=0;
		if (startup_cnt>=13000000*32)
			su_b_r<=1;
		else
			su_b_r<=0;
		if (startup_cnt<13000001*32)
			begin
			startup_cnt<=startup_cnt+1;
			end
		end
	
	
end

always @(posedge CLK_32M)
begin
	cstart_slow_sync <= CON_START;
	cstart_slow <= cstart_slow_sync;
	if (main_state==11)
		begin
		uart_rx_cnt<=0;
		dac_update<=0;
		end
	if (uart_rx_state==0)
		begin
		if (uart_rx_ready==1)
			begin
			//do something with rx data
			if (uart_rx_cnt==0)
				uart_rx_frame[7:0] <= uart_rx_register;
			if (uart_rx_cnt==1)
				uart_rx_frame[15:8] <= uart_rx_register;
			if (uart_rx_cnt==2)
				uart_rx_frame[23:16] <= uart_rx_register;
			if (uart_rx_cnt==3)
				begin
				uart_rx_frame[31:24] <= uart_rx_register;
				dac_update<=1;
				end
			uart_rx_state<=1;
			end
		end
	if (uart_rx_state==1)
		begin
		uart_rx_rst<=1;
		uart_rx_cnt<=uart_rx_cnt+1;
		uart_rx_state<=2;
		end
	if (uart_rx_state==2)
		begin
		if (uart_rx_ready==0)
			begin
			uart_rx_rst<=0;
			uart_rx_state<=0;
			end
		end
	if (dac_update==1)
		begin
		dac_word[15:8] <= uart_rx_frame[31:24];
		dac_word[7:2] <= uart_rx_frame[23:18];
		dac_word[1:0] <= 0;
		dac_state<=1;
		dac_cs_r <= 0;
		end
	if (dac_state==0)
		begin
		dac_cs_r <= 1;
		end
	if (dac_state==1)
		begin
		dac_update<=0;
		dac_cnt<=0;
		dac_state<=2;
		end
	if (dac_state==2)
		begin
		dac_div<=10;
		if (dac_cnt[0]==0)
			begin
			dac_do_r<= dac_word[15];
			dac_clk_r<=0;
			end
		if (dac_cnt[0]==1)
			begin
			dac_word[15:1]<=dac_word[14:0];
			dac_clk_r<=1;			
			end
		if (dac_cnt==32)
			begin
			dac_div<=10;
			dac_state<=4;
			end
		else
			begin
			dac_state<=3;
			dac_cnt<=dac_cnt+1;
			end
		end
	if (dac_state==3)
		begin
		dac_div<=dac_div-1;
		if (dac_div==0)
			dac_state<=2;
		end
	if (dac_state==4)
		begin
		dac_div<=dac_div-1;
		if (dac_div==0)
			dac_state<=0;
		end
		
end
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

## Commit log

2022-05-16 BOM moved into correct directory, readme update
    [rnvm_meggie.csv]
2022-05-19 added test data
    [noise_long_term.ods, noise_shield.ods, noise_short_term.ods]
2022-05-19 added measurement data
    [noise_long_term.ods, noise_shield.ods, noise_short_term.ods]
